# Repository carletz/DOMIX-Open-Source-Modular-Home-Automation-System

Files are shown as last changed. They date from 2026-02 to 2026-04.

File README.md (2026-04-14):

<div align="center">
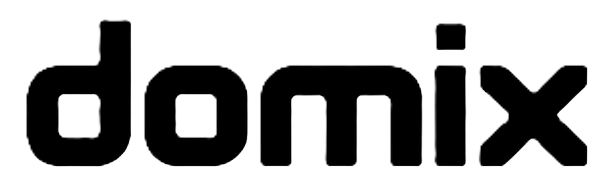
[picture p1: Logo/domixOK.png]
    
</div>

# DOMIX - Open Source Modular Home Automation System

## 📋 Table of Contents

- [Introduction](#-introduction)
- [The DOMIX Manifesto](#-the-domix-manifesto)
- [System Architecture](#-system-architecture)
- [Available Modules](#-available-modules)
- [PCB Composition](#-pcb-composition)
- [Technical Specifications](#-technical-specifications)
- [Getting Started](#-getting-started)
- [DOMIX ESPHome Software](#-domix-esphome-software)
- [Comparison with Other Systems](#-comparison-with-other-systems)
- [License & Disclaimer](#-license--disclaimer)
- [Documentation, Contributing, Contact & Acknowledgments](#-documentation)

---
> [!NOTE]
> **Please read the Full Technical Manual:** [Technical Documentation PDF](/Docs/DOMIX_Technical_Documentation_EN.pdf) to understand the project's full potential and features, below is just a summary of the project's features.
> 
> **Oshwlab Stars 2026 Page:** [DOMIX](https://oshwlab.com/carletz.slug/domix-domotic-module-for-smart-home-co)
---

## 🎯 Introduction

For several years, I have been managing the equipment in my home using automated systems that report all necessary information to a central controller, both for operational control and for data analysis.

These tools have only recently evolved, perhaps a decade or so for the consumer sector. Logic controllers, on the other hand, have been around for decades, but I don't think they'll easily become usable by a simple enthusiast like me, both due to their cost and their architecture.

As I've evolved my systems day by day, I've realized—unfortunately, too late, given that the learning curve for self-taught software is always very steep—that the best system, in my opinion, is always a centralized one.
After experimenting with both centralized and distributed approaches, the conclusion is clear: having everything converges into a single control point offers decisive advantages.

Many commercial solutions offer hybrid approaches, but excluding well-known and expensive systems, I could not find a simple solution capable of offering everything within a single device. From this need, the DOMIX project was born combining prior experience in electronics and automation into a single coherent ecosystem.

The idea is to concentrate the control logic inside a dedicated electrical cabinet, interfacing with actuators and safety switches belonging to the main electrical panel. This cabinet is not a conventional electrical panel, but a control cabinet designed to host automation logic and low-voltage control devices. The electrical power panel is not part of the DOMIX project; it relies on qualified electricians to connect the DOMIX system to the real world.

Yes, I know what you're thinking: who knows how many wires I have to run in my house! Or: how can I modify an existing system now? Well, I agree with you, this system is ideal if you're starting from scratch. If I don't yet have any conduit or corrugated pipes inside my walls, that's true, but in my opinion, even on a small scale, it can be adapted to many situations. On the other hand, imagination is a big part of the job of those who start thinking up similar systems on their own.

By centralizing all control wiring—both inputs (buttons, switches) and outputs (actuators, relays, contactors)—the system remains organized, flexible, and ready for complex logic and future expansion.

### Key Features

DOMIX is an **open-source, modular, DIN-rail home automation system** designed for centralized control and monitoring. Born from years of personal experience with home automation, DOMIX combines the structured approach of industrial systems with the flexibility of DIY platforms.

- ✅ Fully modular DIN-rail design
- ✅ Centralized logic with decentralized I/O
- ✅ Native Ethernet + Zigbee support
- ✅ ESPHome-based programming
- ✅ Open hardware & software
- ✅ No vendor lock-in
- ✅ Low-voltage safety (12V DC max)

## 📜 The DOMIX Manifesto

DOMIX is built on **10 core principles**:

1. **Open by Design** - All schematics and documentation are open source
2. **No Competition with Industrial Systems** - Research platform, not certified product
3. **Research, Not Certification** - Built for learning and experimentation
4. **Modular or Nothing** - Only M1 is mandatory, everything else is optional
5. **Cabinet-Oriented, Low-Voltage Only** - Never drives power loads directly
6. **Ethernet First, Always** - Wired reliability over wireless dependency
7. **Open Ecosystem Integration** - Works with Home Assistant, ESPHome, MQTT
8. **Zigbee as a First-Class Citizen** - Native Zigbee coordinator capability
9. **Fully Customizable by Design** - Firmware and logic can be freely modified
10. **Built for People Who Want to Understand** - Transparency over abstraction

> [!IMPORTANT]
> **DOMIX exists because building things is still fun. If it teaches something, it has succeeded.**

## 🏗️ System Architecture

<div align="center">
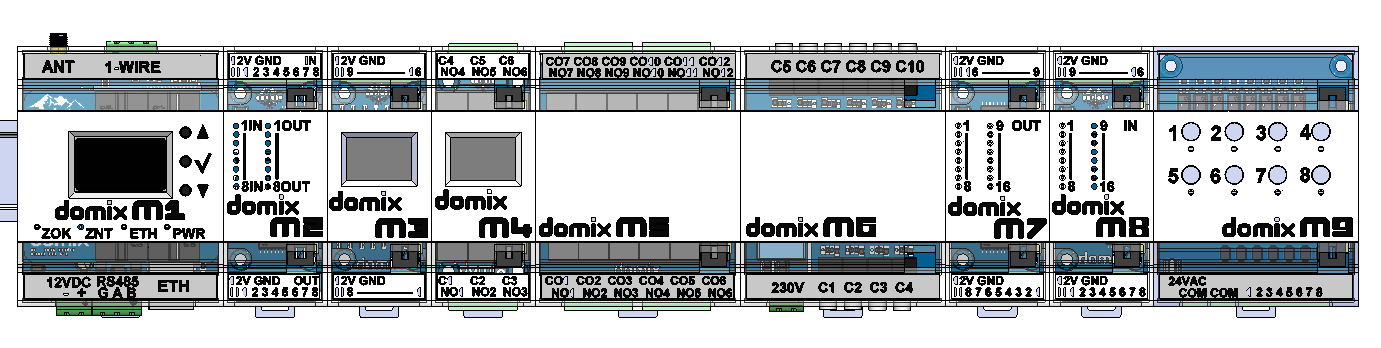
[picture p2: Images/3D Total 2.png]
    
</div>

### Modular Design

DOMIX uses a **centralized core (M1)** with specialized I/O expansion modules connected via **I2C bus**. All modules mount on standard 35mm DIN rail.

### Connection System

- **Power & Data:** 8-pin IDC flat cables
- **I2C Bus:** Two independent buses (expandable to 8 with M1 v1.1)
- **Communications:** Ethernet (primary), Zigbee, RS485

### I2C Address Management

The system carefully manages I2C address space across three ranges:

| Range | Used For | Max Devices |
|---|---|---|
| 0x20–0x27 | PCA9554A, PCA9535 | 8 |
| 0x38–0x3F | PCA9554A, PCF8574, PCA9535 | 8 |
| 0x48–0x4B | ADS1115 (ADC) | 4 |

## 🧩 Available Modules

### Core Module

| Module | Function | DIN Width | Description |
|---|---|---|---|
| **M1** | Core/Gateway | 4 modules | ESP32-S3, Ethernet, Zigbee, RS485, I2C hub |

<div align="center">
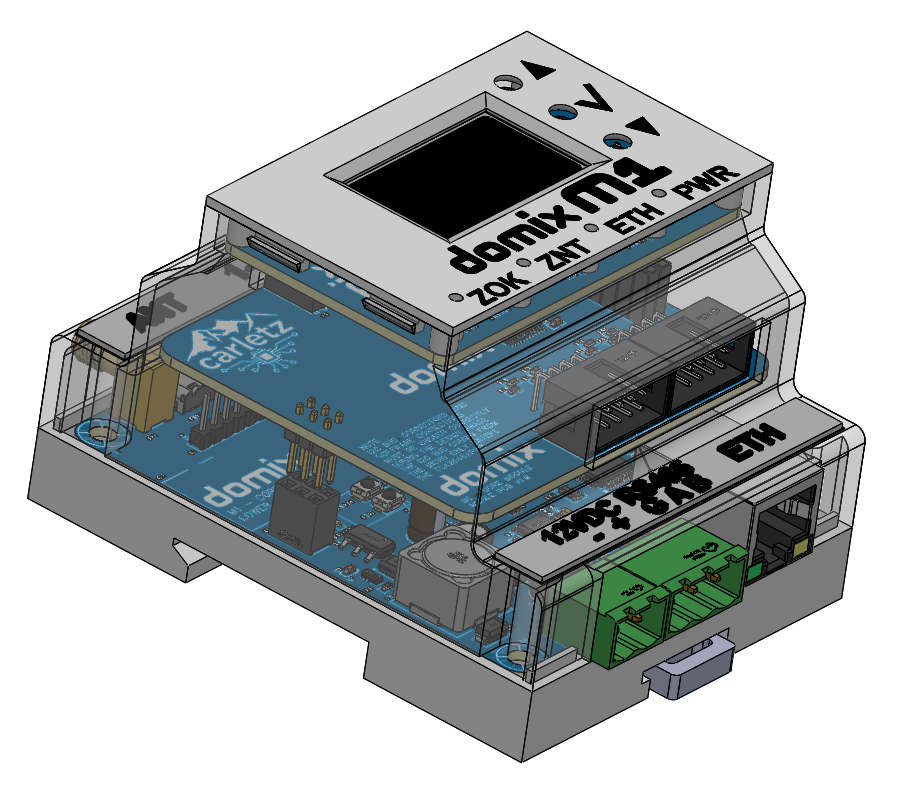
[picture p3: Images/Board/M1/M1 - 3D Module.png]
    
</div>

### I/O Modules

| Module | Function | DIN Width | I/O Count | Description |
|---|---|---|---|---|
| **M2** | General I/O | 2 modules | 8 in / 8 out | Optocoupled inputs, Darlington outputs |
| **M3** | Door/Window Contacts | 2 modules | 16 analog in | Analog multiplexer for reed switches |
| **M7** | Digital Output | 2 modules | 16 out | General purpose 12V outputs |
| **M8** | Digital Input | 2 modules | 16 in | General purpose optocoupled inputs |

<div align="center">
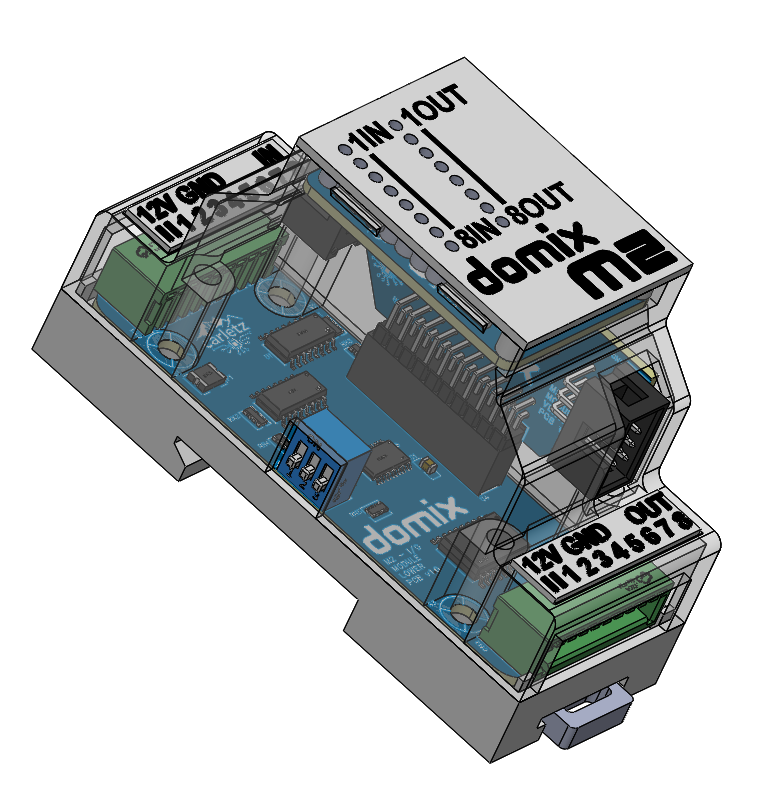
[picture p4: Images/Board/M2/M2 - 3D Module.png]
    
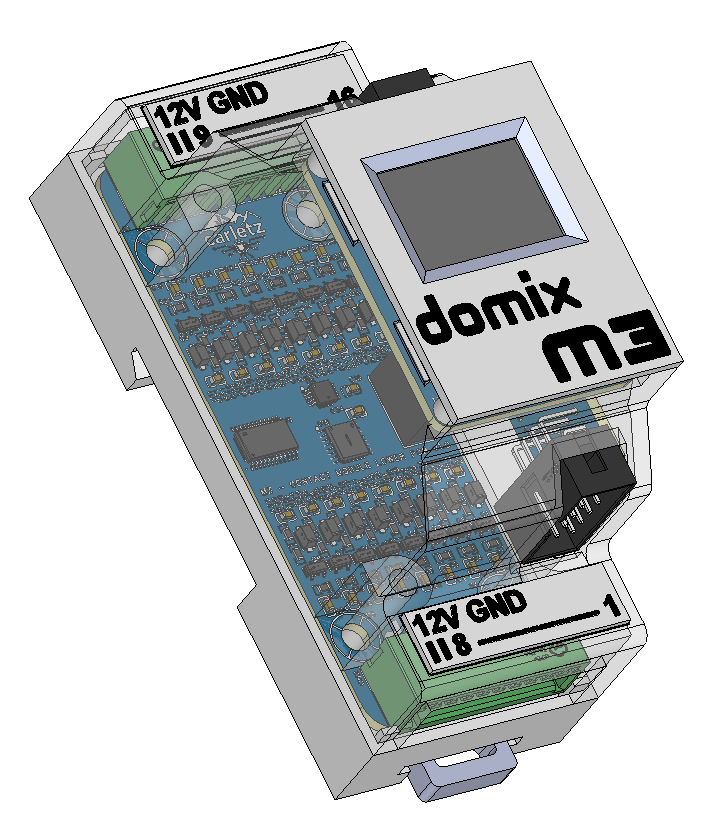
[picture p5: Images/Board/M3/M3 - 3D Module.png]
    
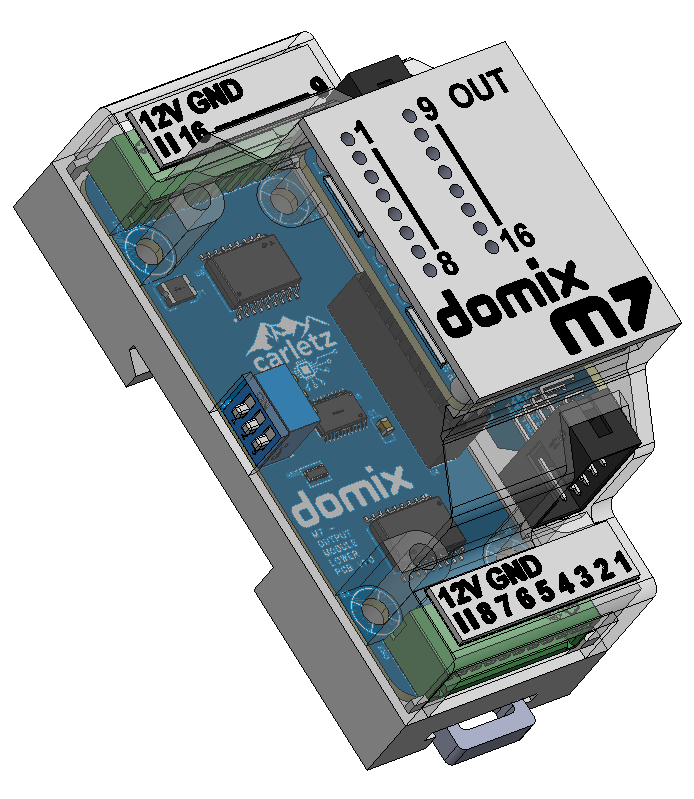
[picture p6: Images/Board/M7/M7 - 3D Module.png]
    
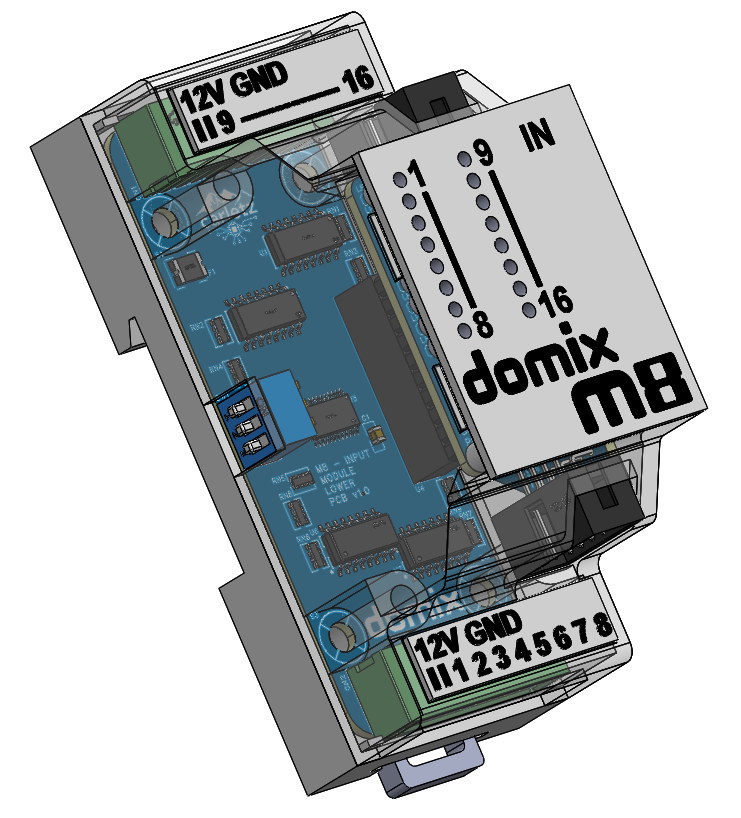
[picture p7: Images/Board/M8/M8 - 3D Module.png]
    
</div>

### Relay Modules

| Module | Function | DIN Width | Relays | Description |
|---|---|---|---|---|
| **M4** | 6-Relay | 2 modules | 6 | 10A @ 250VAC relays |
| **M5** | 12-Relay | 4 modules | 12 | 10A @ 250VAC relays |

<div align="center">
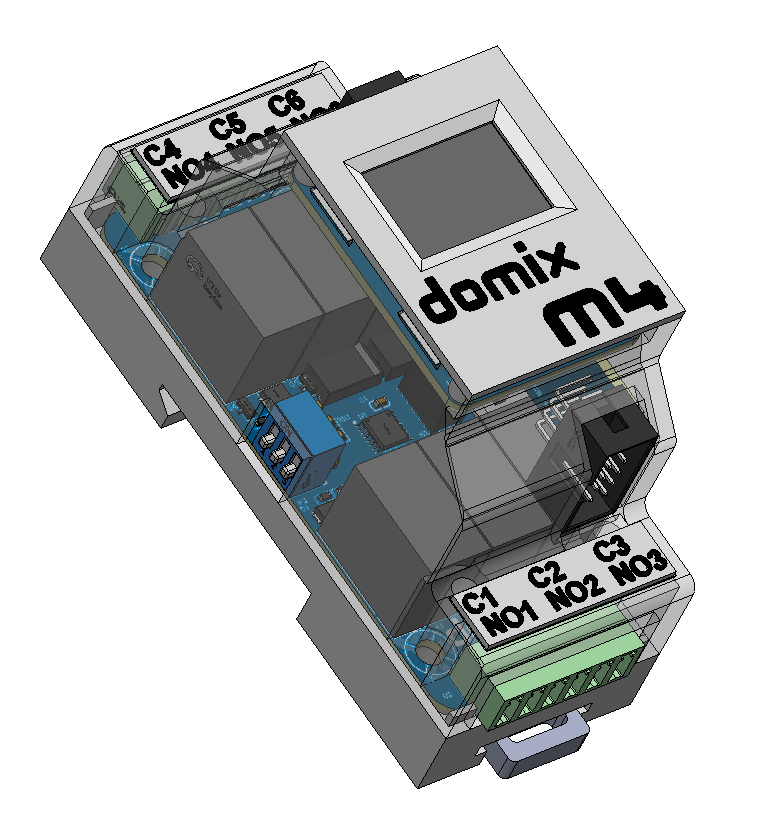
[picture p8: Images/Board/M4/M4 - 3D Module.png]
    
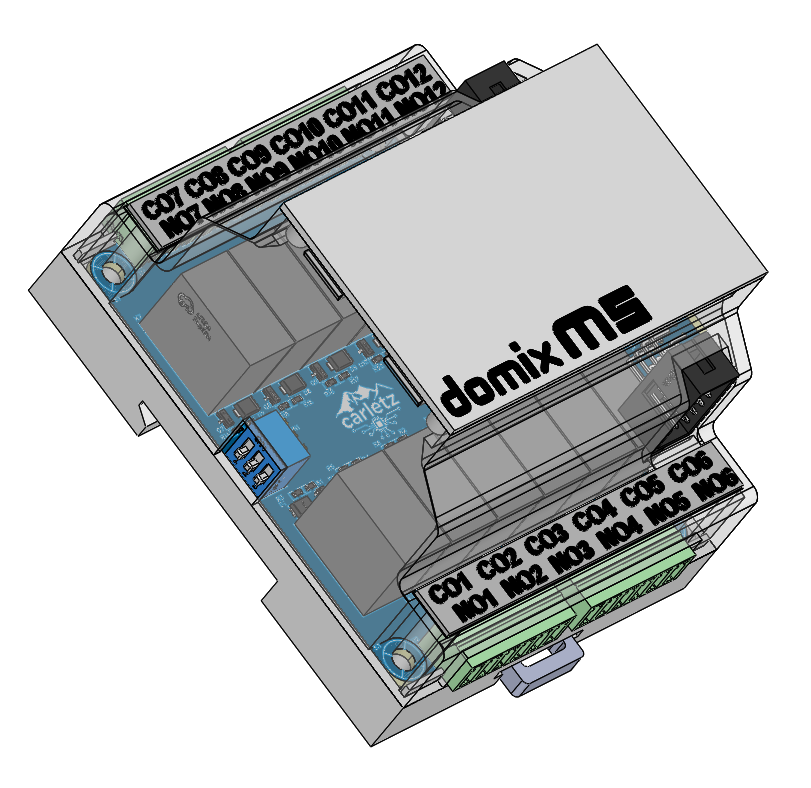
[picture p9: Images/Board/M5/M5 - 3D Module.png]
    
</div>

### Specialized Modules

| Module | Function | DIN Width | Description |
|---|---|---|---|
| **M6** | Energy Meter | 4 modules | 10-channel current clamp meter |
| **M9** | Sprinkler Controller | 4 modules | 8-zone sprinkler control with 24VAC output |

<div align="center">
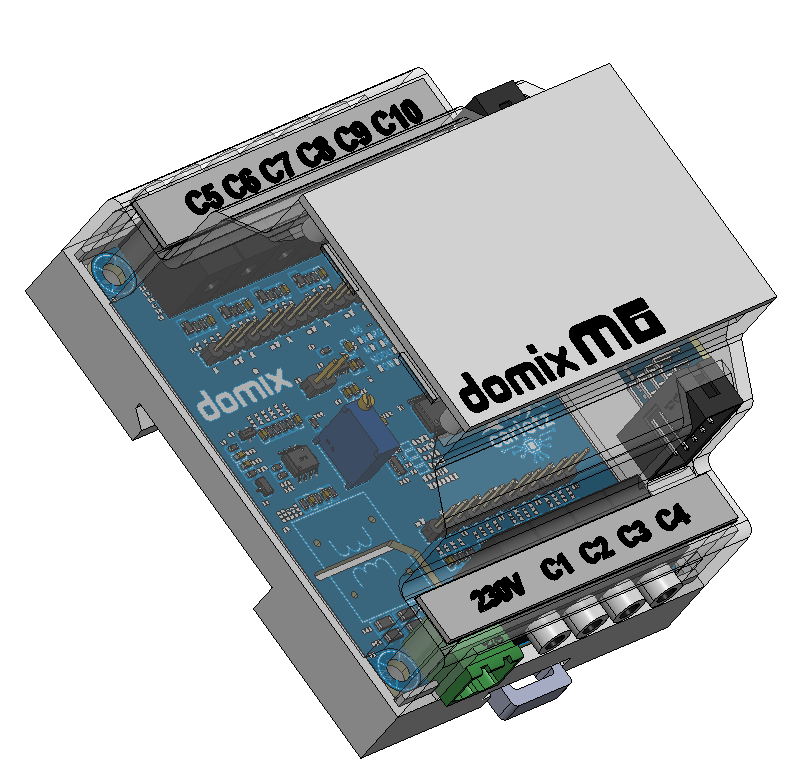
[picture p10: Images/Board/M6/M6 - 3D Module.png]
    
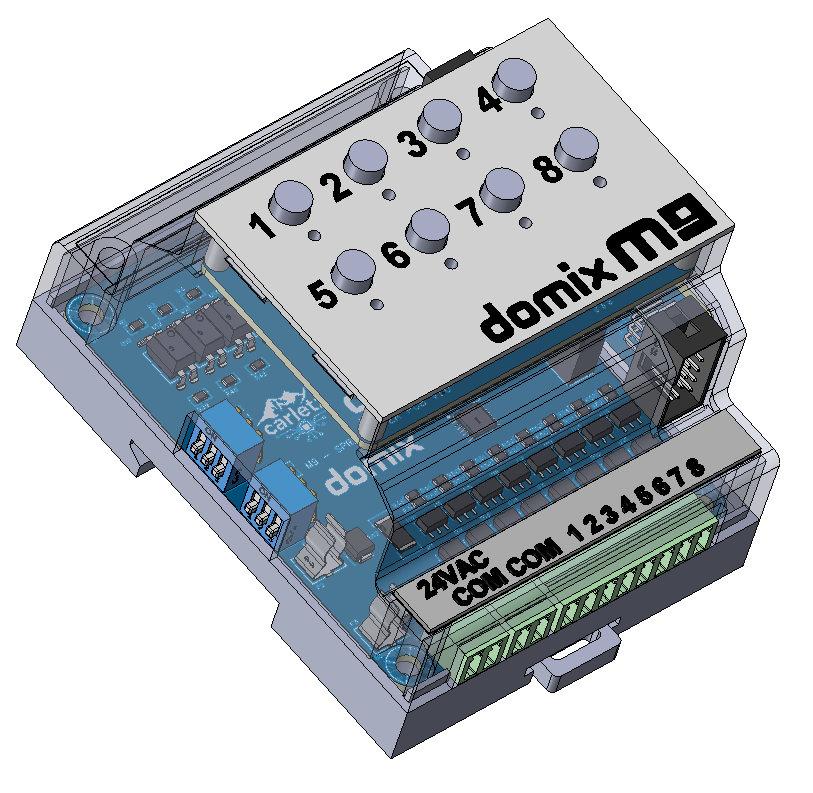
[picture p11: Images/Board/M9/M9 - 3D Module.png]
    
</div>

### Sensor Modules

The DOMIX sensor family consists of a shared **S Core board** combined with interchangeable **sensor daughter boards** designed for different installation scenarios and use cases. The S Core is always required and is identical across all configurations; only the daughter board and the 3D-printed enclosure change. Not all sensors need to be populated on any given board — every component is independently optional and the final build is entirely up to the user.

There are four possible configurations arising from two independent choices: installation type (ceiling or wall 503-box) and sensor/interface trade-off within each form factor.

| Configuration | Installation | LD2410C | PIR | BME280 | SCD41 | SGP41 | BH1750 | OLED + Encoder | IR TX | IR RX |
|---|---|:---:|:---:|:---:|:---:|:---:|:---:|:---:|:---:|:---:|
| **S Core + S1a** | Ceiling – mmWave | ✓ | – | ✓ | ✓ | ✓ | ✓ | – | ✓ | ✓ |
| **S Core + S1b** | Ceiling – PIR | – | ✓ | ✓ | ✓ | ✓ | ✓ | – | ✓ | ✓ |
| **S Core + S2a** | Wall 503 – Display | ✓ | – | ✓ | – | ✓ | – | ✓ | – | ✓ |
| **S Core + S2b** | Wall 503 – Sensors | ✓ | – | ✓ | ✓ | ✓ | ✓ | – | – | ✓ |

✓ = included in this variant &nbsp;&nbsp; – = not available in this variant

<div align="center">
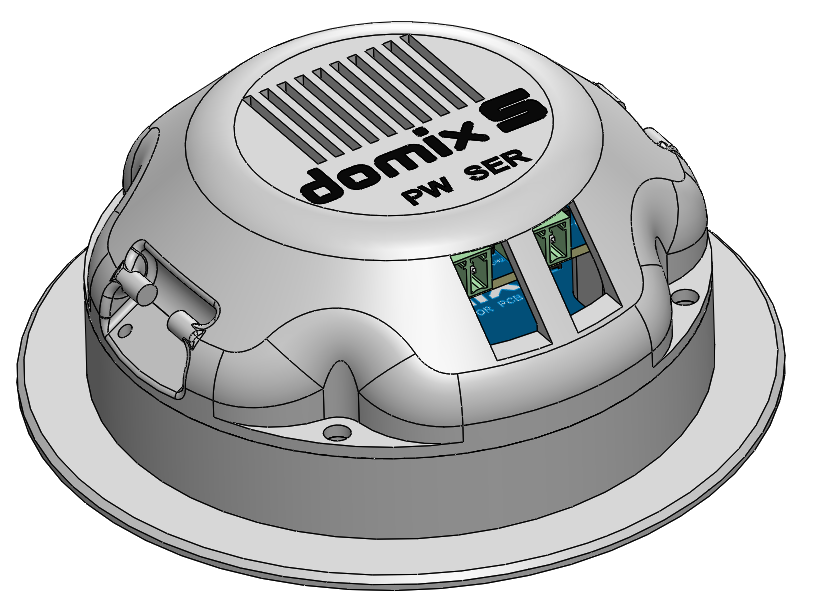
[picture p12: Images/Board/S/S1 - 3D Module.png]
    
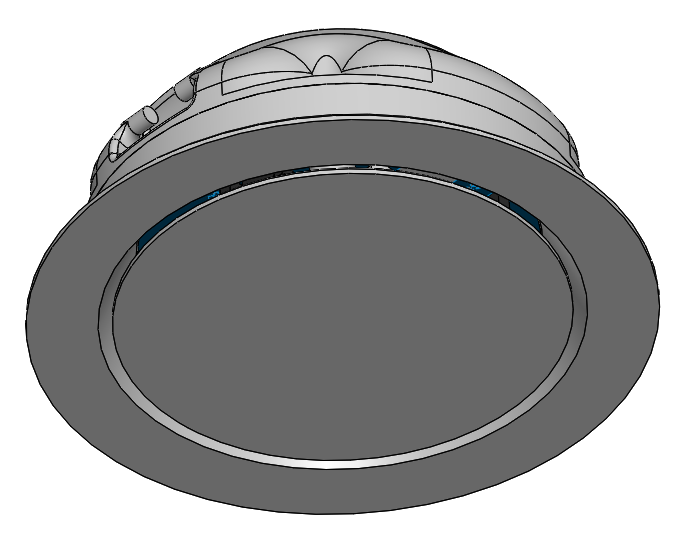
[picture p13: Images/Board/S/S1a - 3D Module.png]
        
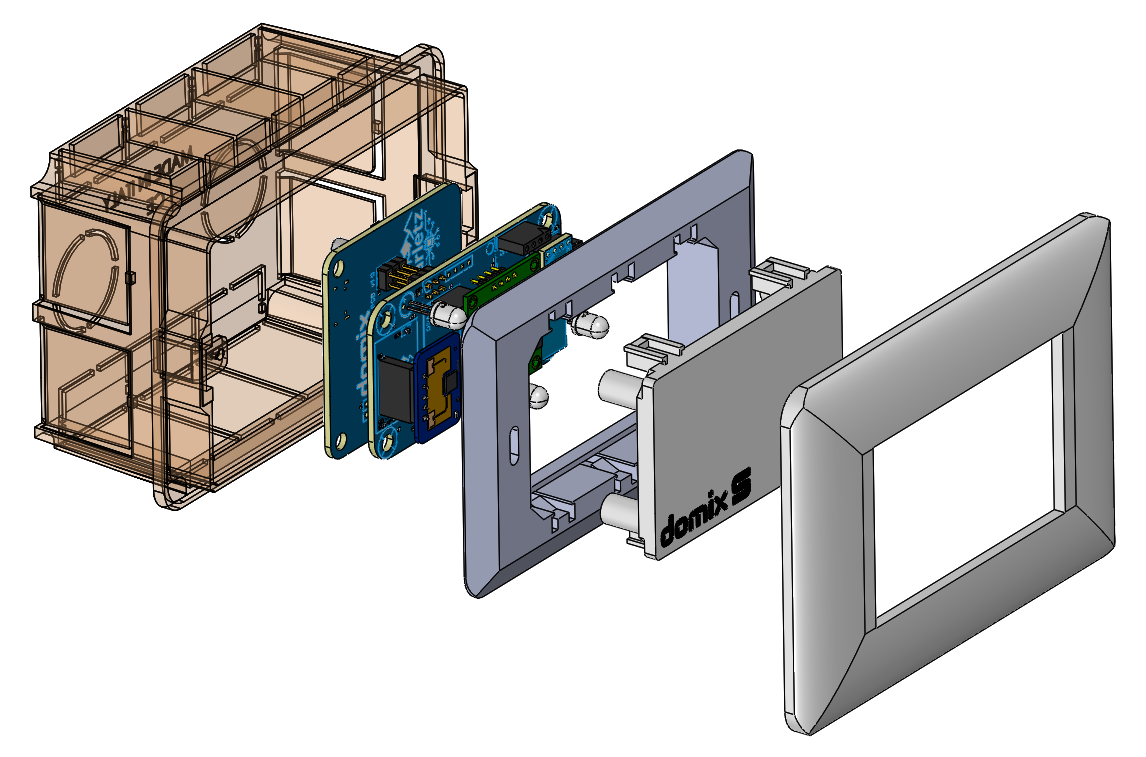
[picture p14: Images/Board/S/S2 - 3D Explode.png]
    
</div>

**Choosing the right variant:**
- **S1a / S2a (mmWave)** — best for living rooms and bedrooms where detecting stationary presence matters (e.g. someone sitting and reading). The LD2410C radar detects static occupancy reliably where PIR cannot.
- **S1b (PIR)** — simpler and lower cost, adequate for corridors, entrances, or secondary rooms where motion detection is sufficient.
- **S2a (Display)** — ideal when local interaction is needed, such as a wall-mounted thermostat or a room controller with manual input via the rotary encoder. Trades SCD41 and BH1750 for the OLED + encoder interface.
- **S2b (Sensors)** — best for rooms where air quality monitoring is the priority (bedroom, home office, kitchen): adds CO₂ (SCD41) and light (BH1750) on top of temperature, humidity, and VOC.

All configurations share the same S Core: RP2040 microcontroller, USB-C programming, 12V power input, and RS485 communication back to the DOMIX M1.

## 🧱 PCB Composition

Each DOMIX module is not a single PCB but a **stack of multiple boards** that snap together via IDC flat cables. Understanding which boards make up each module helps you know what to order, build, and assemble.

The boards are divided into three roles:

- **Vertical Module** — carries power and I2C bus connectors.
- **Display Module** — an optional front-facing board with the OLED screen and encoder/button interface.
- **Functional Module** — the core board specific to each module's purpose (I/O, relay, energy metering, etc.).

Some boards are shared between multiple module numbers to reduce design complexity and PCB variants.

### Cabinet Modules (M-series)

| Module | Vertical | Display | Functional Board(s) | Notes |
|---|---|---|---|---|
| **M1** | Middle Module v1.0 + v1.1 | Display Module | Core Module | Middle module acts as mid-layer between core and vertical; v1.1 adds second I2C multiplexer |
| **M2** | Vertical Module | Display Module | I-O Module | 8 in / 8 out general I/O |
| **M3** | Vertical Module | Display Module | Contact Module | 16-channel analog contact reader |
| **M4** | *(shared M3-4)* | *(shared M3-4)* | 6 Relay Module | Vertical and display boards are shared with M3 |
| **M5** | *(shared M3-4-5-6)* | *(shared M5-6)* | 12 Relay Module | Vertical shared across M3/M4/M5/M6; display shared with M6 |
| **M6** | *(shared M3-4-5-6)* | *(shared M5-6)* | Energy Meter Module | Same vertical and display as M5 |
| **M7** | Vertical Module | Display Module | Output Module | 16 digital outputs |
| **M8** | Vertical Module | Display Module | I-O Module | 16 digital inputs (same I-O board as M2, different config) |
| **M9** | Vertical Module | Upper Module | Sprinkler Module | Upper Module replaces the display, handles 24VAC switching |

> **Shared boards explained:** The label `M3-4` on a board means that PCB is used in both M3 and M4. Similarly `M3-4-5-6` is a single vertical design that fits M3 through M6, and `M5-6` is a display shared between M5 and M6. This reduces the number of unique PCB designs without limiting functionality.

### Sensor Modules (S-series)

The sensor family follows a **core + daughter board** approach. The S Core is always present; the S1 or S2 board changes depending on installation type.

| Board | Role | Description |
|---|---|---|
| **S Core** | Main board | RP2040 MCU, RS485, USB-C, 12V input — identical in every sensor node |
| **S1** | Daughter board | Ceiling form factor — fits LD2410C (mmWave) or PIR depending on variant |
| **S2** | Daughter board | Wall 503-box form factor — fits OLED+encoder or additional sensors depending on variant |

Each sensor node = **1× S Core + 1× S1 or S2 daughter board**, housed in a dedicated 3D-printed enclosure.

## 🔧 Technical Specifications

### M1 Core Module

- **MCU:** ESP32-S3-WROOM-1-N8R2 (dual-core, Wi-Fi, USB-C)
- **Ethernet:** W5500 controller, 10/100 Mbps
- **Zigbee:** RF-BM-2652P2 (TI CC2652, external antenna)
- **RS485:** MAX13487E transceiver with TVS protection
- **Power:** 9-12V DC input, 5V/3.3V internal rails
- **I2C:** 2 buses (expandable to 8 with TCA9548A)
- **Display:** Optional 1.3" OLED (128×64, SH1106)

### Power Requirements

- **System Logic:** 3.3V @ <500mA
- **Relay Coils:** 5V (total system max 2A)
- **External Control:** 12V DC

### Mechanical

- **PCB Layers:** 2-4 layer depending on module
- **Enclosure:** 3D-printed, standard DIN dimensions
- **Connection:** IDC flat cables (1mm pitch)
- **Terminals:** Removable screw blocks (max 1.5mm²)

## 🚀 Getting Started

### Prerequisites

- Basic electronics knowledge
- Soldering skills
- 3D printer (for enclosures)
- ESPHome environment
- 12V DC power supply

### Building Your First System

1. **Minimum Configuration:**
   - 1× M1 Core module
   - 12V DC power supply
   - Ethernet cable

2. **Recommended Starter Kit:**
   - 1× M1 Core
   - 2× M2 General I/O
   - 1× M4 6-Relay
   - Power supply + cables

3. **Assembly Steps:**
   - Configure I2C addresses on expansion modules
   - Program ESP32 via USB-C with ESPHome
   - Flash Zigbee firmware to RF-BM-2652P2
   - Connect modules with IDC cables
   - Mount on DIN rail

### I2C Address Planning

**Critical:** Plan addresses before assembly to avoid conflicts.

Example configuration:
```
M1: Core (no address)
M2 #1: 0x20
M2 #2: 0x21
M4: 0x38
M3: 0x39 + ADS1115 @ 0x48
```

Check section 4.4 of manual for detailed address planning guidelines.

## 💻 DOMIX ESPHome Software

> ESPHome firmware for the DOMIX modular home automation system.

DOMIX is split into two independent firmware targets:

- **M** — Cabinet controller (ESP32), manages I/O modules, relays, shutters, energy metering and communicates with sensor nodes via RS485/Modbus RTU.
- **S** — Room sensor node (RP2040), collects environmental data (temperature, humidity, CO₂, VOC, presence…) and exposes it to the M controller over Modbus RTU.

### Getting Started

Both targets follow the same workflow:

1. **Edit `hardware/data.yaml`** — set your device name, network/MQTT credentials, I2C addresses and Modbus address. This is the only file you need to touch before compiling.
2. **Edit `main.yaml`** — comment out any hardware module or sensor not physically present.
3. **Flash via USB-C**: `esphome run M/main.yaml` or `esphome run S/main.yaml`. Subsequent updates of M1 module can be done OTA, S module have to be programmed only via USB-C.

### Key Features

- Modular architecture — include only what you install.
- Wired Ethernet (W5500), MQTT, OTA updates, OLED display and button menu on the M1.
- Room sensors: BME280, BH1750, SCD41 (CO₂), SGP41 (VOC/NOx), LD2410 mmWave radar, PIR, IR transceiver.
- RS485/Modbus RTU link between M and S nodes (one `modbus_master.yaml` include per room).
- Optional Zigbee coordinator (CC2652) — requires ESPHome ≤ 2025.x.

### Repository Layout

```
Software/
├── M/          # Cabinet controller firmware (ESP32)
│   ├── hardware/   # Board, Ethernet, MQTT, I2C, OTA, screen…
│   ├── module/     # One file per expansion module (M1–M9)
│   └── sensor/     # DS18B20 wire sensor + Modbus master template
└── S/          # Room sensor node firmware (RP2040)
    ├── hardware/   # Board, I2C, Modbus slave…
    ├── sensor/     # BME280, BH1750, SCD41, SGP41, LD2410, PIR, IR…
    └── font/       # OLED fonts
```

Full wiring, register map, MQTT topic convention and menu reference are documented in the [extended README](docs/README.md).

### Zigbee Setup

> [!WARNING]
> ESPHome version 2026 is **<ins>not compatible</ins>** with the external Zigbee component, so if you need to use it you must compile it with a maximum version of 2025. I used 2025.7.5. If you don't need it, you can use the latest version.

The RF-BM-2652P2 module requires Z-Stack firmware. See [POE Zigbee Coordinator](https://github.com/carletz/POE-Zigbee-Coordinator) for flashing instructions.

### Integration Examples

- **Home Assistant:** MQTT/Native API
- **Node-RED:** MQTT broker
- **OpenHAB:** MQTT binding
- **Custom:** Direct ESPHome API

## 📊 Comparison with Other Systems

| Feature | DOMIX | KNX | Shelly/Sonoff | Industrial PLC |
|---|---|-----|---|---|
| **Architecture** | Centralized core | Fully distributed | Device-based | Centralized |
| **DIN Rail** | Native | Yes | Partial | Yes |
| **Programming** | ESPHome (open) | ETS (licensed) | App/Cloud | Vendor IDE |
| **Vendor Lock-in** | None | High | Medium-High | High |
| **Entry Cost** | Low-Medium | High | Low | Very High |
| **Wireless** | Zigbee native | Optional | Wi-Fi | Rare |
| **Certification** | None (research) | Full | Consumer | Industrial |

### Where DOMIX Makes Sense

✅ You want full control over firmware and logic  
✅ You prefer wired reliability  
✅ You need clean DIN-rail cabinet integration  
✅ You want to understand and customize your system  
✅ Energy monitoring is important  
✅ You need multi-sensor room monitoring (air quality, presence, light, IR) in a single node  

### Where DOMIX Is NOT Suitable

❌ Formal building certification required  
❌ Extremely large installations (100+ nodes)  
❌ Plug-and-play is the primary goal  
❌ Production environment without validation  

## 📄 License & Disclaimer

**Version:** 1.3  
**Last Updated:** April 2026  
**DOMIX © 2026 by carletz**  
Licensed under [CC BY-NC-SA 4.0](https://creativecommons.org/licenses/by-nc-sa/4.0/)

### Terms

- ✅ **Attribution** required
- ✅ **Share Alike** - derivative works must use same license
- ❌ **Non-Commercial** - commercial use not permitted
- ✅ Modifications and derivatives allowed

### Disclaimer

This project is provided **as-is** for educational and experimental purposes.

- ⚠️ Not certified for production use
- ⚠️ All electrical connections must be done by qualified personnel
- ⚠️ No warranties or guarantees provided
- ⚠️ User assumes all risks

**Always follow local electrical codes and safety regulations.**

## 📚 Documentation

- **Full Manual:** [Technical Documentation PDF](https://github.com/carletz/DOMIX-Open-Source-Modular-Home-Automation-System/blob/main/Docs/DOMIX_Technical_Documentation_EN.pdf)
- **Schematics, Gerbers, Pick and place and Interactive BOM:** Available in each module directory
- **BOM:** Available in [BOM](https://github.com/carletz/DOMIX-Open-Source-Modular-Home-Automation-System/tree/main/BOM) directory
- **3D Models:** Available in [3D Print files](https://github.com/carletz/DOMIX-Open-Source-Modular-Home-Automation-System/tree/main/3D%20Print%20files) directory
- **ESPHome Examples:** Available in [Software](https://github.com/carletz/DOMIX-Open-Source-Modular-Home-Automation-System/tree/main/Software)

## 🤝 Contributing

Contributions are welcome! Please:

1. Fork the repository
2. Create a feature branch
3. Commit your changes
4. Open a pull request

## 📞 Contact & Support

- **GitHub Issues:** For bug reports and feature requests
- **Oshwlab Stars 2026 Page:** [DOMIX](https://oshwlab.com/carletz.slug/domix-domotic-module-for-smart-home-co)
- **Related Projects:**
  - [POE Zigbee Coordinator](https://github.com/carletz/POE-Zigbee-Coordinator)
  - [MultiSensor](https://github.com/carletz/MultiSensor)
  - [Sprinkler Boy](https://github.com/carletz/Sprinkler-Boy)

## 🙏 Acknowledgments

- ESPHome community
- [Zigbee2MQTT](https://github.com/Koenkk/zigbee2mqtt) / [Z-Stack firmware](https://github.com/Koenkk/Z-Stack-firmware) by Koenkk
- [Zig Star](https://zig-star.com) for Zigbee tools

---

**Built with curiosity. Shared with transparency. Used with responsibility.**

If DOMIX teaches you something, it has succeeded. ✨

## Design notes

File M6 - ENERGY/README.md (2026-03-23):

# Module M6 ENERGY METER

<div align="center">
    
</div>

<div align="center">
    
    
</div>

## Overview
The DOMIX M6 module measures electrical consumption using clamp meters. It also measures the current mains voltage to accurately calculate the power used at the measurement points.

|Main info|	| M6|
|---|---|-----|
|Lower module|	Dimension|	67 x 84.4 mm|
|	|Layer	|2|
|Upper module|	Dimension|	67 x 41 mm|
|	|Layer	|2|
|Vertical module|	Dimension|	50.5 x 24 mm|
|	|Layer	|2|

## System Architecture
The architecture, with three PCBs connected together, is the same as the previous modules. The base has the main task of implementing the measurement logic, the vertical part is responsible for communication with the main module, and the upper part is responsible for the display.

Voltage measurement is performed via the ZMPT101B single-phase voltage transformer (AC voltage max. 250 volts) present at the input. The output signal is sinusoidal, conditioned by an operational amplifier (LM358), and centred around a DC offset of approximately 1.25V (VREF/2 generated by a CJ431 reference).

Current measurement is carried out through a conditioning circuit with an operational amplifier (LMV321) which generates a 1V DC bias, followed by an analog multiplexer CD74HC4067SM96 that probes all 10 available channels. Channel selection is handled by a PCA9554APW,118 I/O expander over I2C.

### ADC Architecture — ATtiny1616

Starting from hardware revision 1.1, the ADS1115 ADC previously used for both voltage and current measurement has been replaced by an **ATtiny1616 microcontroller** (QFN-20-EP, 3×3 mm). This change was necessary because the ADS1115 uses a sigma-delta converter that internally averages the input signal, making it unable to follow a 50 Hz AC waveform — it always returned the DC offset instead of the RMS value.

The ATtiny1616 uses a SAR ADC capable of over 75,000 samples per second, providing approximately 1,500 samples per 50 Hz cycle. It computes the RMS value internally using a two-pass algorithm (DC offset removal followed by RMS calculation) and exposes the results to the ESP32 via I2C, emulating the same address as the original ADS1115 (0x48).

#### ATtiny1616 Pin Assignment

| QFN pin | Port | Function | Connected to |
|---|---|---|---|
| 1  | PA2 | SCL (TWI0 default) | IIC_SCL |
| 9  | PB5 | AIN8 / ADC | READ (ZMPT101B voltage signal) |
| 10 | PB4 | AIN9 / ADC | ADCCOM (CT clamp current via MUX) |
| 19 | PA0 | UPDI | Programming pad (3-pin: VCC / GND / PA0) |
| 20 | PA1 | SDA (TWI0 default) | IIC_SDA |
| EP | — | Thermal pad | GND plane (mandatory) |

All other pins are left unconnected (NC).

#### I2C Register Map

| Register | R/W | Description |
|---|-----|---|
| 0x00 | R | Voltage RMS (float, 4 bytes big-endian) |
| 0x01 | R | Current RMS (float, 4 bytes big-endian) |
| 0x02 | W | Trigger new current acquisition (write 0x01) |
| 0x03 | R | Status: 0x00 = busy, 0x01 = ready |

#### Current Acquisition Protocol

Because the CD74HC4067 multiplexer channel is selected by ESPHome before each reading, current acquisition must be explicitly triggered to avoid reading stale samples from a previous channel:

1. ESPHome selects the channel on CD74HC4067 via PCA9554
2. ESPHome writes 0x01 to register 0x02 (TRIGGER)
3. ATtiny1616 clears its buffer and acquires a fresh RMS measurement
4. ESPHome polls register 0x03 until STATUS = 0x01 (ready)
5. ESPHome reads register 0x01 (current RMS result)

Voltage acquisition is continuous and requires no trigger — register 0x00 always returns the latest computed value.

#### ADC Reference and Signal Range

The ATtiny1616 uses the internal 2.5V reference (INTERNAL2V5). Signal ranges at the ADC inputs are:

| Signal | DC offset | AC swing (peak) | Min | Max |
|---|---|---|-----|-----|
| READ (voltage) | 1.244V | ±0.707V | 0.537V | 1.951V |
| ADCCOM (current, CT 50A/1V) | 0.643V | ±0.141V (at 5A) | 0.502V | 0.784V |

Clipping of the current signal begins above approximately 36A on a single channel.

#### Firmware

The ATtiny1616 is programmed using Arduino IDE with the **megaTinyCore** board package. Clock is set to 10 MHz internal (safe maximum at 3.3V per datasheet). Calibration factors `CAL_VOLTAGE` and `CAL_CURRENT` are defined as compile-time constants and must be updated after initial measurement against a reference meter, then re-flashed via UPDI.

Programming interface: any USB-Serial adapter (CH340, CP2102) with a **470Ω resistor** between TX and the UPDI pad. No reset or boot button required.

Arduino IDE settings:
- Board: `ATtiny1616`
- Clock: `10 MHz Internal`
- Programmer: `SerialUPDI - SLOW: 57600 baud`

## PCA9554A I/O Expander — Address Selection

The PCA9554A controls the 4 address lines (S0–S3) of the CD74HC4067 multiplexer. Its I2C address is set via the DIP switch SW1 on the side of the board:

|Address | A2 | A1 | A0 |
|---|----|----|-----|
| 0x38 | 0  | 0  | 0  |
| 0x39 | 0  | 0  | 1  |
| 0x3A | 0  | 1  | 0  |
| 0x3B | 0  | 1  | 1  |
| 0x3C | 1  | 0  | 0  |
| 0x3D | 1  | 0  | 1  |
| 0x3E | 1  | 1  | 0  |
| 0x3F | 1  | 1  | 1  |

The same table is reproduced as silkscreen on the back of the PCB.

## ATtiny1616 I2C Address Selection

The ATtiny1616 I2C address is defined in firmware (`Wire.begin(0x48)` by default). If address 0x48 conflicts with another device on the bus, change the `I2C_ADDRESS` define in the firmware and re-flash via UPDI.

## Power Supply Architecture
The module's control logic is powered by the IDC connector from the DOMIX M1 core module. The LM358 operational amplifier used for voltage measurement requires 5V, supplied from the same connector. The ATtiny1616 and all other control logic operate at 3.3V. The 1V DC bias for the current conditioning circuit is generated by the LMV321 operational amplifier configured as a voltage follower with a 22kΩ/10kΩ resistive divider from 3.3V.

## User Interface & Display Module
A user interface made with a display identical to the DOMIX M1 module is foreseen in the project. Its use should be carefully evaluated due to the limited number of available I2C addresses on the bus. Adding another I2C screen could cause address conflicts; each installation should be planned case by case.

## Mechanical Structure
Like all other DOMIX modules, the DOMIX M6 system uses a stacked PCB architecture: the lower PCB contains the core electronics, the vertical PCB provides mechanical and electrical interconnect, and the upper PCB houses the human interface. This structure minimises footprint, improves maintainability, and allows for future UI or expansion board development.

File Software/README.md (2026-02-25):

# DOMIX ESPHome Software

> ESPHome firmware for the DOMIX modular home automation system.  
> The project is split into two independent firmware targets: **M** (Main/Cabinet module) and **S** (Sensor node).

---

## Repository Structure

```
Software/
├── M/                          # Firmware for DOMIX M1 (ESP32-based cabinet controller)
│   ├── main.yaml               # Entry point — include the packages you need
│   ├── hardware/               # Hardware abstraction packages
│   │   ├── data.yaml           # ⭐ Master substitutions file (IP, MQTT, I2C addresses…)
│   │   ├── esp.yaml            # ESP32 board definition
│   │   ├── ethernet.yaml       # Wired Ethernet (W5500 or similar)
│   │   ├── i2c.yaml            # I2C bus — use with M1 v1.0
│   │   ├── i2c_switch.yaml     # I2C bus with switch — use with M1 v1.2 (mutually exclusive with i2c.yaml)
│   │   ├── mqtt.yaml           # MQTT broker connection
│   │   ├── web_server.yaml     # Built-in ESPHome web server
│   │   ├── ota.yaml            # Over-the-air update support
│   │   ├── restart.yaml        # Safe restart button entity
│   │   ├── info.yaml           # Device info sensors (uptime, IP…)
│   │   ├── log.yaml            # Log level configuration
│   │   ├── screen.yaml         # OLED screen (SH1106 128×64 on M1)
│   │   ├── time.yaml           # SNTP time synchronisation
│   │   ├── uart.yaml           # UART for RS485 / serial bridge
│   │   └── zigbee.yaml         # Zigbee coordinator (CC2652, max ESPHome 2025.x)
│   ├── module/                 # One YAML file per expansion module
│   │   ├── m1.yaml             # M1 — OLED display + analogue button menu
│   │   ├── m2.yaml             # M2 — 8-input / 8-output I/O (PCA9554)
│   │   ├── m3.yaml             # M3 — Dry contacts + ADS1115 analogue inputs
│   │   ├── m4.yaml             # M4 — 6-relay output board
│   │   ├── m4_shutters.yaml    # M4 — 6-relay configured as 3 shutter pairs
│   │   ├── m5.yaml             # M5 — 12-relay output board
│   │   ├── m5_shutters.yaml    # M5 — 12-relay configured as 6 shutter pairs
│   │   ├── m6.yaml             # M6 — Single-phase energy meter (ZMPT101B + ADS1115)
│   │   ├── m7.yaml             # M7 — Generic output board
│   │   ├── m8.yaml             # M8 — Generic input board
│   │   └── m9.yaml             # M9 — Sprinkler/valve controller
│   └── sensor/
│       ├── wire.yaml           # DS18B20 1-wire temperature sensor (optional, on M1)
│       └── modbus_master.yaml  # ⭐ Reusable template — reads one DOMIX S sensor node via RS485
│
└── S/                          # Firmware for DOMIX S (RP2040-based room sensor node)
    ├── main.yaml               # Entry point — include the sensor packages you need
    ├── hardware/               # Hardware abstraction packages
    │   ├── data.yaml           # ⭐ Master substitutions file (Modbus address, sensor I2C addresses, IR codes…)
    │   ├── rp2040.yaml         # RP2040 board definition
    │   ├── i2c.yaml            # I2C bus for sensors
    │   ├── modbus.yaml         # Modbus RTU slave (RS485 to M1)
    │   ├── modbus_interval.yaml# Modbus polling interval
    │   ├── modbus_slave.h      # C++ helper for Modbus slave register mapping
    │   ├── serial.yaml         # UART / serial bridge settings
    │   └── log.yaml            # Log level configuration
    ├── sensor/                 # One YAML file per physical sensor
    │   ├── bme280.yaml         # Temperature / Humidity / Pressure (I2C)
    │   ├── bh1750.yaml         # Ambient light in lux (I2C)
    │   ├── scd41.yaml          # CO₂ photoacoustic sensor (I2C)
    │   ├── sgp41.yaml          # VOC + NOx index sensor (I2C)
    │   ├── ld2410.yaml         # 24 GHz mmWave presence radar (UART)
    │   ├── pir.yaml            # PIR passive motion sensor (GPIO)
    │   ├── remote_tran.yaml    # IR transmitter — NEC protocol (current)
    │   ├── remote_rec.yaml     # IR receiver (not supported on ESPHome and RP2040 unfortunately)
    │   ├── screen.yaml         # SSD1306/SH1106 OLED screen output
    │   └── ir_transmitter_rp2040.h  # C++ NEC IR transmission helper
    └── font/                   # Embedded fonts for the OLED screen
        ├── Roboto-Regular.ttf
        ├── Roboto-Medium.ttf
        └── materialdesignicons-webfont.ttf
```

---

## Quick Start — M Firmware (Cabinet Controller)

### 1. Configure `hardware/data.yaml`

This is the **only file you must edit** before compiling. It contains all substitutions used across every package:

| Section | Key parameters |
|---|---|
| Board identity | `device_name`, `friendly_name`, `mqtt_name` |
| Network | `ethernet_IP`, `ethernet_gateway`, `ethernet_subnet` |
| MQTT | `mqtt_broker`, `mqtt_port`, `mqtt_username`, `mqtt_password` |
| Web server | `web_username`, `web_password` |
| Time | `timezone` (e.g. `Europe/Rome`) |
| OTA | `ota_password` |
| Module addresses | `m1_screen_address`, `m2_i2c_1`, `m3_i2c_1`, … (one block per module) |

> ⚠️ **Every I2C address must be unique on the bus.** Failing to set correct addresses will prevent the system from starting. Check the manual for the examples.

### 2. Edit `main.yaml` — select your modules

`main.yaml` uses ESPHome's `packages` / `!include` mechanism. Comment out any module you are not physically installing:

```yaml
packages:
  esp:        !include hardware/esp.yaml
  data:       !include hardware/data.yaml     # always required
  ethernet:   !include hardware/ethernet.yaml
  mqtt:       !include hardware/mqtt.yaml
  # Choose ONE of the two i2c packages depending on your M1 board revision:
  i2c:        !include hardware/i2c.yaml        # M1 v1.0
  # i2c:      !include hardware/i2c_switch.yaml # M1 v1.2

  m1:   !include module/m1.yaml       # OLED display + buttons
  m2:   !include module/m2.yaml       # 8-in / 8-out I/O
  # m3, m4, m5, m6 … add as needed
```

To add **S sensor nodes** (room sensors communicating over RS485), use the reusable `modbus_master.yaml` template — one block per sensor node, each with a unique Modbus address:

```yaml
  slave_living:
    <<: !include
      file: sensor/modbus_master.yaml
      vars:
        s_name: living
        s_name_upper: Living
        s_modbus_addr: "0x01"
        s_controller_id: modbus_slave1

  slave_bedroom:
    <<: !include
      file: sensor/modbus_master.yaml
      vars:
        s_name: bedroom
        s_name_upper: Bedroom
        s_modbus_addr: "0x02"
        s_controller_id: modbus_slave2
```

### 3. Flash via USB-C

Connect the USB-C port on the M1 board (do **not** connect external power simultaneously) and run:

```bash
esphome run M/main.yaml
```

Subsequent updates can be done OTA over the network.

---

## Quick Start — S Firmware (Room Sensor Node)

The S node runs on a Raspberry Pi RP2040. Its role is to collect all room sensor data and expose it to the M1 master over **Modbus RTU (RS485)**.

### 1. Configure `hardware/data.yaml`

| Parameter | Description |
|---|---|
| `modbus_address` | **Must be unique** for every S node on the RS485 bus (e.g. `0x01`, `0x02`, …) |
| `bh1750_addr` | `0x23` (ADDR=LOW) or `0x5C` (ADDR=HIGH) |
| `bme280_addr` | `0x76` or `0x77` depending on SDO pin |
| `nec_address` | NEC device address of the IR-controlled appliance |
| `nec_digit_0…9` | NEC command codes for digit keys |
| `nec_muto`, `nec_power`, … | NEC codes for special IR commands |

### 2. Edit `main.yaml` — enable/disable sensors

Comment out sensors not physically present on your daughter board:

```yaml
packages:
  - !include hardware/rp2040.yaml
  - !include hardware/data.yaml
  - !include hardware/modbus.yaml
  - !include sensor/bme280.yaml     # Temperature / Humidity / Pressure
  - !include sensor/bh1750.yaml     # Light
  - !include sensor/scd41.yaml      # CO₂
  - !include sensor/sgp41.yaml      # VOC / NOx
  - !include sensor/ld2410.yaml     # mmWave presence
  - !include sensor/pir.yaml        # PIR motion
  - !include sensor/remote_tran.yaml # IR transmitter
  # - !include sensor/remote_rec.yaml  # IR receiver (not supported on ESPHome and RP2040 unfortunately)
  - !include sensor/screen.yaml     # OLED display
```

### 3. Flash via USB-C

The RP2040 enumerates natively as a USB device. Flash with:

```bash
esphome run S/main.yaml
```

> Do **not** connect the external 12 V supply and USB-C simultaneously.

---

## Modbus Register Map (S node → M1 master)

The M1 reads sensor data from each S node using standard Modbus RTU function codes. The `modbus_master.yaml` template on the M side maps the following registers:

| Type | FC | Address | Entity |
|---|---|---|---|
| Input Register | FC04 | 0 | Temperature (×0.1 °C) |
| Input Register | FC04 | 1 | Humidity (×0.1 %) |
| Input Register | FC04 | 2 | Pressure (×0.1 hPa) |
| Input Register | FC04 | 3 | Brightness (lux) |
| Input Register | FC04 | 4 | VOC Index |
| Input Register | FC04 | 5 | NOx Index |
| Input Register | FC04 | 6 | CO₂ (ppm) |
| Input Register | FC04 | 7 | Detected Distance (cm) |
| Discrete Input | FC02 | 0 | PIR Movement |
| Discrete Input | FC02 | 1 | Presence (radar) |
| Discrete Input | FC02 | 2 | Movement (radar) |
| Discrete Input | FC02 | 3 | Static Presence (radar) |
| Discrete Input | FC02 | 4 | CO₂ Alarm |
| Discrete Input | FC02 | 5 | VOC Alarm |
| Discrete Input | FC02 | 6 | Temperature Alarm |
| Discrete Input | FC02 | 7 | Active Alarm |
| Coil | FC01/FC05 | 1 | Reset CO₂ Baseline |
| Holding Register | FC03/FC06 | 0 | IR Command (0=idle, 1–999=channel, 1001–1006=special) |
| Holding Register | FC03/FC06 | 10 | Temperature Setpoint (×10, °C) |
| Holding Register | FC03/FC06 | 11 | CO₂ Setpoint (ppm) |
| Holding Register | FC03/FC06 | 12 | Current Time (HHMM) |
| Holding Register | FC03/FC06 | 13 | Display Command (0=OK, 1=VENT, 2=HEAT, 3=COOL) |

---

## MQTT Topic Convention

All entities publish and subscribe under the pattern:

```
{mqtt_name}/{ModuleName}/{EntityName}/state     ← published by the device
{mqtt_name}/{ModuleName}/{EntityName}/command   ← subscribed by the device
```

Example for sensor node `Living`:
```
DOMIX/Living sensor/Temperature/state    → "22.4"
DOMIX/Living sensor/CO2/state            → "612"
DOMIX/Living sensor/IR/command           → "MUTE" | "1" | "34" | "OK"
```

Example for M2 I/O module:
```
DOMIX/M2_1/Output 1/state    → "ON" / "OFF"
DOMIX/M2_1/Output 1/command  → "ON" / "OFF"
DOMIX/M2_1/Input 1/state     → "ON" / "OFF"
```

All names can be changed in data.yaml file.

---

## M1 Display & Button Menu

The M1 module includes a SH1106 128×64 OLED and a 3-button analogue interface (Up / Down / OK) read via an ADS1115 ADC. The menu system defined in `module/m1.yaml` provides:

- **Home screen** — shows "DOMIX" header and current time; auto-returns after 10 s of inactivity.
- **Main menu (level 0)** — lists all installed modules (M2 I/O, M3 Contacts, M4 Relays…).
- **Submenu (level 1)** — shows live input/output states for the selected module.
- **Edit mode (level 2)** — allows toggling individual outputs directly from the panel.

Button voltage thresholds (ADS1115, gain 6.144 V):

| Button | Voltage range |
|---|---|
| Up | 2.5 V – 2.9 V |
| Down | 0.4 V – 0.65 V |
| OK | 1.5 V – 1.75 V |

---

## Zigbee Coordinator Note

The Zigbee module (CC2652) requires its own dedicated firmware to act as a Zigbee2MQTT coordinator. Refer to the [POE-Zigbee-Coordinator](https://github.com/carletz/POE-Zigbee-Coordinator) project for the flashing procedure.

> ⚠️ **ESPHome 2026.x is not compatible with the external Zigbee component.** If you need Zigbee, compile with ESPHome ≤ 2025.x (tested on **2025.7.5**). If Zigbee is not required, use the latest ESPHome version.

---

## External Components

The `M/module/.esphome/external_components/` directory contains a cached copy of the **ZMPT101B** voltage sensor ESPHome component (used by the M6 energy meter module). This is automatically referenced during compilation and does not require manual installation.

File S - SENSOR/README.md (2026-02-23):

# DOMIX Sensor Modules – S Family

The **DOMIX sensor family** is a set of standalone multi-sensor nodes designed to complement the main DOMIX cabinet system. Unlike the DIN-rail modules (M1–M9), sensor modules are intended for room-level deployment and communicate with the DOMIX M1 via **RS485**. Each node is built around a shared **core board (S)** and a sensor daughter board — **S1** for ceiling installation or **S2** for wall / 503-box installation.

The two daughter boards carry identical sensor sets but differ in mechanical packaging. The S2 variant additionally includes a small **OLED display** and a **rotary encoder** for local interaction.

---

## Table of Contents

- [S – Core Sensor Board](#s--core-sensor-board)
- [S1 – Ceiling Daughter Board](#s1--ceiling-daughter-board)
- [S2 – Wall Daughter Board (503-box)](#s2--wall-daughter-board-503-box)
- [Variant Configuration Guide](#variant-configuration-guide)
- [Choosing the Right Variant](#choosing-the-right-variant)

---

## S – Core Sensor Board

### Overview

The **DOMIX S Core** board is the shared intelligence of all DOMIX sensor nodes. It provides:

- Microcontroller (RP2040)
- Power supply chain (12V → 5V → 3.3V)
- USB-C programming interface
- RS485 communication
- 20-pin expansion header for S1 or S2 daughter boards

<div align="center">
    
</div>

The same PCB is used regardless of installation type; only the daughter board and 3D-printed enclosure change.

### System Architecture

| Component | Part | Notes |
|---|---|---|
| MCU | Raspberry Pi RP2040 | Core microcontroller |
| Flash | W25Q128JVSIQ (16 MB) | External SPI flash |
| Oscillator | 12 MHz crystal | System clock |
| RS485 Transceiver | MAX13487EESA+T | With SN74LVC1G125DCKR buffer |
| RS485 Protection | TVS + resettable fuses | Bus line protection |
| RS485 Termination | 120 Ω resistor | Solder only on the **last** sensor on bus |

The RP2040 exposes USB D+/D− directly on the USB-C connector, allowing firmware flashing without additional hardware.

The 20-pin header carries: `3V3`, `5V`, `GND`, I2C bus, UART, and GPIO lines to the daughter board. A supplementary **6-pin power header** provides additional `3V3 / 5V / GND` connections for the ceiling board only.

### Power Supply Architecture

| Stage | Component | Function |
|---|---|---|
| Input | 2-pin screw terminal | 12V DC input |
| 12V → 5V | TPS54302DDCR | Buck converter |
| 5V → 3.3V | Linear regulator | 3.3V rail |
| Power path | WPM2015-3 P-MOSFET | Auto-selection between 12V ext. and USB-C 5V |

> ⚠️ **Warning:** Do **not** connect both the external 12V supply and the USB-C cable simultaneously.

---

## S1 – Ceiling Daughter Board

### Overview

The **S1** daughter board is designed for ceiling installation in a dedicated 3D-printed enclosure. It hosts a comprehensive set of environmental and presence sensors, plus IR transmit/receive circuits for controlling legacy infrared devices.

The board connects to the S Core via the 20-pin header and receives a supplementary 3-pin power connector.

> **Note:** The S1 comes in two sub-variants: **S1a** (mmWave radar) and **S1b** (PIR sensor). Only one presence sensor can be mounted at a time due to physical constraints.

<div align="center">
    
    
</div>

### Sensors and Peripherals

| Sensor / Component | Interface | Function |
|---|---|---|
| HLK-LD2410C-P (24 GHz mmWave radar) | UART | Static presence + motion detection — **S1a only** |
| PIR HC-SR501 | Digital (3-pin header) | Motion detection — **S1b only** |
| BME280 | I2C | Temperature, humidity, barometric pressure |
| BH1750 | I2C | Ambient light (lux) |
| SCD41 | I2C | CO₂ (ppm), temperature, humidity (photoacoustic) |
| SGP41 | I2C | VOC and NOx index |
| TSOP31240 | — | 38 kHz IR receiver for remote control decoding |
| SFH 4546 × 3 + BSS138BK MOSFET | — | High-power IR transmitter array |

All I2C devices share the SDA/SCL bus from the S Core.

### Enclosure

The S1 assembly is housed in a **custom 3D-printed ceiling enclosure**, flush-mounted with openings for each sensor and the IR window. The S Core sits inside and connects to the S1 via the 20-pin header.

<div align="center">
    
</div>
---

## S2 – Wall Daughter Board (503-box)

### Overview

The **S2** daughter board carries the same core sensor suite as S1, but is designed for a standard **503 electrical wall box** — the same form factor used for wall switches and sockets. This makes it ideal for retrofitting into existing rooms without ceiling access.

Compared to S1, S2 adds a local user interface option (OLED + rotary encoder), but trades off the **SCD41**, **BH1750**, and **TSOP31240 IR receiver** due to space constraints.

> **Note:** The S2 comes in two sub-variants: **S2a** (display + encoder) and **S2b** (extended sensors).

<div align="center">
    
    
</div>

### Sensors and Peripherals

| Sensor / Component | Interface | Notes |
|---|---|---|
| HLK-LD2410C-P (24 GHz mmWave) | UART | Presence detection |
| BME280 | I2C | Temperature, humidity, pressure |
| SGP41 | I2C | VOC and NOx index |
| SCD41 | I2C | CO₂ — **S2b only** |
| BH1750 | I2C | Ambient light — **S2b only** |
| OLED HS96L03W2C03 | I2C (0x3C) | Local display — **S2a only** |
| Rotary Encoder EC11L1525G01 | GPIO 16/17/18 | Local navigation — **S2a only** |
| SFH 4546 × 3 IR TX | — | IR transmitter array |

> The OLED default I2C address is `0x3C`, configurable via solder jumper.

### Enclosure

The S2 is designed to fit inside a standard **503 flush wall box**. The S Core mounts behind the S2 daughter board; the assembly slides in from the front with the display and encoder accessible through the cover plate. No ceiling modification required.

---

## Variant Configuration Guide

All variants are built on the same principle: **one S Core board + one of four daughter board configurations**.

| Variant | Installation | LD2410C | PIR | BME280 | SCD41 | SGP41 | BH1750 | OLED + Encoder | IR RX | IR TX |
|---|---|:---:|:---:|:---:|:-----:|:-----:|:---:|:---:|:-----:|:-----:|
| **S Core + S1a** | Ceiling – mmWave | ✓ | – | ✓ | ✓ | ✓ | ✓ | – | ✓ | ✓ |
| **S Core + S1b** | Ceiling – PIR | – | ✓ | ✓ | ✓ | ✓ | ✓ | – | ✓ | ✓ |
| **S Core + S2a** | Wall 503 – Display | ✓ | – | ✓ | – | ✓ | – | ✓ | – | ✓ |
| **S Core + S2b** | Wall 503 – Sensors | ✓ | – | ✓ | ✓ | ✓ | ✓ | – | – | ✓ |

<div align="center">
    
    
</div>
<div align="center">
    
    
</div>

> All variants include the S Core with RP2040, RS485, USB-C, and 12V power supply.  
> ✓ = included · – = not available in this variant  
> Individual sensors are always optional — the table reflects the **maximum** possible configuration.

---

## Choosing the Right Variant

| Use Case | Recommended Variant | Reason |
|---|---|---|
| Living room / bedroom occupancy automation | **S1a or S2a** (mmWave) | PIR cannot reliably detect stationary presence |
| Corridor, entrance, secondary rooms | **S1b** (PIR) | Simpler, lower cost; static detection not needed |
| Air quality priority (bedroom, office, kitchen) | **S2b** | Richest dataset: CO₂, light, temp, humidity, VOC |
| Local display / thermostat / manual controls | **S2a** | OLED + encoder for direct interaction; trades SCD41 + BH1750 |

All variants are:
- **Powered** by 12V DC on the S Core (fully autonomous)
- **Connected** via two-wire RS485 to the DOMIX M1
- **Flashable** via USB-C

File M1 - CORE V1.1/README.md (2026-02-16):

# Module M1 CORE

<div align="center">
    
</div>

<div align="center">
    
    
    
</div>

## Overview

DOMIX M1 is the heart of the DOMIX ecosystem: a modular and expandable core controller for smart home and building automation systems. It is designed as the central processing and communication hub, capable of bridging Ethernet, Zigbee, RS485, and I2C-based expansion modules within a single, compact hardware platform. The project focuses on reliability, modularity, and protocol interoperability.

| Main info	| M1 |  |
|---|---|---|
| Lower module | Dimension	| 67 x 84.4 mm|
| | Layer	  | 4 |
| Upper module | Dimension	| 67 x 41 mm|
| | Layer	 | 2 |
| Middle module V1.0 | Dimension	| 67.5 x 59.6 mm |
| | Layer	  | 2 |
| Middle module V1.1 | Dimension | 67.5 x 59.6 mm |
| | Layer	  | 2 |

## Design Philosophy
The DOMIX M1 Core Module is built around three key principles:
-	Modularity – clear separation between core logic, expansion boards, and user interface
-	Protocol bridging – seamless coexistence of IP-based, fieldbus, and wireless networks (Zigbee)
-	Industrial robustness – protected interfaces, proper power design, and EMI-aware layout
The system is not intended to be a "one-board-does-all" device, but rather a scalable automation backbone that can grow with the user's needs.

## System Architecture
At a high level, DOMIX M1 is composed of three main hardware layers:
1.	Lower PCB – Core Module: MCU, networking, power management, and industrial interfaces
2.	Middle PCB – Expansion Backplane: I2C distribution and mechanical stacking interface
3.	Upper PCB – Display & User Interface: Local control, status indication, and user feedback
This stacked architecture allows the system to evolve without redesigning the core, ensuring long-term maintainability and upgradeability. To increase the number of I2C buses present, there is also a version 1.1 of the DOMIX M1 module for which the use of the TCA9548APWR chip allows up to 8 new buses.
To summarize, version 1.0 has one I2C bus available for communication, while version 1.1 can use up to 8 different buses allowing multiple slave devices to communicate. We chose to have two different middle boards while keeping both the lower and upper ones identical.

## Core Microcontroller
The heart of the system is an ESP32-S3-WROOM-1-N8R2 module, featuring a dual-core Xtensa LX7 MCU with integrated Wi-Fi and USB support, along with external PSRAM for advanced applications. The native USB-C interface enables easy flashing, debugging, and power delivery.
The ESP32-S3 serves multiple critical roles:
-	Main application processor for automation logic
-	Protocol bridge between Ethernet, Zigbee, RS485, and I²C
-	Logic controller for coordinating all expansion modules
Why didn't I choose another microcontroller? Well, the ESP32-S3 is now a more than robust and solid chip, both for programming and for interacting with the outside world. It's robust and simple enough to program compared to many other major chips, and it's fast enough to handle the tasks of this project. I didn't choose other chips from the Espressif family because none, in my opinion, have the required features together like the S3 series. An STM32 chip could certainly have been used, but I find it difficult to program, and that's not the sole purpose of this work. It probably would have been faster, but in terms of interaction, it would have been complicated to manage.

## Power Supply Architecture
DOMIX M1 supports multiple power sources with proper isolation and protection. The input power accepts 9–12V DC external supply with reverse polarity and overcurrent protection, followed by step-down DC/DC conversion to 5V. Internal rails include a 5V system rail and a 3.3V regulated rail for logic and RF circuits. Automatic USB-C power selection during programming ensures stable operation in permanent installations while remaining developer-friendly.
Do not connect both external power supply and USB-C cable!

## Ethernet Connectivity
Wired networking is provided by the W5500 Ethernet controller, featuring a hardware TCP/IP stack that significantly reduces MCU load and improves determinism. The module supports 10/100 Mbps Ethernet with an SPI interface to the ESP32, and includes an integrated RJ45 connector with magnetics (HR911105A). Activity LED indicator it’s also repeated on the front of the module for greater visibility.
Ethernet is my karma; no one can convince me otherwise when it comes to data transmission and the intrinsic security of a LAN connection. 
Obviously, we're not talking about LORA modules or other long-range needs, but for me, the only solution at home is Ethernet. Heavy walls, irregular shapes, external interference, anything can interact with your wireless systems. Some might say, "Why Zigbee?" Well, if something has to stay, it's better than a jumble of IP addresses on your router, right? Separate communications on separate systems, and only one IP to monitor for logs or troubleshooting. Don't you agree? I'm convinced of this; based on my experience, just remembering all the IP addresses connected to the various devices (yes, I have them in my house, too) and accessing them individually is a pain. 
That's why the cable, once installed and tested, can't fail.

## Zigbee Wireless Interface
Wireless mesh networking is handled by the RF-BM-2652P2 Zigbee module, based on the TI CC2652 family. It features an external SMA antenna connector, dedicated UART communication with the ESP32, and status LEDs for network and message activity. This allows DOMIX M1 to act as a Zigbee coordinator, router, or gateway, bridging Zigbee devices with Ethernet/IP systems. The chip firmware is described in the software chapter of this guide.
The choice for this chip was also made considering the work already done both for my POE coordinator [POE-Zigbee-Coordinator](https://github.com/carletz/POE-Zigbee-Coordinator) and above all the extremely functional firmware available on the network. I didn't want to waste a good portion of the work already done, which you can find here, and above all a functional and good solution for monitoring all our Zigbee components.

## RS485 Industrial Interface
For field-level and industrial communication, the board integrates a MAX13487E RS485 transceiver with half-duplex differential communication, TVS protection for ESD and surge immunity, and resettable fuses on signal lines. Typical use cases include Modbus RTU devices, distributed sensors and actuators, and long-distance wired communication.
Serial connection is forever... you can connect anything here, communicate with anything, and above all, why not? You could connect two appropriately programmed DOMIX M1s in parallel at a considerable distance. They could be connected via Ethernet, but this isn't always possible. In any case, any type of sensor, controller, or actuator usually has the ability to communicate via serial, which is why it's there.

## I2C Expansion Bus
DOMIX M1 exposes 2 I2C buses designed for expansion and modularity. The central PCB have two board configurations that lead to the following possibilities:

- keep only the two I2C buses originating from the ESP32 (board version 1.0);
- increase the possible number of buses using the TCA9548APWR chip (board version 1.2);

The TCA9548APWR is an 8-channel I2C multiplexer/switch that allows you to create 8 I2C buses with non-overlapping addresses. Each channel is addressed via the main I2C bus, allowing you to activate/deactivate channels individually to avoid address conflicts. It is configurable via pins A0, A1, and A2, and in our case, its address is 0x70.

If you use V1.0 the addresses are confined within the possibilities reported in the previous chapter. If, however, you choose to use the V1.2 with the I2C switch, you must first configure its use in ESPHome and then configure the network addresses of the connected components accordingly. Each of them will then be seen by the system as a separate bus, but which can still easily communicate with the microcontroller.

##	User Interface & Display Module
An optional Upper PCB provides local interaction and feedback through a 1.3" OLED display (128×64, SH1106, I2C), three physical buttons (UP / DOWN / OK), an ADS1115 ADC for button multiplexing, and status LEDs for power, Ethernet, Zigbee network, and activity. This enables local status visualization, menu-driven configuration, and manual interaction without requiring external software.
The display module, as with all other upper PCB configurations, is not necessary. Its use can be chosen and adapted to your needs. Personally, I believe that a good local display, even if limited, is useful in certain cases. This is why it was added to the system, but it absolutely does not preclude the functionality of all modules, it’s at your choice.

## Mechanical Structure
The system uses a stacked PCB architecture with the lower PCB containing core electronics, a vertical PCB providing mechanical and electrical interconnect, and an upper PCB housing the human interface. This structure minimizes footprint, improves maintainability, and allows for future UI or expansion board development.

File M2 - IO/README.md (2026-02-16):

# Module M2 GENERAL I/O

<div align="center">
    
</div>

<div align="center">
    
    
</div>

## Overview
The DOMIX M2 module is intended to be a generic I/O module, useful for normal commands and controls.

|Main info|	| M2|
|---|---|---|
|Lower module	|Dimension	|32 x 84.4 mm|
|	|Layer	|2|
|Upper module	|Dimension	|32 x 41 mm|
|	|Layer	|2|
|Vertical module|	Dimension	|50.5 x 24 mm|
|	|Layer	|2|

## System Architecture
For all possible modules the system is always the same, 3 stacked pcb that allows for modularity and easy maintenance if necessary. See DOMIX M1 module for more information.
The DOMIX M2 system includes a PCA9535 integrated circuit that allows you to control 16 channels, in this case 8 input channels and 8 output channels. SW1 is a dip switch that manages the correct I2C address on channel 1 of the M1 module's control bus. The following summarizes the possible (but non-overlapping) addresses that can be managed by the integrated circuit itself:

|PCA9535	||||
|---|---|---|---|
|Position of SW1 pins|||
|Address	|A2	|A1	|A0|
|0x20	|0|	0|	0|
|0x21	|0|	0|	1|
|0x22	|0|	1|	0|
|0x23	|0|	1|	1|
|0x24	|1|	0|	0|
|0x25	|1|	0|	1|
|0x26	|1|	1|	0|
|0x27	|1|	1|	1|

The same table is reported as a silkscreen on the back of the PCB itself.
It is highly recommended that you first create a sort of table where you can know how many and which modules will need to be paired so that you can correctly manage all the addresses and avoid overlaps.
The input channels are controlled by two TLP290-4 optocouplers that allow the isolation of the external control from the internal management part, sending a digital signal to the communication micro.
The output channels, however, have a ULN2803-A, a module with 8 Darlington arrays that allows you to use the 12VDC voltage and bring it to the external controls, without affecting the internal control logic, being completely decoupled.

## Power Supply Architecture
The module's control logic is powered by the IDC connector and therefore by the DOMIX M1 core module. A 3V3 power supply is required to operate the integrated circuits, while the 5V power supply in the cable is not used on this board. Each integrated circuit has a decoupling capacitor where necessary, while the ULN2803-A is connected to 12VDC as a reference for the output signals. For uniformity, the infrared LEDs of the TLP290-4 are also powered by 12VDC, so external controls will also be powered by this power supply.
For the above, it is therefore necessary to also connect the 12VDC to make both the input and output connections work. This power supply can be the same one supplied to the M1 module.

## User Interface & Display Module
For simplicity's sake, in this case, we chose to simply display LEDs at the top that indicate whether individual channels are activated or not. These LEDs are connected to the system's 3V3 logic and indicate channel activation. The input channels are at the top, and the output channels are at the bottom.

## Mechanical Structure
As like the M1 module, the DOMIX M2 system uses a stacked PCB architecture with the lower PCB containing core electronics, a vertical PCB providing mechanical and electrical interconnect, and an upper PCB housing the human interface. This structure minimizes footprint, improves maintainability, and allows for future UI or expansion board development.

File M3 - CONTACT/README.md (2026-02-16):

# Module M3 CONTACT

<div align="center">
    
</div>

<div align="center">
    
    
</div>

##	Overview
The DOMIX M3 module is intended to be an analogic contact input module, useful for door, windows, and similar reed or switch contact reading.

|Main info| | 	M3 |
|---|---|-----|
|Lower module|	Dimension|	32 x 84.4 mm|
|	|Layer	|2|
|Upper module|	Dimension|	32 x 41 mm|
|	|Layer	|2|
|Vertical module|	Dimension|	50.5 x 24 mm|
|	|Layer	|2|

## System Architecture
For all possible modules the system is always the same, 3 stacked pcb that allows for modularity and easy maintenance if necessary. See DOMIX M1 module for more information.
The DOMIX M3 system includes a PCA9554A integrated circuit that allows you to control the 4 switches of analog multiplexer for scan 16 analog channel, all for input purposes. Due to physical restraint on the pcb for choosing the right address there are several pads to be welded during preparation. The following summarizes the possible (but non-overlapping) addresses that can be managed by the integrated circuit itself:

|PCA9554A| | | |	
|-----|-----|----|----|
|Jumper to be welded| | | |
|Address|	A2|	A1|	A0|
|0x38|	0|	0|	0|
|0x39|	0|	0|	1|
|0x3A|	0|	1|	0|
|0x3B|	0|	1|	1|
|0x3C|	1|	0|	0|
|0x3D|	1|	0|	1|
|0x3E|	1|	1|	0|
|0x3F|	1|	1|	1|

The same table is reported as a silkscreen on the back of the PCB itself.

The analog multiplexer, which reads the contact values, is a CD74HC4067PWR chip. The output of this component is connected to an ADS1115 that, though the I2C connection forward to the DOMIX M1 module the data read. Also for this chip there is a dedicated part on the back of pcb where it is necessary to weld the correct pad for addressing correctly the chip on the bus. In this case the table can be represented as follows:

|Address	|Pad||
|----|-----|-----|
|0x48|	GND| pad welded|
|0x49|	3V3| pad welded|
|0x4A|	SDA| pad welded|
|0x4B|	SCL| pad welded|

> [!NOTE] 
> Only one pad have to be welded to grant the correct address on the bus. The pads that are not needed should be leave as is.

It is highly recommended that you first create a sort of table where you can know how many and which modules will need to be paired so that you can correctly manage all the addresses and avoid overlaps.
The control logic is quite simple: a BC847B NPN transistor receives the signal from the outside on the base pin. The emitter is connected to GND while on the collector I read the presence or absence of the 3V3 signal, appropriately filtered with an R-C system. The signal is then send to a channel of the multiplexer.

On the ADS1115 I’ll read a signal which will be on the upper or lower part of the digital conversion. On ESPHome a proper zone of reading should be implemented.

## Power Supply Architecture
The module's control logic is powered by the IDC connector and therefore by the DOMIX M1 core module. A 3V3 power supply is required to operate the integrated circuits, while the 5V power supply in the cable is not used on this board. Each integrated circuit has a decoupling capacitor where necessary, the external contacts are connected to the 12VDC power. This power supply can be the same one supplied to the DOMIX M1 module.

## User Interface & Display Module
In this case a user interface is represented by a small 0.96 128x64 SSD1315 chip I2C screen. This is not essential and could be avoided mounting on the module, the choice can be made at any time.

The HS HS96L03W2C03 OLED display module typically operates on an I2C address of 0x3C or 0x3D. It uses the SSD1306 driver, and the specific 7-bit address is determined by the SA0 bit (address pin), which is often configurable via a solder jumper on the back of the module. 

Jumper Setting: Modifying the zero-ohm resistor (jumper) on the back allows switching between potential addresses. 

Keep in mind always that the screen operates on the I2C bus number 2 so the address should be choose accordingly.

## Mechanical Structure
As like the DOMIX M1 and M2 module, the DOMIX M3 system uses a stacked PCB architecture with the lower PCB containing core electronics, a vertical PCB providing mechanical and electrical interconnect, and an upper PCB housing the human interface. This structure minimizes footprint, improves maintainability, and allows for future UI or expansion board development.

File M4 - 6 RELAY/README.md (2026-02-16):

# Module M4 6 RELAY

<div align="center">
    
</div>

<div align="center">
    
    
</div>

## Overview
The DOMIX M4 module is intended to be a relay module with a very generic use.

|Main info|	| M4 |
|---|---|-----|
|Lower module|	Dimension|	32 x 84.4 mm|
|	|Layer	|2|
|Upper module|	Dimension|	32 x 41 mm|
|	|Layer	|2|
|Vertical module|	Dimension|	50.5 x 24 mm|
|	|Layer	|2|

By using relays, I wanted to give the possibility of having an open contact available, without voltage, that can be used for example in the following ways:
-	Open contacts on equipment such as boilers, air conditioners, HVAC systems, and similar;
-	Open contact on power contactors, such as pumps;
-	Any type of connection, whether or not it requires voltage at the connections.

## System Architecture
For all possible modules the system is always the same, 3 stacked pcb that allows for modularity and easy maintenance if necessary. See DOMIX M1 module for more information.
The DOMIX M4 system includes a PCA9554A integrated circuit that allows you to control the gate of each 6 N-channel mosfet connected directly to the coils of 6 10A miniature pcb power relay. In this case, in order to choose the correct address for the chip, a dip switch called SW1 manages the correct I2C address on channel 1 of the M1 module's control bus. The following summarizes the possible (but non-overlapping) addresses that can be managed by the integrated circuit itself:

|PCA9554A| | | |	
|-----|-----|----|----|
|Position of SW1 pins| | | |
|Address|	A2|	A1|	A0|
|0x38|	0|	0|	0|
|0x39|	0|	0|	1|
|0x3A|	0|	1|	0|
|0x3B|	0|	1|	1|
|0x3C|	1|	0|	0|
|0x3D|	1|	0|	1|
|0x3E|	1|	1|	0|
|0x3F|	1|	1|	1|

The same table is reported as a silkscreen on the back of the PCB itself.

It is highly recommended that you first create a sort of table where you can know how many and which modules will need to be paired so that you can correctly manage all the addresses and avoid overlaps.

The system basically controls the contacts on the relay and in particular the characteristic of these components is to have a contact capable of withstanding a maximum of 10A at 250VAC or 10A at 30VDC. The coil is actuated at 5V to reduce the load on the contacts of PCA9554A itself through the mosfet.

At this point, someone might jump up on their chair. But wasn't it said that the entire system had to be completely decoupled from any dangerous live voltages? Yes, it’s correct, but at the same time, some appliances need to have this type of contact under voltage (for example, my boiler use 230VAC on his contact) and therefore I could not avoid to install a module with this type of solution.

The part which can withstand a maximum of 230VAC and 10A is only related to the connections between the contacts of the relays and the connector to the external world. On the pcb the tracks will be without silkscreen so the user can add solder to increase the physical thickness of the traces if needed.

Always remember that dealing with mains voltage is never a joke and that any operation related to it must always be carried out by qualified personnel. If in doubt, it is always best to contact an electrician.

## Power Supply Architecture
The module's control logic is powered by the IDC connector and therefore by the DOMIX M1 core module. A 3V3 power supply is required to operate the integrated circuit of the PCA9554A chip, while the 5V power supply in the cable is used for the relay coils circuit, which is separated by the mosfet from the logic circuit at 3V3. The integrated circuit has a decoupling capacitor, and the external contacts are completely separated from the inside of the logical part of the board. 

## User Interface & Display Module
A user interface made with a display exactly identical to the DOMIX M3 module is foresee on the project. The use of it, by the way, should be extremely calculated due to the lack of possibilities of the I2C address available on the bus. Adding another I2C screen could be dangerous and not correct, any user should, in my opinion, calculate the correct number of modules and use just one display where I can always represent the output of my system through ESPHome. This, in any case, should be studied case by case.

## Mechanical Structure
As like all the other DOMIX module, the DOMIX M4 system uses a stacked PCB architecture with the lower PCB containing core electronics, a vertical PCB providing mechanical and electrical interconnect, and an upper PCB housing the human interface. This structure minimizes footprint, improves maintainability, and allows for future UI or expansion board development.

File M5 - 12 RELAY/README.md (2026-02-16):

# Module M5 12 RELAY

<div align="center">
    
</div>

<div align="center">
    
    
</div>

## Overview
The DOMIX M5 module is conceptually identical to the DOMIX M4 module, with the difference in the number of outputs which in this case is equal to 12. Also, the characteristics of the designed relays are the same, in order to try to standardize the components to be purchase.

|Main info|	| M5|
|---|---|-----|
|Lower module|	Dimension|	67 x 84.4 mm|
|	|Layer	|2|
|Upper module|	Dimension|	67 x 41 mm|
|	|Layer	|2|
|Vertical module|	Dimension|	50.5 x 24 mm|
|	|Layer	|2|

## System Architecture
For all possible modules the system is always the same, 3 stacked pcb that allows for modularity and easy maintenance if necessary. See DOMIX M1 module for more information.
The DOMIX M5 system includes a PCA9535 integrated circuit that allows you to control the gate of each 12 N-channel mosfet connected directly to the coils of 12 10A miniature pcb power relay. In order to choose the correct address for the chip, a dip switch called SW1 manages the correct I2C address on channel 1 of the M1 module's control bus. The following summarizes the possible (but non-overlapping) addresses that can be managed by the integrated circuit itself:

|PCA9535| | | |	
|-----|-----|----|----|
|Position of SW1 pins| | | |
|Address|	A2|	A1|	A0|
|0x20|	0|	0|	0|
|0x21|	0|	0|	1|
|0x22|	0|	1|	0|
|0x23|	0|	1|	1|
|0x24|	1|	0|	0|
|0x25|	1|	0|	1|
|0x26|	1|	1|	0|
|0x27|	1|	1|	1|

The same table is reported as a silkscreen on the back of the PCB itself.

It is highly recommended that you first create a sort of table where you can know how many and which modules will need to be paired so that you can correctly manage all the addresses and avoid overlaps.

The use and the functionality of this module is exactly the same of DOMIX M4 module. Check the consideration inside the relative paragraph.

## Power Supply Architecture
The module's control logic is powered by the IDC connector and therefore by the DOMIX M1 core module. A 3V3 power supply is required to operate the integrated circuit of the PCA9535 chip, while the 5V power supply in the cable is used for the relay coils circuit, which is separated by the mosfet from the logic circuit at 3V3. The integrated circuit has a decoupling capacitor, and the external contacts are completely separated from the inside of the logical part of the board. 

## User Interface & Display Module
A user interface made with a display exactly identical to the DOMIX M1 module is foresee on the project. The use of it, by the way, should be extremely calculated due to the lack of possibilities of the I2C address available on the bus. Adding another I2C screen could be dangerous and not correct, any user should, in my opinion, calculate the correct number of modules and use just one display where I can always represent the output of my system through ESPHome. This, in any case, should be studied case by case.

## Mechanical Structure
As like all the other DOMIX module, the DOMIX M5 system uses a stacked PCB architecture with the lower PCB containing core electronics, a vertical PCB providing mechanical and electrical interconnect, and an upper PCB housing the human interface. This structure minimizes footprint, improves maintainability, and allows for future UI or expansion board development.

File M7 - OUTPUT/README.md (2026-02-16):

# Module M7 OUTPUT

<div align="center">
    
</div>

<div align="center">
    
    
</div>

## Overview
The DOMIX M7 module is intended to be a generic Output module, useful for normal commands and controls.

|Main info|	| M7 |
|---|---|-----|
|Lower module|	Dimension|	32 x 84.4 mm|
|	|Layer	|2|
|Upper module|	Dimension|	32 x 41 mm|
|	|Layer	|2|
|Vertical module|	Dimension|	50.5 x 24 mm|
|	|Layer	|2|

## System Architecture
For all possible modules the system is always the same, 3 stacked pcb that allows for modularity and easy maintenance if necessary.
The DOMIX M7 system includes a PCA9535 integrated circuit that allows you to control 16 output channels. SW1 is a dip switch that manages the correct I2C address on channel 1 of the M1 module's control bus. The following summarizes the possible (but non-overlapping) addresses that can be managed by the integrated circuit itself:

|PCA9535| | | |	
|-----|-----|----|----|
|Position of SW1 pins| | | |
|Address|	A2|	A1|	A0|
|0x20|	0|	0|	0|
|0x21|	0|	0|	1|
|0x22|	0|	1|	0|
|0x23|	0|	1|	1|
|0x24|	1|	0|	0|
|0x25|	1|	0|	1|
|0x26|	1|	1|	0|
|0x27|	1|	1|	1|

The same table is reported as a silkscreen on the back of the PCB itself.

The output channels have a ULN2803-A, a module with 8 Darlington arrays that allows you to use the 12VDC voltage and bring it to the external controls, without affecting the internal control logic, being completely decoupled, as the M3 module.

## Power Supply Architecture
The module's control logic is powered by the IDC connector and therefore by the DOMIX M1 core module. A 3V3 power supply is required to operate the integrated circuits, while the 5V power supply in the cable is not used on this board. Each integrated circuit has a decoupling capacitor where necessary, while the ULN2803-A is connected to 12VDC as a reference for the output signals.
For the above, it is therefore necessary to also connect the 12VDC to make the output connections work. This power supply can be the same one supplied to the M1 module.

## User Interface & Display Module
For simplicity's sake, in this case, we chose to simply display LEDs at the top that indicate whether individual channels are activated or not. These LEDs are connected to the system's 3V3 logic and indicate channel activation.

## Mechanical Structure
As like the M1 module, the DOMIX M7 system uses a stacked PCB architecture with the lower PCB containing core electronics, a vertical PCB providing mechanical and electrical interconnect, and an upper PCB housing the human interface. This structure minimizes footprint, improves maintainability, and allows for future UI or expansion board development.

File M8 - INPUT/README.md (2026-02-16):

# Module M8 INPUT

<div align="center">
    
</div>

<div align="center">
    
    
</div>

## Overview
The DOMIX M8 module is intended to be a generic Input module, useful for normal commands and controls.

|Main info|	| M8 |
|---|---|-----|
|Lower module|	Dimension|	32 x 84.4 mm|
|	|Layer	|2|
|Upper module|	Dimension|	32 x 41 mm|
|	|Layer	|2|
|Vertical module|	Dimension|	50.5 x 24 mm|
|	|Layer	|2|

## System Architecture
For all possible modules the system is always the same, 3 stacked pcb that allows for modularity and easy maintenance if necessary.
The DOMIX M8 system includes a PCA9535 integrated circuit that allows you to control 16 input channels. SW1 is a dip switch that manages the correct I2C address on channel 1 of the M1 module's control bus. The following summarizes the possible (but non-overlapping) addresses that can be managed by the integrated circuit itself:

|PCA9535| | | |	
|-----|-----|----|----|
|Position of SW1 pins| | | |
|Address|	A2|	A1|	A0|
|0x20|	0|	0|	0|
|0x21|	0|	0|	1|
|0x22|	0|	1|	0|
|0x23|	0|	1|	1|
|0x24|	1|	0|	0|
|0x25|	1|	0|	1|
|0x26|	1|	1|	0|
|0x27|	1|	1|	1|

The same table is reported as a silkscreen on the back of the PCB itself.

The input channels are controlled by four TLP290-4 optocouplers that allow the isolation of the external control from the internal management part, sending a digital signal to the communication micro.

## Power Supply Architecture
The module's control logic is powered by the IDC connector and therefore by the DOMIX M1 core module. A 3V3 power supply is required to operate the integrated circuits, while the 5V power supply in the cable is not used on this board. Each integrated circuit has a decoupling capacitor where necessary. The infrared LEDs of the TLP290-4 are powered by 12VDC, so external controls will also be powered by this power supply.
For the above, it is therefore necessary to also connect the 12VDC to make the input connections work. This power supply can be the same one supplied to the M1 module.

## User Interface & Display Module
For simplicity's sake, in this case, we chose to simply display LEDs at the top that indicate whether individual channels are activated or not. These LEDs are connected to the system's 3V3 logic and indicate channel activation.

## Mechanical Structure
As like the M1 module, the DOMIX M8 system uses a stacked PCB architecture with the lower PCB containing core electronics, a vertical PCB providing mechanical and electrical interconnect, and an upper PCB housing the human interface. This structure minimizes footprint, improves maintainability, and allows for future UI or expansion board development.

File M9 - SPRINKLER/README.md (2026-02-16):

# Module M9 SPRINKLER

<div align="center">
    
</div>

<div align="center">
    
    
</div>

## Overview
The M9 module is a special module that can drive 24VAC loads,  typically used for irrigation valve coils. This module is based on another project of mine called [SprinklerBoy](https://github.com/carletz/Sprinkler-Boy). 

|Main info|	| M9|
|---|---|-----|
|Lower module|	Dimension|	67 x 84.4 mm|
|	|Layer	|2|
|Upper module|	Dimension|	67 x 41 mm|
|	|Layer	|2|
|Vertical module|	Dimension|	50.5 x 24 mm|
|	|Layer	|2|

## System Architecture
For all possible modules the system is always the same, 3 stacked pcb that allows for modularity and easy maintenance if necessary. See DOMIX M1 module for more information.
The DOMIX M9 system includes a PCA9554A integrated circuit that allows you to control 8 MAC97A8 triac circuits. A dip switch called SW1 manages the correct I2C address on channel 1 of the M1 module's control bus. The following summarizes the possible (but non-overlapping) addresses that can be managed by the integrated circuit itself:

|PCA9554A| | | |	
|-----|-----|----|----|
|Position of SW1 pins| | | |
|Address|	A2|	A1|	A0|
|0x38|	0|	0|	0|
|0x39|	0|	0|	1|
|0x3A|	0|	1|	0|
|0x3B|	0|	1|	1|
|0x3C|	1|	0|	0|
|0x3D|	1|	0|	1|
|0x3E|	1|	1|	0|
|0x3F|	1|	1|	1|

The same table is reported as a silkscreen on the back of the PCB itself.

The buttons on the top module are controlled by a PCF8574M/TR which allows the triac controls to be directly operated to open and close the output contacts, a typical function of an irrigation controller.As before here the addresses that can be managed by the integrated circuit itself:

|PCF8574| | | |	
|-----|-----|----|----|
|Position of SW2 pins| | | |
|Address|	A2|	A1|	A0|
|0x38|	0|	0|	0|
|0x39|	0|	0|	1|
|0x3A|	0|	1|	0|
|0x3B|	0|	1|	1|
|0x3C|	1|	0|	0|
|0x3D|	1|	0|	1|
|0x3E|	1|	1|	0|
|0x3F|	1|	1|	1|

The same table is reported as a silkscreen on the back of the PCB itself.

It is highly recommended that you first create a sort of table where you can know how many and which modules will need to be paired so that you can correctly manage all the addresses and avoid overlaps.

## Power Supply Architecture
The module's control logic is powered by the IDC connector and therefore by the DOMIX M1 core module. A 3V3 power supply is required to operate the integrated circuits, while the 5V power supply in the cable is not used on this board. Each integrated circuit has a decoupling capacitor where necessary. 

It’s necessary to connect an external 24VAC power supply which is necessary for managing the external coils. For this particular module, the AC connection is necessary because the circuit relies on power triacs that can only handle this type of input. The valve common terminal has its own COM connector with two available outputs.

## User Interface & Display Module
The user interface designed for this module is equipped with 8 latch switches that allow you to control the opening and closing of each output. An LED allows you to immediately view the output status. Depending on how the buttons are then programmed, different effects can be obtained. In fact, this user interface is implicitly disconnected from the direct output; it must be programmed.

## Mechanical Structure
As like the M1 module, the DOMIX M8 system uses stacked PCB architecture with the lower PCB containing core electronics, a vertical PCB providing mechanical and electrical interconnect, and an upper PCB housing the human interface. This structure minimizes footprint, improves maintainability, and allows for future UI or expansion board development.

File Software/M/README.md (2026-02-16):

# ESPHome software

For me, ESPHome was an obvious choice, convenient and quick. I'm not a great programmer and I didn't want to get lost in a maze of lines of code, perhaps already flawed from the start, which would have wasted a lot of time. I've already used ESPHome in many other projects with excellent results, so I'd like to repeat the same approach in this project.
You're all familiar with ESPHome, so this isn't the section to explain how it works or how to use it. For that, I refer you to the application's excellent website, located at https://esphome.io/.

I created a project with a basic structure that is absolutely not intended to be the only possible solution; on the contrary, it aims to be the inspiration for many possible solutions that can be implemented on the system.

## Project structure
The structure includes a hardware section where all the possible blocks relating to the various basic components of ESPHome have been divided, with the configuration updated with the hardware characteristics of the system. The sensor folder currently only includes the 1-wire module, which can be configured if necessary, while the module section includes the basic definitions of all modules, also including alternative examples, which must be configured by the user according to their needs.

```
Software/
├── hardware/
│   ├── data.yaml
│   ├── esp.yaml
│   ├── ethernet.yaml
│   ├── i2c.yaml
│   ├── info.yaml
│   ├── log.yaml
│   ├── mqtt.yaml
│   ├── ota.yaml
│   ├── restart.yaml
│   ├── screen.yaml
│   ├── serial.yaml
│   ├── time.yaml
│   ├── web_server.yaml
│   └── zigbee.yaml
├── module/
│   ├── m1.yaml
│   ├── m2.yaml
│   ├── m3.yaml
│   ├── m4.yaml
│   ├── m5.yaml
│   ├── m6.yaml
│   ├── m7.yaml
│   ├── m8.yaml
│   ├── m9.yaml
├── sensor/
│   └── wire.yaml
└── main.yaml
```

In the main.yaml file, you can select the modules you're interested in and the hardware components you intend to use during the build. Along with these, you'll need to customize the data.yaml file, which contains all the necessary substitutions to best customize your firmware. In fact, within this file you need to set the I2C addresses corresponding to each module. Without this, the system will not work.
Once the programming is set up you can upload using the USB-C port on the DOMIX M1 board that connects directly to the microcontroller, as the controller is natively built in. Please do not connect the external power supply while programming the module.

## Considerations about Zigbee firmware
Special consideration should be made for the Zigbee module. It must be programmed with a specific firmware that allows you to create a coordinator that can communicate with your central server via Zigbee2MQTT. The procedure is explained very well in another project of mine at the link: [POE-Zigbee-Coordinator](https://github.com/carletz/POE-Zigbee-Coordinator). I always thank [ZigStar](https://zig-star.com/) and [Z-Stack-firmware](https://github.com/Koenkk/Z-Stack-firmware/tree/dev/coordinator/Z-Stack_3.x.0/bin) for creating the specific tools and firmware. 
This setting allows you to automatically load the firmware. If that doesn't work, you can follow the script steps manually and use the buttons on the board for the Zigbee chip. Furthermore, if you encounter further problems, the board's direct programming pins are also exposed.

> [!WARNING]
> ESPHome version 2026, at the time this guide was written, is not compatible with the external Zigbee component, so if you need to use it you must compile it with a maximum version of 2025. I used 2025.7.5. If you don't need it, you can use the latest version.

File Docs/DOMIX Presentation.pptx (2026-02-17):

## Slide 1

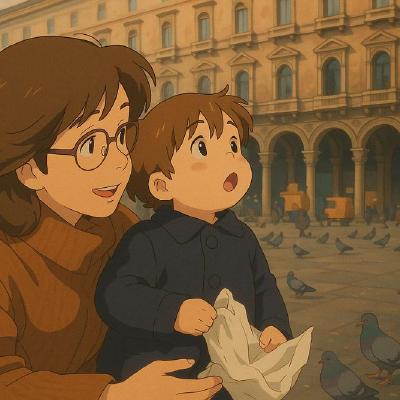
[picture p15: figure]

Domotic Modules for smart home & co

## The DOMIX Manifesto

DOMIX was created first and foremost for fun.
Fun, in the original sense: curiosity, experimentation, learning, and the joy of building something that works because you understand it.
- DOMIX is not a product.
- It is not a startup.
- It is not a competitor.
It is a research-driven, open, modular automation platform built by interest, not by market pressure.

## The DOMIX Manifesto

1. Open by Design
2. No Competition with Industrial Systems
3. Research, Not Certification
4. Modular or Nothing
5. Cabinet-Oriented, Low-Voltage Only
6. Ethernet First, Always
7. Open Ecosystem Integration
8. Zigbee as a First-Class Citizen
9. Fully Customizable by Design
10. Built for People Who Want to Understand

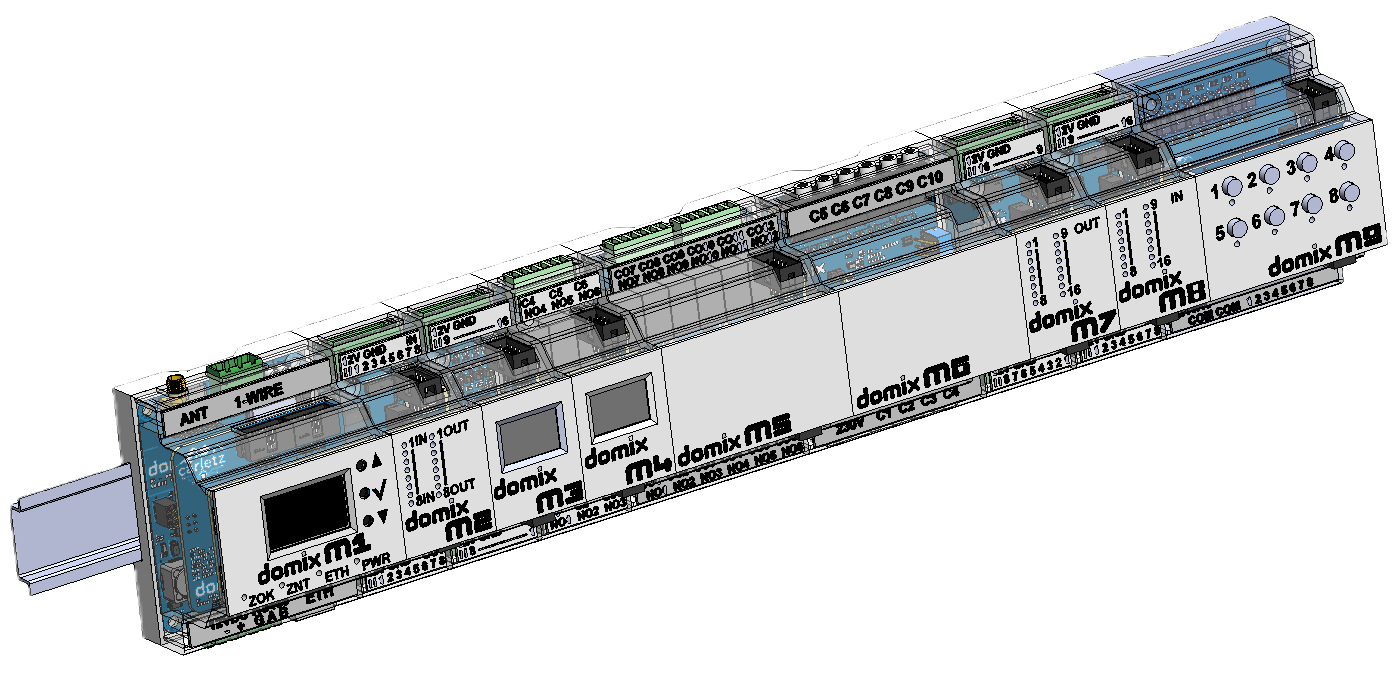
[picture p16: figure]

## Modular System Overview

DOMIX is a DIN-rail modular automation system designed around a centralized core controller and a set of specialized functional modules.
At the heart of the system is the DOMIX M1 Core Module, which manages logic, communication, and coordination.
All other modules are connected to M1 through a multi-drop I²C expansion bus, forming a scalable and deterministic automation backbone.
Each module is designed to occupy a defined number of standard DIN units, allowing clean electrical cabinets and predictable layouts.

## Core Communication Concept

- M1 acts as the I²C Master
- All other modules act as I²C Slaves
Each module has:
- A unique I²C address
- Its own local intelligence (I/O handling,
protection, signal conditioning)
The bus is optimized for:
- Short to medium distances inside electrical cabinets
- High reliability
- Low complexity

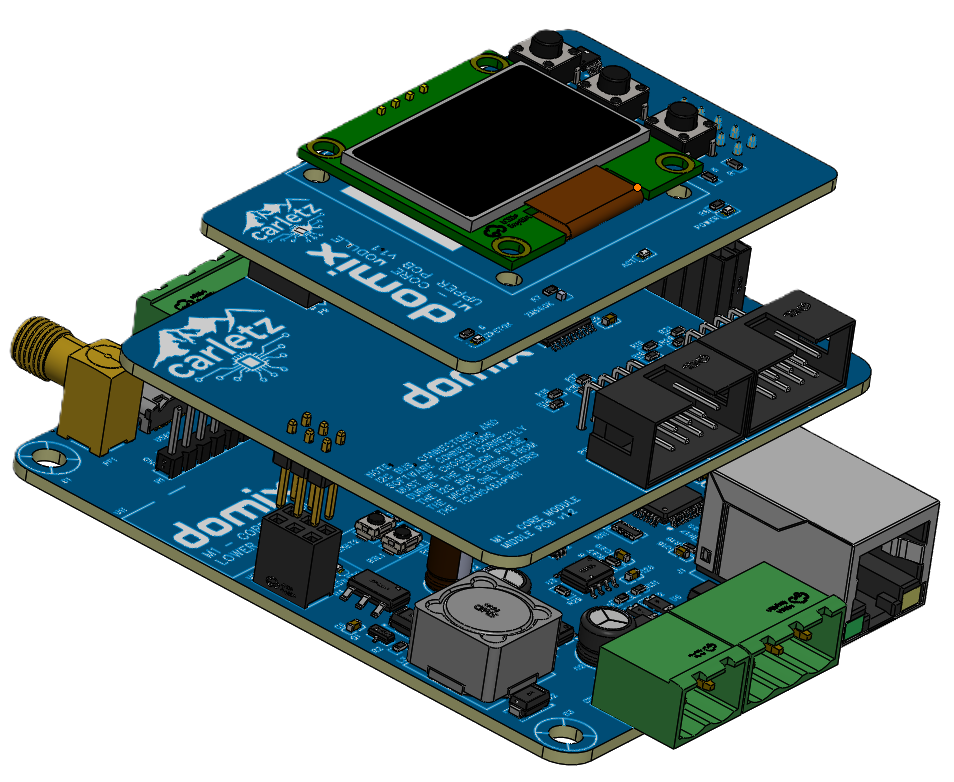
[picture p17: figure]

## I2C address as first decision

I2C Address must be decided before trying to add modules!
A configuration is valid on a single I2C bus if all the following conditions are met:
- (M2 + M5 + M7 + M8 + M9) ≤ 8
- (M3 + M4 + M6 + M9) ≤ 8
- (M3 + M6) ≤ 4 (ADS1115 limit)

Module | 0x20–0x27 | 0x38–0x3F | ADS1115
M2 | 1 | 0 | 0
M5 | 1 | 0 | 0
M7 | 1 | 0 | 0
M8 | 1 | 0 | 0
M3 | 0 | 1 | 1
M4 | 0 | 1 | 0
M6 | 0 | 1 | 1
M9 | 1 | 1 | 0

## DIN Rail Form Factor Strategy

This approach ensures:
- Mechanical consistency
- Easy cabinet planning
- Clear separation of logic,
sensing, and actuation

Module | Function | DIN Width
M1 | Core / Gateway | 4 modules
M2 | Digital I/O | 2 modules
M3 | Door & Window Contacts | 2 modules
M4 | 6-Relay / Shutter | 2 modules
M5 | 12-Relay / Shutter | 4 modules
M6 | Energy Meter (Clamp Meter) | 4 modules
M7 | Digital Output | 2 modules
M8 | Digital Input | 2 modules
M9 | Sprinkler | 4 modules

## M1 – Core Module (4 DIN Units)

The M1 Core Module is the brain of the DOMIX system.
Main responsibilities:
- System logic and automation rules
- Communication gateway
- I²C master controller
- Network and protocol translation
Key interfaces:
- Ethernet (W5500)
- Zigbee (CC2652-based module)
- RS485 (industrial fieldbus)
- I²C expansion bus
- Local display and buttons
M1 orchestrates all other modules and exposes the entire system to external platforms such as home automation servers or custom applications.

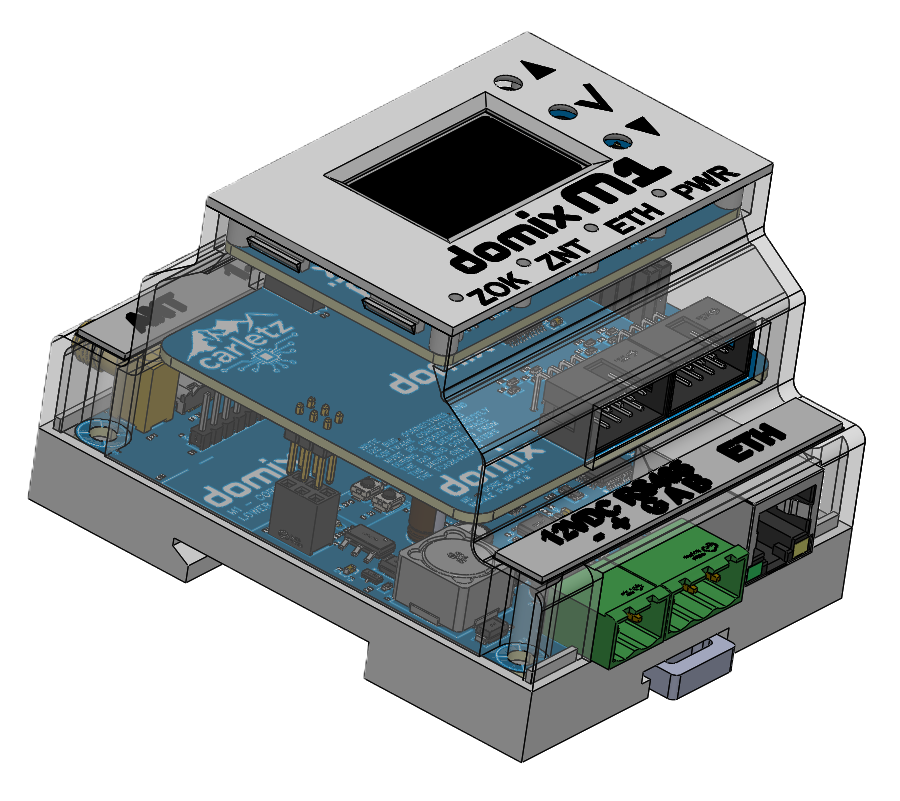
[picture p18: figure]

## M2 – I/O Module (2 DIN Units)

The M2 module provides generic input and output capabilities.
Typical features:
- 8 Digital inputs (dry contact)
- 8 Digital outputs (low-power control)
Used for:
- Switch or similar
- Auxiliary controls
- Generic automation tasks
- Connections to power relay or contactors
I2C addressable by dip switch on left side for each module

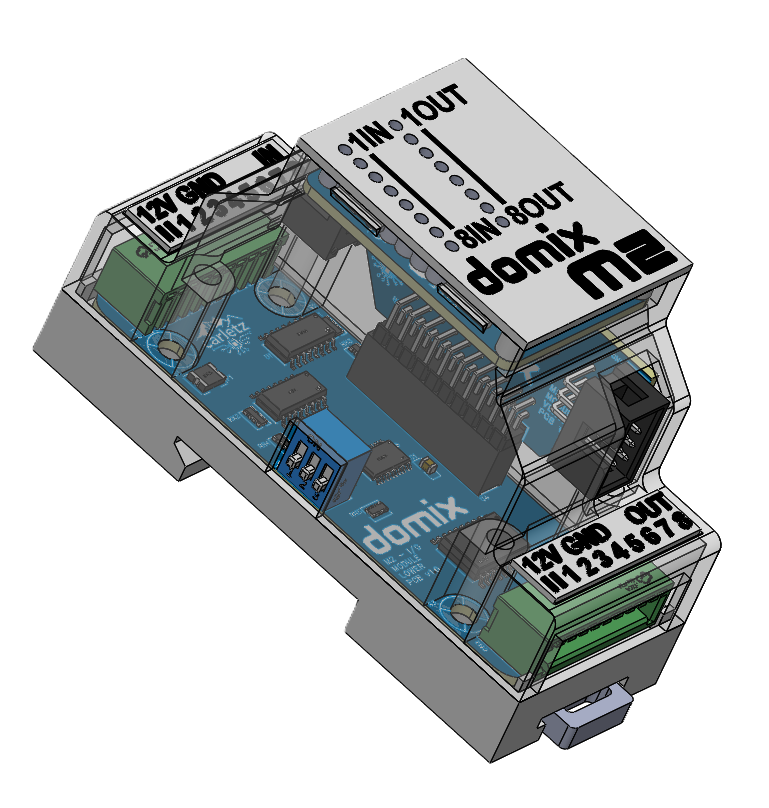
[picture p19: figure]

## M3 – Contact Module (2 DIN Units)

The M3 module is optimized for door, window, and dry-contact monitoring.
Characteristics:
- 16 Isolated analog inputs
- Long cable compatibility
- Debounce and noise filtering
- Ideal for security and presence logic
Designed specifically for:
- Doors
- Windows
- Magnetic reed sensors
- Alarm contacts

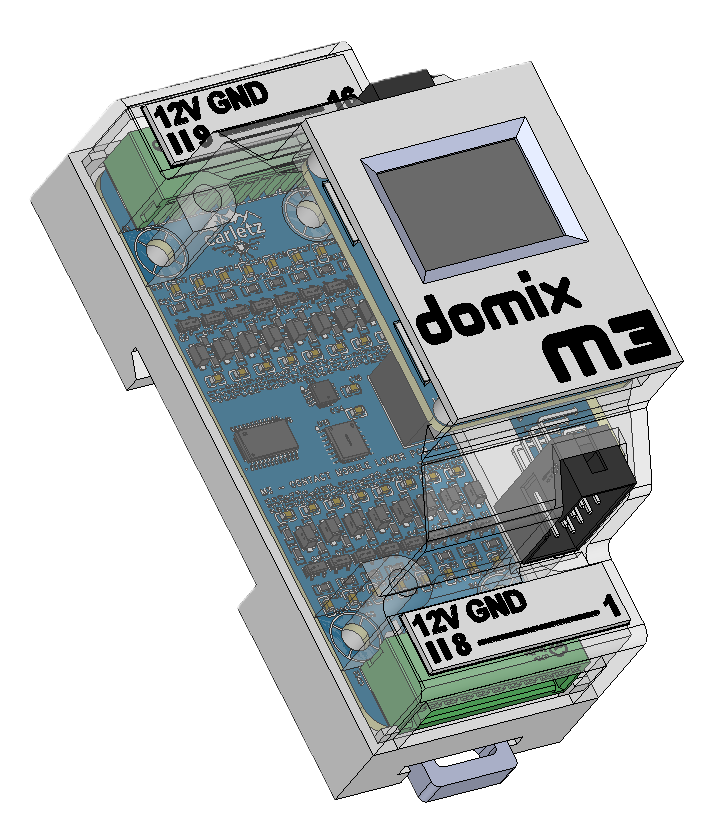
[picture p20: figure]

## M4 – Relay Module (2 DIN Units)

The M4 module provides compact relay-based outputs.
Features:
- 6 electromechanical relays
- Suitable for:
- Lights
- Small loads
- Auxiliary actuators
- Logical grouping for room-based automation
I2C addressable by dip switch on left side for each module

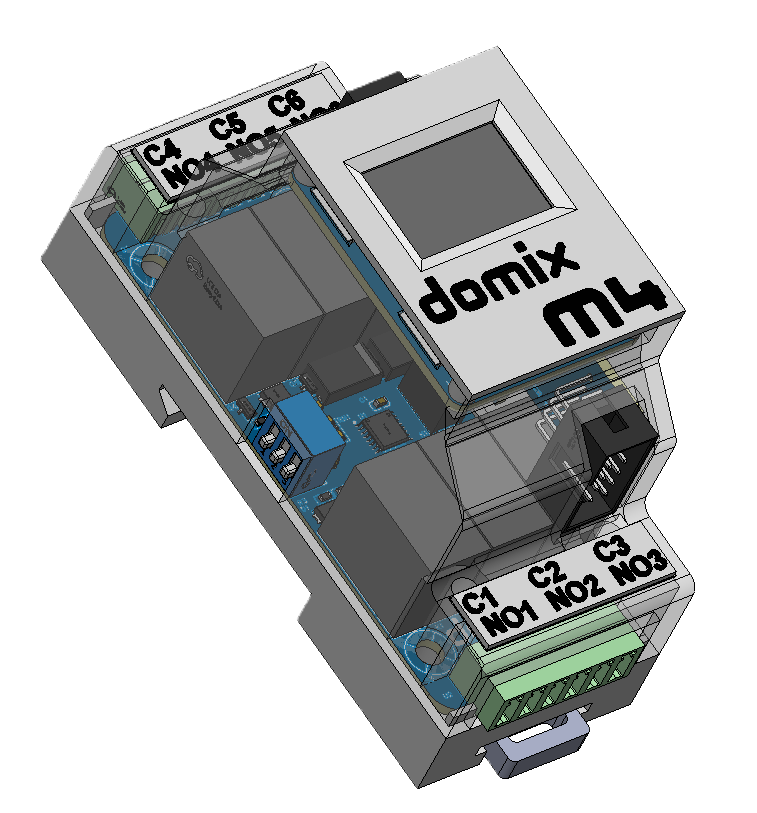
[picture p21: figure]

## M5 – Relay Module (4 DIN Units)

The M5 module provides compact relay-based outputs.
Features:
- 12 electromechanical relays
- Suitable for:
- Lights
- Small loads
- Auxiliary actuators
- Logical grouping for room-based automation
I2C addressable by dip switch on left side for each module

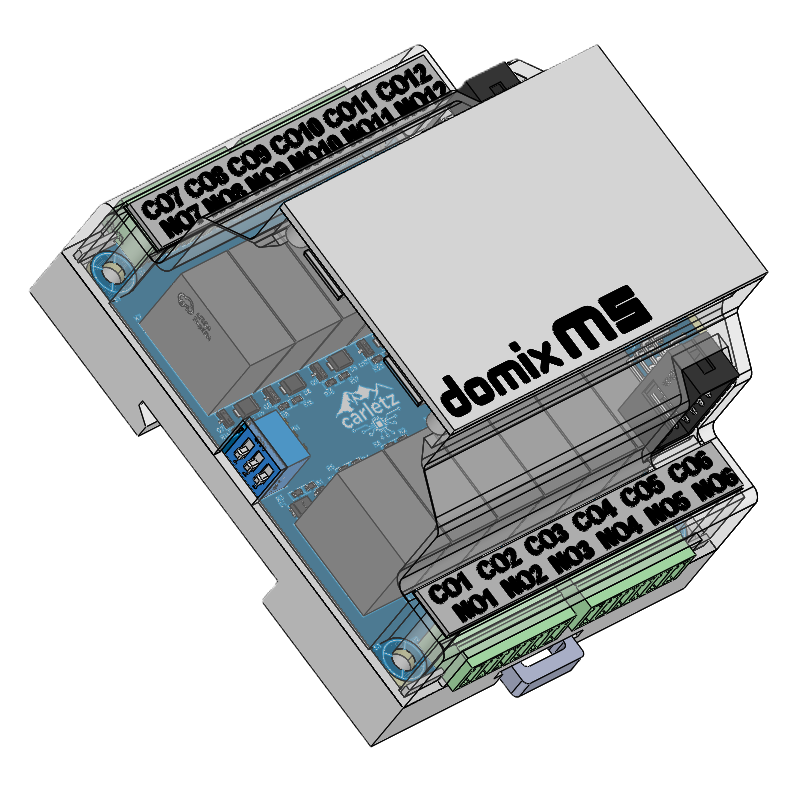
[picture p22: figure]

## M6 – Energy meter (4 DIN Units)

The M6 module provides compact current reading.
Features:
- 10-channel current monitoring
- Main Voltage reading
I2C addressable by dip switch on left side for each module

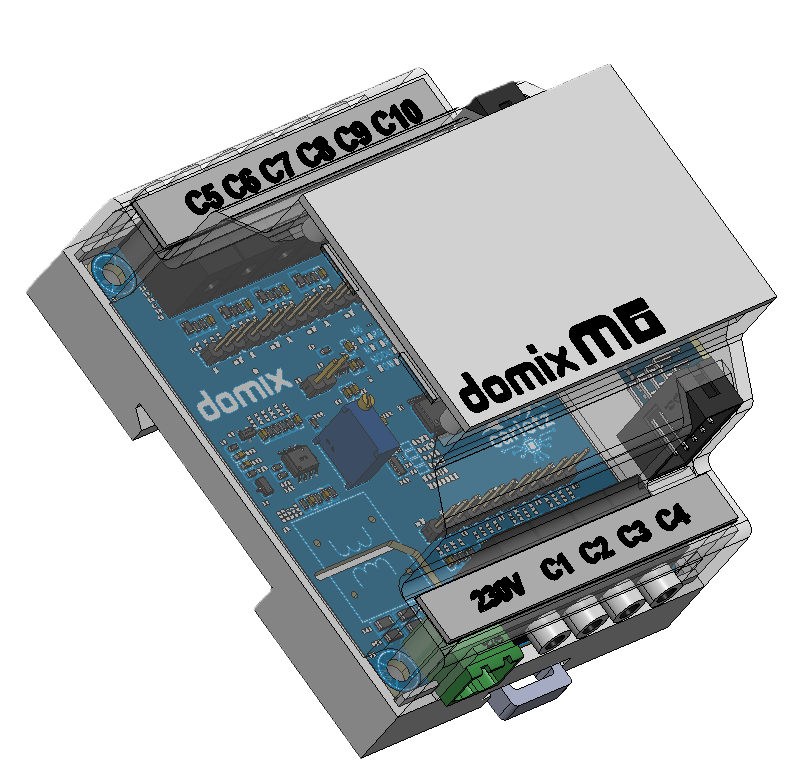
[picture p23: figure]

## M7 – Output module (2 DIN Units)

The M7 module provides compact output possibilities.
Features:
- 16 output channels low voltage
I2C addressable by dip switch on left side for each module

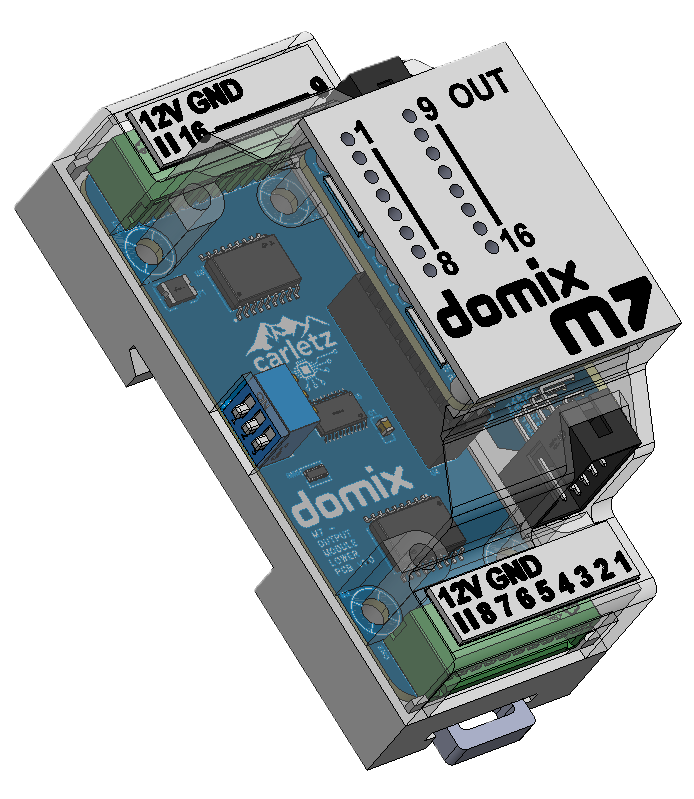
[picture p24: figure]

## M8 – Input module (2 DIN Units)

The M8 module provides compact input possibilities.
Features:
- 16 input channels low voltage
I2C addressable by dip switch on left side for each module

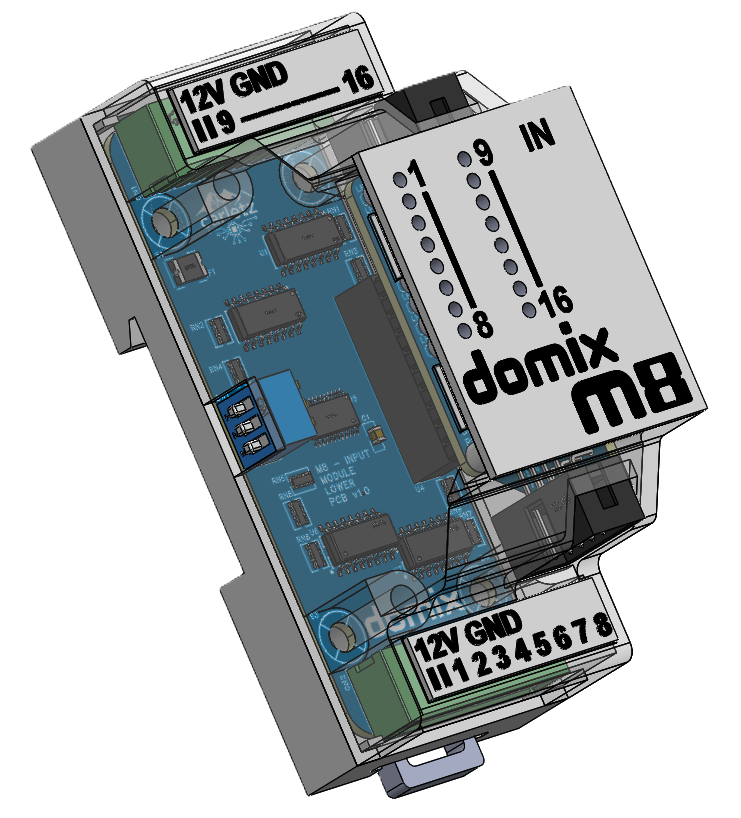
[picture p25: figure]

## M9 – Sprinkler module (4 DIN Units)

The M9 module provides sprinkler possibilities.
Features:
- 8 sprinkler 24VAC valves output
- 8 manual commands
I2C addressable by dip switch on left side for each module

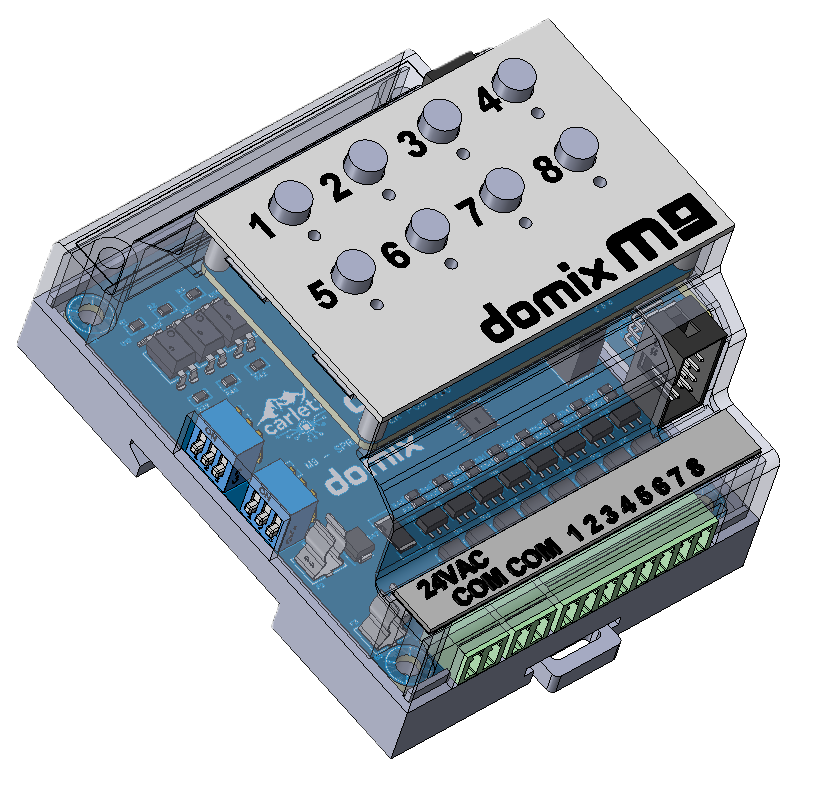
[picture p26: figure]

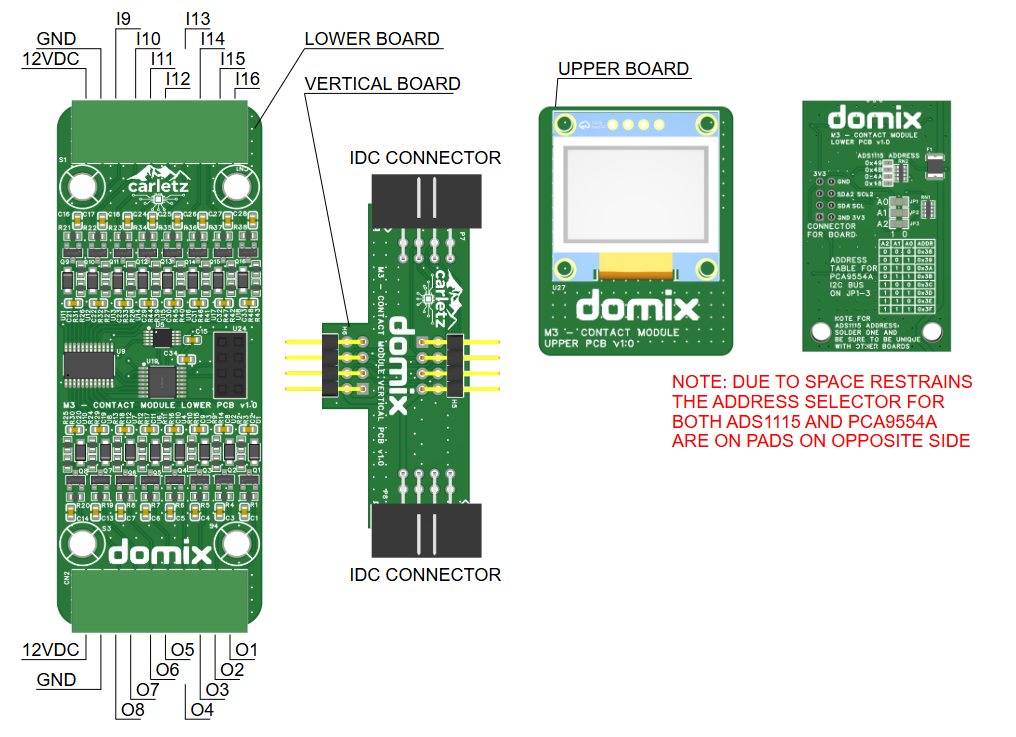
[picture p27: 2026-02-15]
Images/Board/M3/M3 - Pinout.png

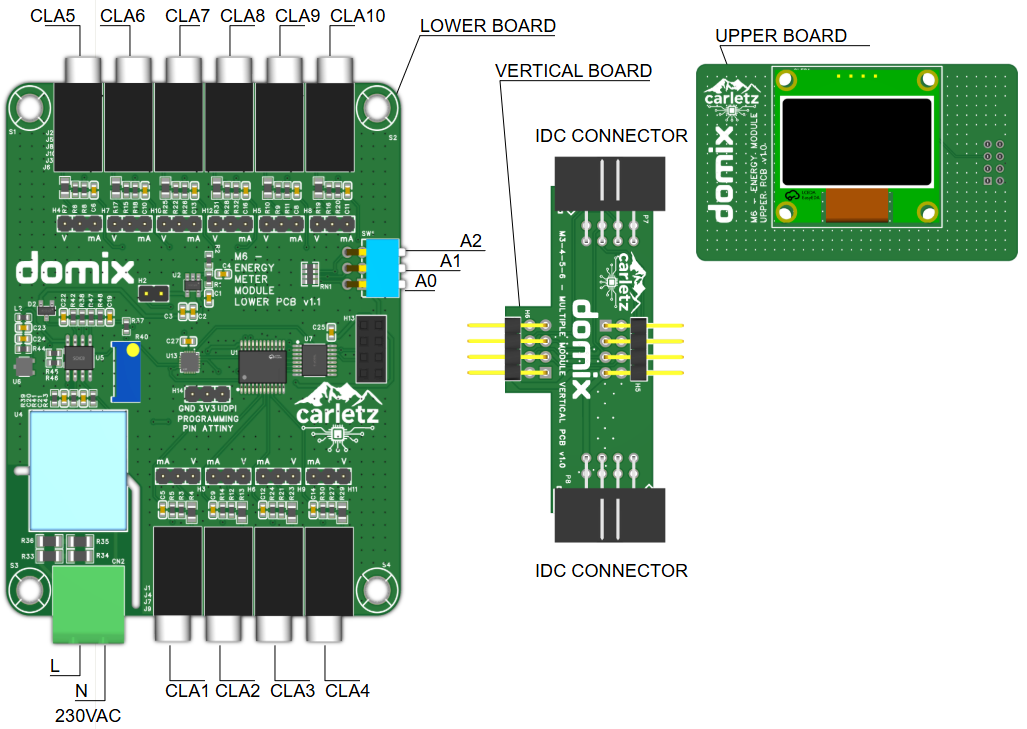
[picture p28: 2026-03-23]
Images/Board/M6/M6 - Pinout.png

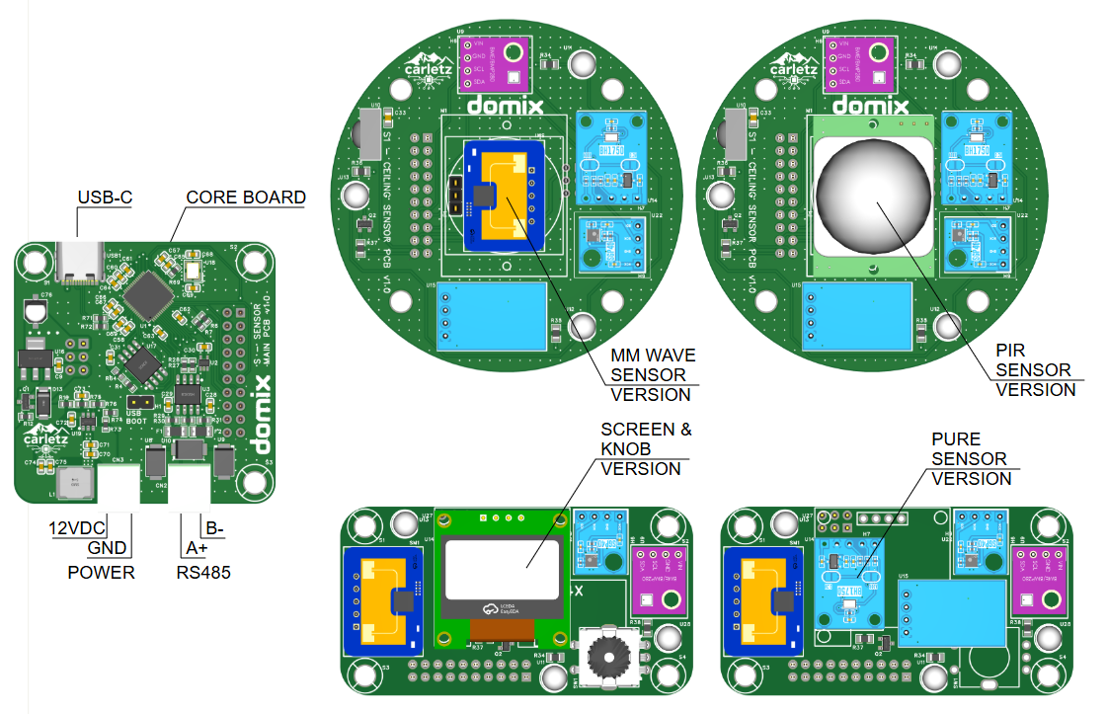
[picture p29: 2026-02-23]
Images/Board/S/S - Pinout.png

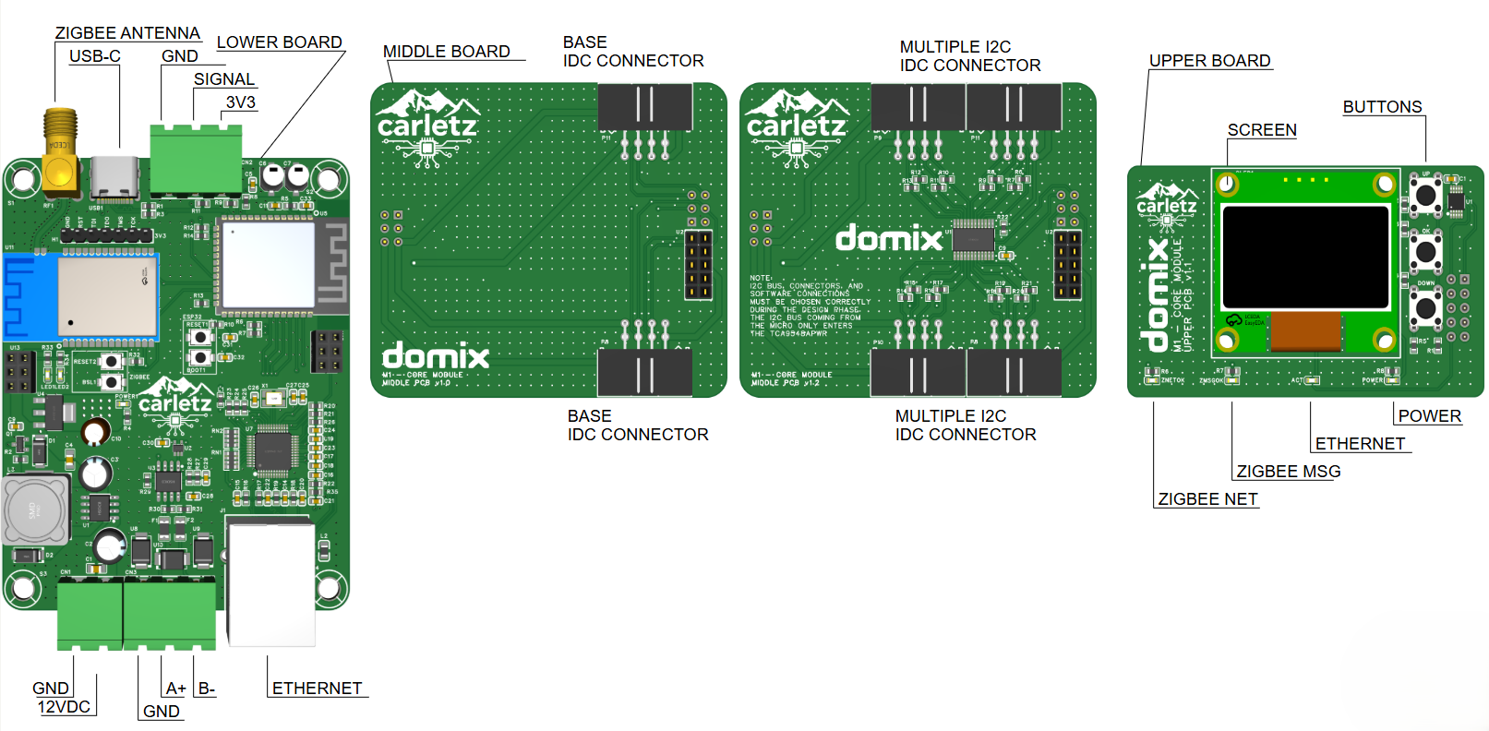
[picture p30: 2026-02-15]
Images/Board/M1/M1 - Pinout.png

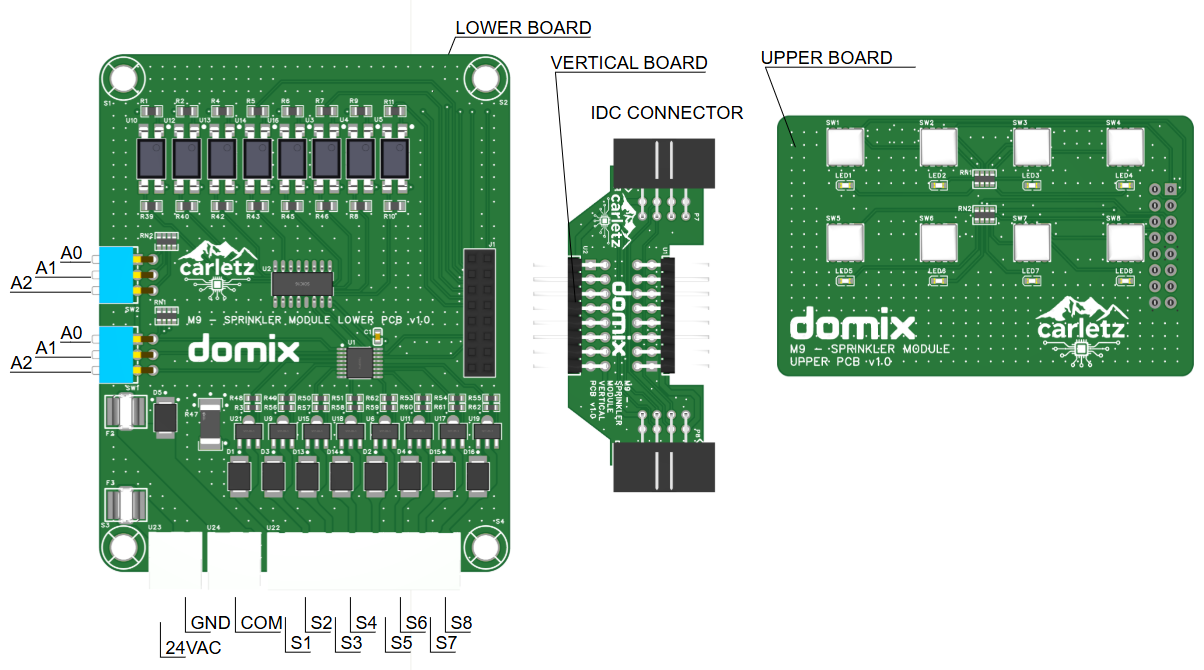
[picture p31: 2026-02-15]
Images/Board/M9/M9 - Pinout.png

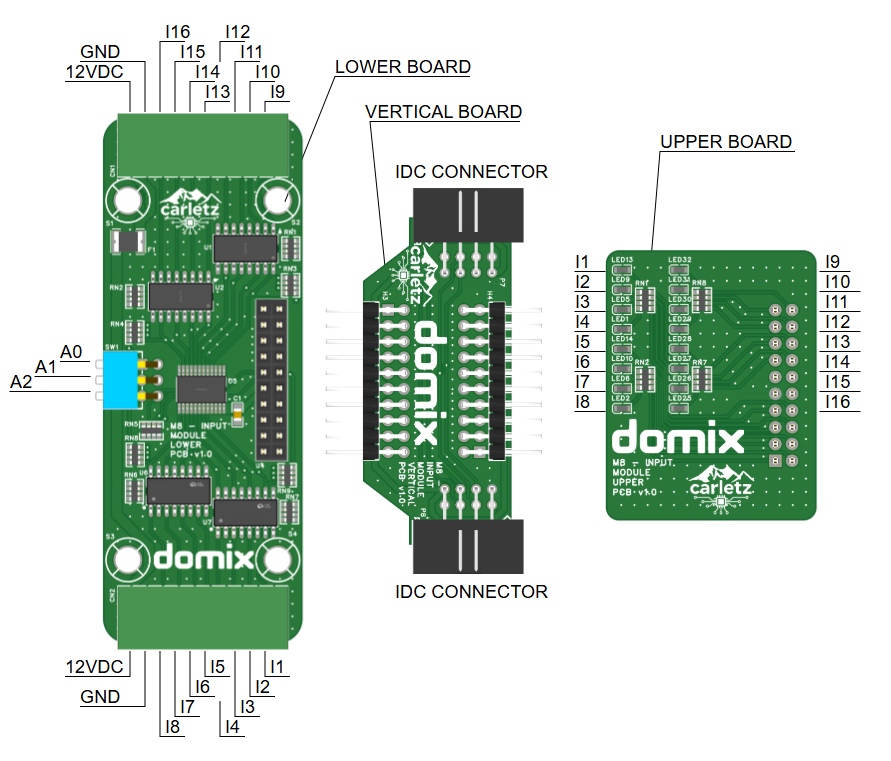
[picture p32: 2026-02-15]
Images/Board/M8/M8 - Pinout.png

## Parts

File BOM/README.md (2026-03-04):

# 📦 BOM — Bill of Materials

> **DOMIX** · Open Source Modular Home Automation System

This folder contains the **Bill of Materials (BOM)** for all DOMIX hardware modules. Each `.xlsx` file lists the components required to build a specific PCB, including part references, quantities, manufacturer part numbers, LCSC/JLCPCB codes and estimated costs.

All BOM files were exported from **EasyEDA** and are optimized for ordering directly via **LCSC** or assembly via **JLCPCB**.

---

## 📁 Folder Structure

```
BOM/
├── README.md                                              # This file
│
│   ── Main Modules (M) ──
├── BOM_M1 - CORE V1.1_M1 - Core Module V1.1.xlsx         # ESP32 core controller
├── BOM_M2 - I_O_M2 - I_O Module.xlsx                     # I/O expansion module
├── BOM_M3 - CONTACT_M3 - Contact Module.xlsx             # Dry contact inputs
├── BOM_M4 - 6 RELAY_M4 - 6 Relay Module.xlsx            # 6-channel relay board
├── BOM_M5 - 12 RELAY_M5 - 12 Relay Module.xlsx          # 12-channel relay board
├── BOM_M6 - ENERGY_M6 - Energy Meter Module.xlsx        # Energy monitoring module
├── BOM_M7 - OUTPUT_M7 - Output Module.xlsx              # Digital output module
├── BOM_M8 - INPUT_M8 - Input Module.xlsx                # Digital input module
├── BOM_M9 - SPRINKLER_M9 - Sprinkler Module.xlsx        # Irrigation/sprinkler controller
│
│   ── Sensor PCBs (S) ──
├── BOM_S  - CORE SENSOR_S - CORE SENSOR PCB.xlsx        # Core sensor board
├── BOM_S1 - CEILING SENSOR_S1 - CEILING PCB.xlsx        # Ceiling-mount sensor PCB (PIR)
├── BOM_S2 - WALL SENSOR_S2 - WALL PCB.xlsx             # Wall-mount sensor PCB
│
│   ── Upper (Display) Boards (U) ──
├── BOM_U1 - CORE - UPPER V1.1_M1 - Display Module V1.1.xlsx
├── BOM_U2 - I_O - UPPER_M2 - Display Module.xlsx
├── BOM_U3-4 - MULTI - UPPER_M3-4 - Display Module.xlsx
├── BOM_U5-6 - MULTI - UPPER_M5-6 - Display Module.xlsx
├── BOM_U7 - OUTPUT - UPPER_M7 - Display Module.xlsx
├── BOM_U8 - INPUT - UPPER_M8 - Display Module.xlsx
├── BOM_U9 - SPRINKLER - UPPER_M9 - Upper Module.xlsx
│
│   ── Vertical / Middle Interface Boards (V) ──
├── BOM_V1 - CORE - MIDDLE V1.0_M1 - Middle Module V1.0.xlsx
├── BOM_V1 - CORE - MIDDLE V1.2_M1 - Middle Module V1.2.xlsx
├── BOM_V2 - I_O - VERTICAL_M2 - Vertical Module.xlsx
├── BOM_V3-4-5-6 - MULTI - VERTICAL_M3-4-5-6 - Vertical Module.xlsx
├── BOM_V7 - OUTPUT - VERTICAL_M7 - Vertical Module.xlsx
├── BOM_V8 - INPUT - VERTICAL_M8 - Vertical Module.xlsx
└── BOM_V9 - SPRINKLER - VERTICAL_M9 - Vertical Module.xlsx
```

---

## 🧩 Modules Overview

### Main Modules (M)

| File | Description | Component Types | Total Parts |
|---|---|:---:|:---:|
| M1 — Core V1.1 | Central ESP32-based controller. Includes tactile switches, capacitors, regulators, connectors | 51 | ~101 |
| M2 — I/O | I/O expansion with terminal blocks and resettable fuse | 10 | ~15 |
| M3 — Contact | Multi-channel dry contact input board (33× decoupling caps) | 15 | ~130 |
| M4 — 6 Relay | 6-channel relay board with AO3400A MOSFETs and 1N4007F flyback diodes | 12 | ~37 |
| M5 — 12 Relay | 12-channel relay board, same topology as M4 scaled up | 12 | ~69 |
| M6 — Energy Meter | Multi-channel energy monitoring (current/voltage sensing) | 33 | ~109 |
| M7 — Output | Digital output expansion module | 8 | ~10 |
| M8 — Input | Digital input expansion module | 9 | ~20 |
| M9 — Sprinkler | Irrigation controller with TVS protection, fuse holders | 18 | ~80 |

### Sensor PCBs (S)

| File | Description | Component Types | Total Parts |
|---|---|:---:|:---:|
| S — Core Sensor | Main sensor carrier board (temp, humidity, ambient light…) | 41 | ~64 |
| S1 — Ceiling | Ceiling-mount PCB with HC-SR501 PIR motion sensor | 17 | ~24 |
| S2 — Wall | Wall-mount sensor PCB with MOSFET level shifting | 14 | ~21 |

### Upper / Display Boards (U)

| File | Description | Component Types | Total Parts |
|---|---|:---:|:---:|
| U1 — Core Upper V1.1 | Status LEDs, tactile nav buttons, 2×5 header | 11 | ~19 |
| U2 — I/O Upper | 16× red SMD LEDs with resistor arrays | 4 | ~21 |
| U3-4 — Multi Upper | OLED display (0.96", SSD1306 compatible) + 2×4 header | 2 | ~2 |
| U5-6 — Multi Upper | OLED display (1.3", SH1106 compatible) + 2×4 header | 2 | ~2 |
| U7 — Output Upper | 16× red SMD LEDs, 4× 680Ω resistor arrays | 3 | ~21 |
| U8 — Input Upper | 16× red SMD LEDs, 4× 270Ω resistor arrays | 3 | ~21 |
| U9 — Sprinkler Upper | 8× LED indicators + pushbuttons for zone control | 4 | ~19 |

### Vertical / Middle Interface Boards (V)

These are mechanical/electrical interface boards used to stack or interconnect modules. They mainly contain 2.54mm headers, IDC connectors, and pin sockets.

| File | Description |
|---|---|
| V1 — Core Middle V1.0 | IDC 2×4 + female socket connectors |
| V1 — Core Middle V1.2 | Updated version with 16× 2.2kΩ pull-up resistors |
| V2 — I/O Vertical | 2×10 right-angle pin headers + IDC connectors |
| V3-4-5-6 — Multi Vertical | Shared vertical board for relay/contact modules |
| V7 — Output Vertical | Right-angle 2×10 headers |
| V8 — Input Vertical | Right-angle 2×10 headers |
| V9 — Sprinkler Vertical | IDC 2×4 + 2×8 right-angle headers |

---

## 📋 BOM Column Reference

Each BOM file contains the following columns (EasyEDA export format):

| Column | Description |
|---|---|
| `No.` | Row number |
| `Quantity` | Number of parts required |
| `Comment` | Value or part comment (e.g. `100nF`, `10kΩ`, `G2FE-05HMV1`) |
| `Designator` | PCB reference designators (e.g. `C1, C2, R3`) |
| `Footprint` | PCB land pattern / package |
| `Value` | Electrical value |
| `Manufacturer Part` | Manufacturer Part Number (MPN) |
| `Manufacturer` | Component manufacturer |
| `Supplier Part` | LCSC Part Number (e.g. `C14663`) |
| `Supplier` | Supplier name (typically `LCSC`) |
| `LCSC Stock` | Stock quantity on LCSC at export time |
| `LCSC Price` | Unit price on LCSC (USD) at export time |
| `Primary Category` | LCSC component category |
| `Secondary Category` | LCSC component sub-category |
| `JLCPCB Stock` | Stock available for JLCPCB SMT assembly |
| `JLCPCB Price` | Price for JLCPCB SMT assembly |

---

## 🛒 Ordering Guidelines

- **LCSC** is the primary supplier — all BOM files include LCSC part numbers (`Supplier Part` column). Upload the `.xlsx` directly on [lcsc.com](https://www.lcsc.com) using the BOM import tool.
- **JLCPCB SMT Assembly** — the `JLCPCB Stock` and `JLCPCB Price` columns allow you to use these BOMs directly for [JLCPCB's assembly service](https://jlcpcb.com/smt-assembly).
- Always verify stock and pricing before ordering — values in the BOM reflect the status at export time and may have changed.
- Some components (e.g. HC-SR501 PIR module in S1) have no supplier part listed and must be sourced separately (AliExpress or local distributors).

---

## ⚙️ How to Use

1. Identify the module(s) you want to build
2. Open the corresponding BOM `.xlsx` file
3. Cross-reference the `Designator` values against the schematic in the `/Schematic` folder
4. Use the Gerber files in the `/PCB` folder to fabricate the board
5. Import the BOM into LCSC or JLCPCB for ordering / assembly

---

## 🔀 Building Multiple Modules Together — BOM Optimization

If you plan to build more than one module at a time, it is strongly recommended to **merge the individual BOMs and consolidate quantities** before ordering. Many components are shared across modules, and ordering them in bulk significantly reduces cost and shipping overhead.

### Why it matters

Many passive components (resistors, capacitors, connectors) appear in 4 to 9 different modules. For example:

| LCSC Part | Value / Description | Shared across |
|---|---|:---:|
| C14663 / C38141 | 100nF decoupling capacitor (C0603 / C0805) | 6–10 modules |
| C29718 / C2906982 | 10kΩ resistor array | 7–9 modules |
| C9139 | IDC 2×4 2.54mm connector | 7 modules |
| C389517 | MHT192CRCT red LED 0603 | 6 modules |
| C577602 | KF2EDGR-2.54-10P terminal block | 4 modules |
| C369168 | JK-MSMD050-30 resettable fuse | 4 modules |
| C255606 | PCA9535PW I²C I/O expander | 4 modules |

Ordering these separately per module means paying multiple shipping minimums and potentially not reaching the quantity discounts available on LCSC (usually at 10, 50, or 100 pieces).

### How to merge BOMs

The quickest approach is to use a spreadsheet:

1. Open all the BOM `.xlsx` files you need
2. Copy all data rows (excluding headers) into a single sheet
3. Group rows by `Supplier Part` (LCSC code) and sum the `Quantity` column
4. Add a small buffer (5–10%) for SMD components to account for placement losses
5. Use the merged sheet to place a single LCSC order

Alternatively, tools like [KiCad BOM plugins](https://github.com/SchrodingersGat/KiBoM), [InteractiveHtmlBom](https://github.com/openscopeproject/InteractiveHtmlBom), or a simple Python/Excel script can automate this consolidation.

### Tips

- Check the `JLCPCB Stock` column before ordering: parts with high JLCPCB stock are good candidates for SMT assembly rather than hand-soldering.
- Some components appear with slightly different LCSC codes across modules (e.g. two different `100nF` C0603 parts) — verify they are electrically equivalent before substituting one for the other.
- Vertical (V) and Upper (U) boards share almost exclusively passive connectors and headers, making them the easiest to batch-order together.

---

*Part of the [DOMIX Home Automation System](https://github.com/carletz/DOMIX-Open-Source-Modular-Home-Automation-System) · Made with ❤️ for the open hardware community*

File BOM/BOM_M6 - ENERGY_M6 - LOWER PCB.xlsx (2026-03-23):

No. | Quantity | Comment | Designator | Footprint | Value | Manufacturer Part | Manufacturer | Supplier Part | Supplier | LCSC Stock | LCSC Price | Primary Category | Secondary Category | Pin Count | JLCPCB Stock | JLCPCB Price | 3D Model Title | Device | Name | Unique ID | Convert to PCB | Add into BOM | Symbol
1 | 15 | 100nF | C1,C3,C5,C6,C8,C9,C10,C11,C12,C13,C14,C16,C24,C25,C27 | C0603 | 100nF | CC0603KRX7R9BB104 | YAGEO(国巨) | C14663 | LCSC |  |  | Capacitors | Multilayer Ceramic Capacitors MLCC - SMD/SMT | 2 | 43049598 | 0.0005 | C0603_L1.6-W0.8-H0.8 | CC0603KRX7R9BB104 | 100nF | gge448,gge448_1,gge448_2,gge448_3,gge448_4,gge448_5,gge448_6,gge448_7,gge448_8,gge448_9,gge448_10,gge448_11,gge448_12,gge448_13,gge448_14 |  | yes
2 | 2 | 10uF | C2,C4 | C0603 | 10uF | 0603X106K160NT | FH(风华) | C70225 | LCSC |  |  | Capacitors | Multilayer Ceramic Capacitors MLCC - SMD/SMT | 2 | 603718 | 0.0041 | C0603_L1.6-W0.8-H0.8 | 0603X106K160NT | 10uF | gge463,gge464 |  | yes
3 | 4 | 1nF | C19,C20,C21,C22 | C0603 | 1nF | CC0603KRX7R9BB102 | YAGEO(国巨) | C100040 | LCSC |  |  | Capacitors | Multilayer Ceramic Capacitors MLCC - SMD/SMT | 2 | 6110636 | 0.0004 | C0603_L1.6-W0.8-H0.8 | CC0603KRX7R9BB102 | 1nF | gge481,gge482,gge483,gge484 |  | yes
4 | 1 | 1uF | C23 | C0603 | 1uF | CL10A105KB8NNNC | SAMSUNG(三星) | C15849 | LCSC |  |  | Capacitors | Multilayer Ceramic Capacitors MLCC - SMD/SMT | 2 | 8899046 | 0.0012 | C0603_L1.6-W0.8-H0.8 | CL10A105KB8NNNC | 1uF | gge488 |  | yes
5 | 1 | WJ2EDGRC-5.08-2P | CN2 | CONN-TH_2P-P5.08_WJ2EDGRC-5.08-2P |  | WJ2EDGRC-5.08-2P | KANGNEX(康奈克斯电气) | C3697 | LCSC |  |  | Connectors | Pluggable System Terminal Block | 2 | 87462 | 0.007 | CONN-TH_2P-L12.0-W12.2-H8.3-P5.08 | WJ2EDGRC-5.08-2P | WJ2EDGRC-5.08-2P | gge35_2 |  | yes
6 | 1 | BAT54S | D2 | SOT-23-3_L2.9-W1.3-P1.90-LS2.4-BR |  | BAT54S | JSMSEMI(杰盛微) | C916425 | LCSC |  |  | Diodes | Schottky Diodes | 3 | 250795 | 0.0016 | SOT-23-3P_L2.9-W1.3-H1.0-LS2.4-P0.95 | BAT54S_C916425 | BAT54S | gge489 |  | yes
7 | 1 | B-2100S02P-A110 | H2 | HDR-TH_2P-P2.54-V-M-1 |  | B-2100S02P-A110 | Ckmtw(灿科盟) | C124375 | LCSC |  |  | Connectors | Pin Headers | 2 | 68222 | 0.0045 | HDR-M-2.54_1x2 | HDR-M_2.54_1x2P |  | gge176 |  | yes
8 | 11 | HDR-M_2.54_1x3P | H3,H4,H5,H6,H7,H8,H9,H10,H11,H12,H14 | HDR-TH_3P-P2.54-V-M |  |  |  |  |  |  | 1.2627 | Connectors | Pin Headers | 3 |  |  | HDR-TH_3P-P2.54-M-LI-1X3P | HDR-M_2.54_1x3P |  | gge150,gge155,gge160,gge160_1,gge160_2,gge160_3,gge160_4,gge160_5,gge160_6,gge165,gge502 |  | yes
9 | 1 | 2.54-2*4 | H13 | HDR-TH_8P-P2.54-V-F-R2-C4-S2.54 |  | 2.54-2*4 | ZHOURI(洲日) | C2977588 | LCSC |  |  | Connectors | Female Headers | 8 | 3043 | 0.0152 | HDR-TH_8P-P2.54-F-LI-2X4P | 2.54-2*4 | 2.54-2*4 | gge493_1 |  | yes
10 | 10 | PJ325外铜套 | J1,J2,J3,J4,J5,J6,J7,J8,J9,J10 | AUDIO-TH_PJ-325C |  | PJ325外铜套 | BOOMELE(博穆精密) | C26230 | LCSC |  |  | Connectors | Audio Connectors (Headphones) | 5 | 5014 | 0.0234 | AUDIO-TH_PJ-325C | PJ325外铜套 | PJ325外铜套 | gge149,gge154,gge159,gge159_1,gge159_2,gge159_3,gge159_4,gge159_5,gge159_6,gge164 |  | yes
11 | 1 | BLM18AG601SN1D | L2 | L0603 |  | BLM18AG601SN1D | muRata(村田) | C19330 | LCSC |  |  | Filters | Ferrite Beads | 2 | 897 | 0.0012 | L0603_L1.6-W0.8-H0.5_BEAD | BLM18AG601SN1D | BLM18AG601SN1D | gge487 |  | yes
12 | 1 | 22kΩ | R1 | R0603 | 22kΩ | FRC0603F2202TS | FOJAN(富捷) | C2907015 | LCSC |  |  | Resistors | Chip Resistor - Surface Mount | 2 | 1921689 | 0.0002 | R0603 | FRC0603F2202TS | 22kΩ | gge461 |  | yes
13 | 1 | 10kΩ | R2 | R0603 | 10kΩ | FRC0603F1002TS | FOJAN(富捷) | C2906982 | LCSC |  |  | Resistors | Chip Resistor - Surface Mount | 2 | 7858513 | 0.0002 | R0603 | FRC0603F1002TS | 10kΩ | gge462 |  | yes
14 | 11 | 1kΩ | R3,R6,R9,R12,R15,R16,R21,R22,R27,R28,R44 | R0603 | 1kΩ | ESR03EZPF1001 | ROHM(罗姆) | C2653986 | LCSC |  |  | Resistors | Chip Resistor - Surface Mount | 2 | 75013 | 0.002 | R0603 | ESR03EZPF1001 | 1kΩ | gge449,gge450,gge450_1,gge451,gge451_1,gge451_2,gge451_3,gge451_4,gge451_5,gge451_6,gge452 |  | yes
15 | 10 | 22Ω | R4,R7,R10,R13,R17,R19,R23,R25,R29,R31 | R0805 | 22Ω | ARG05BTC0220 | Viking(光颉) | C309084 | LCSC |  |  | Resistors | Chip Resistor - Surface Mount | 2 | 8828 | 0.0049 | R0805_L2.0-W1.3-H0.6 | ARG05BTC0220 | 22Ω | gge493,gge494,gge495,gge496,gge497,gge498,gge499,gge499_1,gge500,gge500_1 |  | yes
16 | 10 | 1.8kΩ | R5,R8,R11,R14,R18,R20,R24,R26,R30,R32 | R0603 | 1.8kΩ | FRC0603F1801TS | FOJAN(富捷) | C2906979 | LCSC |  |  | Resistors | Chip Resistor - Surface Mount | 2 | 309867 | 0.0002 | R0603 | FRC0603F1801TS | 1.8kΩ | gge457,gge458,gge459,gge459_1,gge459_2,gge459_3,gge459_4,gge459_5,gge459_6,gge460 |  | yes
17 | 4 | 210kΩ | R33,R34,R35,R36 | R1206 | 210kΩ | 1206W4F2103T5E | UNI-ROYAL(厚声) | C247340 | LCSC |  |  | Resistors | Chip Resistor - Surface Mount | 2 | 257 | 0.0006 | R1206_L3.2-W1.6-H0.6 | 1206W4F2103T5E | 210kΩ | gge467,gge468,gge469,gge470 |  | yes
18 | 1 | 51kΩ | R37 | R0603 | 51kΩ | 0603WAF5102T5E | UNI-ROYAL(厚声) | C23196 | LCSC |  |  | Resistors | Chip Resistor - Surface Mount | 2 | 2184463 | 0.0002 | R0603 | 0603WAF5102T5E | 51kΩ | gge480 |  | yes
19 | 6 | 10kΩ | R38,R41,R45,R46,R47,R48 | R0603 | 10kΩ | RC0603FR-0710KL | YAGEO(国巨) | C98220 | LCSC |  |  | Resistors | Chip Resistor - Surface Mount | 2 | 9131523 | 0.0003 | R0603 | RC0603FR-0710KL | 10kΩ | gge472,gge473,gge474,gge475,gge476,gge477 |  | yes
20 | 2 | 100kΩ | R39,R42 | R0603 | 100kΩ | RC0603FR-07100KL | YAGEO(国巨) | C14675 | LCSC |  |  | Resistors | Chip Resistor - Surface Mount | 2 | 2868401 | 0.0003 | R0603 | RC0603FR-07100KL | 100kΩ | gge478,gge479 |  | yes
21 | 1 | 100kΩ | R40 | RES-ADJ-TH_3P-L9.5-W4.9-P2.50-L_3296W | 100kΩ | 3296W-1-104 | BOCHEN(博晨) | C118963 | LCSC |  |  | Resistors | Potentiometers, Variable Resistors | 3 | 83936 | 0.0295 | 3296W | 3296W-1-104_C118963 | 100kΩ | gge485 |  | yes
22 | 1 | 100Ω | R43 | R0603 | 100Ω | RC0603FR-07100RL | YAGEO(国巨) | C105588 | LCSC |  |  | Resistors | Chip Resistor - Surface Mount | 2 | 3149760 | 0.0003 | R0603 | RC0603FR-07100RL | 100Ω | gge471 |  | yes
23 | 1 | 10kΩ | RN1 | RES-ARRAY-SMD_0603-8P-L3.2-W1.6-BL | 10kΩ | 4D03WGJ0103T5E | UNI-ROYAL(厚声) | C29718 | LCSC |  |  | Resistors | Resistor Networks, Arrays | 8 | 1114249 | 0.0012 | R0603-8P_L3.2-W1.6-H0.6 | 4D03WGJ0103T5E | 10kΩ | gge225 |  | yes
24 | 1 | TM-03R | SW1 | SW-TH_TM-03R |  | TM-03R | Yuandi(元迪) | C882894 | LCSC |  |  | Switches | DIP Switches | 6 | 353 | 0.0649 | SW-TH_TM-03R | TM-03R | TM-03R | gge452_1 |  | yes
25 | 1 | CD74HC4067SM96 | U1 | SSOP-24_L8.1-W5.3-P0.65-LS7.8-BL |  | CD74HC4067SM96 | TI(德州仪器) | C98457 | LCSC |  |  | Interface | Analog Switches, Multiplexers | 24 | 3055 | 0.0956 | SSOP-24_L8.2-W5.3-H1.8-LS7.8-P0.65 | CD74HC4067SM96 | CD74HC4067SM96 | gge147 |  | yes
26 | 1 | LMV321IDBVR | U2 | SOT-23-5_L3.0-W1.7-P0.95-LS2.8-BR |  | LMV321IDBVR | TI(德州仪器) | C7972 | LCSC |  |  | Amplifiers/Comparators | Operational Amplifier | 5 | 74126 | 0.0137 | SOT-23-5_L2.9-W1.6-H1.1-LS2.8-P0.95 | LMV321IDBVR_C7972 | LMV321IDBVR | gge148 |  | yes
27 | 1 | ZMPT101B | U4 | XFMR-TH_ZMPT101B |  | ZMPT101B | 择明朗熙 | C111858 | LCSC |  |  | Inductors, Coils, Chokes | Current Sense Transformers | 4 | 8569 | 0.145 | XFMR-TH_ZMPT101B | ZMPT101B | ZMPT101B | gge465 |  | yes
28 | 1 | LM358DR2G | U5 | SOIC-8_L5.0-W4.0-P1.27-LS6.0-BL |  | LM358DR2G | onsemi(安森美) | C7950 | LCSC |  |  | Amplifiers/Comparators | Operational Amplifier | 8 | 138181 | 0.0091 | SOIC-8_L5.0-W4.0-P1.27-LS6.0-BL | LM358DR2G | LM358DR2G | gge466 |  | yes
29 | 1 | CJ431 | U6 | SOT-23-3_L2.9-W1.6-P1.90-LS2.8-BR |  | CJ431 | CJ(江苏长电/长晶) | C3113 | LCSC |  |  | Power Management (PMIC) | Voltage Reference | 3 | 508008 | 0.0053 | SOT-23-3L_L2.9-W1.6-H1.1-LS2.8-P0.95 | CJ431_C3113 | CJ431 | gge486 |  | yes
30 | 1 | PCA9554APW,118 | U7 | TSSOP-16_L5.0-W4.4-P0.65-LS6.4-BL |  | PCA9554APW,118 | NXP(恩智浦) | C86803 | LCSC |  |  | Communication Interface Chip/UART/485/232 | I/O Expanders | 16 | 3526 | 0.19 | TSSOP-16_L5.0-W4.4-H1.0-LS6.4-P0.65 | PCA9554APW,118 | PCA9554APW,118 | gge53_1 |  | yes
31 | 1 | ATTINY1616-MNR | U13 | QFN-20_L3.0-W3.0-P0.40-BL-EP1.7 |  | ATTINY1616-MNR | MICROCHIP(美国微芯) | C507118 | LCSC |  |  | Embedded Processors & Controllers | Microcontrollers (MCU/MPU/SOC) | 21 | 14167 | 0.1352 | UQFN-20_L3.0-W3.0-P0.40-BL-EP1.7_MCP3564RT-E | ATTINY1616-MNR | ATTINY1616-MNR | gge501 |  | yes

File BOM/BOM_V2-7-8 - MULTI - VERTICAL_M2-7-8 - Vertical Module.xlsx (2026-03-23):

No. | Quantity | Comment | Designator | Footprint | Value | Manufacturer Part | Manufacturer | Supplier Part | Supplier | LCSC Stock | LCSC Price | Primary Category | Secondary Category | Pin Count | JLCPCB Stock | JLCPCB Price | 3D Model Title | Device | Name | Unique ID | Convert to PCB | Add into BOM | Symbol
1 | 2 | PZ254R-12-20P | H3,H4 | HDR-TH_20P-P2.54-H-M-R2-C10-S2.54 |  | PZ254R-12-20P | XFCN(兴飞) | C492438 | LCSC |  |  | Connectors | Pin Headers | 20 | 18083 | 0.0199 | HDR-TH_20P-P2.54-M-WI-2X10P | PZ254R-12-20P | PZ254R-12-20P | gge1_1,gge2_1 | yes | yes | PZ254R-12-20P
2 | 2 | 2.54-2*4P弯简牛 | P7,P8 | IDC-TH_8P-P2.54-H-R2-C4-S2.54_1 |  | 2.54-2*4P弯简牛 | BOOMELE(博穆精密) | C9139 | LCSC |  |  | Connectors | IDC Connectors | 8 | 5428 | 0.0187 |  | 2.54-2*4P弯简牛 | 2.54-2*4P弯简牛 | gge7,gge7_1 | yes | yes | IDC Box 2X4 2.54MM

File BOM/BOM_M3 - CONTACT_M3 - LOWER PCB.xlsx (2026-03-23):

No. | Quantity | Comment | Designator | Footprint | Value | Manufacturer Part | Manufacturer | Supplier Part | Supplier | LCSC Stock | LCSC Price | Primary Category | Secondary Category | Pin Count | JLCPCB Stock | JLCPCB Price | 3D Model Title | Device | Name | Unique ID | Convert to PCB | Add into BOM | Symbol
1 | 33 | 100nF | C1,C2,C3,C4,C5,C6,C7,C8,C9,C10,C11,C12,C13,C14,C16,C17,C18,C19,C20,C21,C22,C23,C24,C25,C26,C27,C28,C29,C30,C31,C32,C33,C34 | C0603 | 100nF | CC0603KRX7R9BB104 | YAGEO(国巨) | C14663 | LCSC |  |  | Capacitors | Multilayer Ceramic Capacitors MLCC - SMD/SMT | 2 | 43123689 | 0.0005 | C0603_L1.6-W0.8-H0.8 | CC0603KRX7R9BB104 | 100nF | gge195,gge197,gge202,gge203,gge209,gge210,gge216,gge217,gge223,gge224,gge228,gge230,gge232,gge235,gge241,gge249,gge251,gge257,gge259,gge261,gge263,gge265,gge267,gge270,gge276,gge284,gge286,gge292,gge294,gge296,gge297,gge300,gge448 |  | yes
2 | 1 | 1uF | C15 | C0603 | 1uF | CL10A105KA8NNNC | SAMSUNG(三星) | C5673 | LCSC |  |  | Capacitors | Multilayer Ceramic Capacitors MLCC - SMD/SMT | 2 | 1085671 | 0.0009 | C0603_L1.6-W0.8-H0.8 | CL10A105KA8NNNC | 1uF | gge38_1 |  | yes
3 | 2 | KF2EDGR-2.54-10P | CN1,CN2 | CONN-TH_10P-P2.54_KF2EDGR-2.54-10P |  | KF2EDGR-2.54-10P | KEFA(科发) | C577602 | LCSC |  |  | Connectors | Pluggable System Terminal Block | 10 | 1370 | 0.0748 | CONN-TH_10P-P2.54_KF2EDGR-2.54-10P | KF2EDGR-2.54-10P | KF2EDGR-2.54-10P | gge443,gge443_2 |  | yes
4 | 1 | JK-MSMD050-30 | F1 | F1812 |  | JK-MSMD050-30 | JK(金科) | C369168 | LCSC |  |  | Circuit Protection | Resettable Fuses | 2 | 218394 | 0.0052 | F1812_L4.5-W3.2-H1.0 | JK-MSMD050-30 | JK-MSMD050-30 | gge226_1 |  | yes
5 | 3 | SMD Jumper 3 | JP1,JP2,JP3 | SMD_JUMPER_3 |  | SMD-Jumper |  |  |  |  |  |  |  | 3 |  |  |  | SMD Jumper 3 | SMD Jumper 3 | gge256_6,gge256_7,gge256_8 |  | yes
6 | 16 | BC847B | Q1,Q2,Q3,Q4,Q5,Q6,Q7,Q8,Q9,Q10,Q11,Q12,Q13,Q14,Q15,Q16 | SOT-23-3_L2.9-W1.3-P1.90-LS2.4-BR |  | BC847B | FOSAN(富捷/富信) | C2926209 | LCSC |  |  | Transistors/Thyristors | Bipolar (BJT) | 3 | 43664 | 0.0015 | SOT-23-3P_L2.9-W1.3-H1.0-LS2.4-P0.95 | BC847B_C2926209 | BC847B | gge191,gge204,gge211,gge218,gge225,gge236,gge239,gge242,gge258,gge260,gge271,gge274,gge277,gge293,gge295,gge298 |  | yes
7 | 16 | 47kΩ | R1,R4,R5,R6,R7,R8,R19,R20,R21,R22,R23,R34,R35,R36,R37,R38 | R0603 | 47kΩ | FRC0603F4702TS | FOJAN(富捷) | C2907042 | LCSC |  |  | Resistors | Chip Resistor - Surface Mount | 2 | 1294819 | 0.0002 | R0603_NEW | FRC0603F4702TS | 47kΩ | gge194,gge201,gge208,gge215,gge222,gge229,gge231,gge245,gge254,gge255,gge264,gge266,gge280,gge289,gge290,gge302 |  | yes
8 | 32 | 1kΩ | R2,R3,R9,R10,R11,R12,R13,R14,R15,R16,R17,R18,R24,R25,R26,R27,R28,R29,R30,R31,R32,R33,R39,R40,R41,R42,R43,R44,R45,R46,R47,R48 | R0603 | 1kΩ | FRC0603F1001TS | FOJAN(富捷) | C2907002 | LCSC |  |  | Resistors | Chip Resistor - Surface Mount | 2 | 10986408 | 0.0002 | R0603_NEW | FRC0603F1001TS | 1kΩ | gge192,gge193,gge199,gge205,gge206,gge212,gge213,gge219,gge220,gge226,gge227,gge234,gge238,gge240,gge243,gge244,gge247,gge248,gge250,gge253,gge262,gge269,gge273,gge275,gge278,gge279,gge282,gge283,gge285,gge288,gge299,gge303 |  | yes
9 | 1 | 10kΩ | RN1 | RES-ARRAY-SMD_0603-8P-L3.2-W1.6-BL | 10kΩ | 4D03WGJ0103T5E | UNI-ROYAL(厚声) | C29718 | LCSC |  |  | Resistors | Resistor Networks, Arrays | 8 | 1115068 | 0.0012 | R0603-8P_L3.2-W1.6-H0.6 | 4D03WGJ0103T5E | 10kΩ | gge225_1 |  | yes
10 | 16 | SMF3.3A | U1,U2,U3,U4,U6,U7,U8,U10,U11,U12,U13,U14,U15,U16,U17,U18 | SOD-123F_L2.7-W1.7-LS3.7-RD |  | SMF3.3A | KUU | C2985624 | LCSC |  |  | Circuit Protection | ESD and Surge Protection (TVS/ESD) | 2 | 23963 | 0.0068 | SOD-123F_L2.7-W1.7-LS3.7-RD | SMF3.3A_C2985624 | SMF3.3A | gge196,gge200,gge207,gge214,gge221,gge233,gge237,gge246,gge252,gge256,gge268,gge272,gge281,gge287,gge291,gge301 |  | yes
11 | 1 | ADS1115IDGSR | U5 | MSOP-10_L3.0-W3.0-P0.50-LS5.0-BL |  | ADS1115IDGSR | TI(德州仪器) | C37593 | LCSC |  |  | Data Acquisition | Analog to Digital Converters (ADC) | 10 | 5171 | 0.2715 | MSOP-10_L3.0-W3.0-H1.1-LS5.0-P0.50 | ADS1115IDGSR | ADS1115IDGSR | gge190 |  | yes
12 | 1 | CD74HC4067PWR | U9 | TSSOP-24_L7.8-W4.4-P0.65-LS6.4-BL_1 |  | CD74HC4067PWR | TI(德州仪器) | C47361296 | LCSC |  |  | Interface | Analog Switches, Multiplexers | 24 | 353 | 0.1389 | TSSOP-24_L7.8-W4.4-P0.65-LS6.4-BL_1 | CD74HC4067PWR | CD74HC4067PWR | gge198 |  | yes
13 | 1 | PCA9554APW,118 | U19 | TSSOP-16_L5.0-W4.4-P0.65-LS6.4-BL |  | PCA9554APW,118 | NXP(恩智浦) | C86803 | LCSC |  |  | Communication Interface Chip/UART/485/232 | I/O Expanders | 16 | 3526 | 0.19 | TSSOP-16_L5.0-W4.4-H1.0-LS6.4-P0.65 | PCA9554APW,118 | PCA9554APW,118 | gge53_1 |  | yes
14 | 4 | solder_jumper_0603 | U20,U21,U22,U23 | solder_pad_0603_ftpr |  |  |  |  |  |  | 24.6915 |  |  | 2 |  |  |  | solder_jumper_0603 |  | gge491,gge491_1,gge491_2,gge492 |  | yes
15 | 1 | 2.54-2*4 | U24 | HDR-TH_8P-P2.54-V-F-R2-C4-S2.54 |  | 2.54-2*4 | ZHOURI(洲日) | C2977588 | LCSC |  |  | Connectors | Female Headers | 8 | 3043 | 0.0152 | HDR-TH_8P-P2.54-F-LI-2X4P | 2.54-2*4 | 2.54-2*4 | gge493 |  | yes

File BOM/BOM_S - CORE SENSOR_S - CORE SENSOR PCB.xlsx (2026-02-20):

No. | Quantity | Comment | Designator | Footprint | Value | Manufacturer Part | Manufacturer | Supplier Part | Supplier | LCSC Stock | LCSC Price | Primary Category | Secondary Category | Pin Count | JLCPCB Stock | JLCPCB Price | 3D Model Title | Device | Name | Unique ID | Convert to PCB | Add into BOM | Symbol
1 | 1 | 10uF | C9 | C0603 | 10uF | CL10A106KP8NNNC | SAMSUNG(三星) | C19702 | LCSC |  |  | Capacitors | Multilayer Ceramic Capacitors MLCC - SMD/SMT | 2 | 18439370 | 0.001 | C0603_L1.6-W0.8-H0.8 | CL10A106KP8NNNC | 10uF | gge432 |  | yes
2 | 1 | 10uF | C28 | C0603 | 10uF | HGC0603R5106K160NTHJ | Chinocera(华瓷) | C7432767 | LCSC |  |  | Capacitors | Multilayer Ceramic Capacitors MLCC - SMD/SMT | 2 | 148881 | 0.0023 | C0603_L1.6-W0.8-H0.8 | HGC0603R5106K160NTHJ | 10uF | gge303_1 |  | yes
3 | 2 | 100nF | C29,C30 | C0603 | 100nF | CC0603KRX7R0BB104 | YAGEO(国巨) | C113803 | LCSC |  |  | Capacitors | Multilayer Ceramic Capacitors MLCC - SMD/SMT | 2 | 443518 | 0.0007 | C0603_L1.6-W0.8-H0.8 | CC0603KRX7R0BB104 | 100nF | gge299_1,gge299_2 |  | yes
4 | 10 | 100nF | C31,C57,C58,C59,C60,C61,C62,C63,C64,C65 | C0603 | 100nF | CC0603KRX7R9BB104 | YAGEO(国巨) | C14663 | LCSC |  |  | Capacitors | Multilayer Ceramic Capacitors MLCC - SMD/SMT | 2 | 65566494 | 0.0004 | C0603_L1.6-W0.8-H0.8 | CC0603KRX7R9BB104 | 100nF | gge300,gge300_1,gge300_2,gge300_3,gge300_4,gge300_5,gge300_6,gge300_7,gge300_8,gge300_9 |  | yes
5 | 2 | 1uF | C66,C67 | C0603 | 1uF | CL10A105KO8NNNC | SAMSUNG(三星) | C1592 | LCSC |  |  | Capacitors | Multilayer Ceramic Capacitors MLCC - SMD/SMT | 2 | 2313809 | 0.0008 | C0603_L1.6-W0.8-H0.8 | CL10A105KO8NNNC | 1uF | gge447,gge448 |  | yes
6 | 2 | 15pF | C68,C69 | C0603 | 15pF | GCM1885C2A150FA16D | muRata(村田) | C882576 | LCSC |  |  | Capacitors | Multilayer Ceramic Capacitors MLCC - SMD/SMT | 2 | 1749 | 0.0075 | C0603_L1.6-W0.8-H0.8 | GCM1885C2A150FA16D | 15pF | gge449,gge450 |  | yes
7 | 1 | 10uF | C70 | C0603 | 10uF | HGC0603R5106M350NTHJ | Chinocera(华瓷) | C22367827 | LCSC |  |  | Capacitors | Multilayer Ceramic Capacitors MLCC - SMD/SMT | 2 | 165403 | 0.0046 | C0603_L1.6-W0.8-H0.8 | HGC0603R5106M350NTHJ | 10uF | gge434 |  | yes
8 | 2 | 100nF | C71,C72 | C0603 | 100nF | TCC0603X7R104K250CT | CCTC(三环) | C7501158 | LCSC |  |  | Capacitors | Multilayer Ceramic Capacitors MLCC - SMD/SMT | 2 | 1957574 | 0.0004 | C0603_L1.6-W0.8-H0.8 | TCC0603X7R104K250CT | 100nF | gge435,gge436 |  | yes
9 | 1 | 75pF | C73 | C0603 | 75pF | 0603CG750J500NT | FH(风华) | C1681 | LCSC |  |  | Capacitors | Multilayer Ceramic Capacitors MLCC - SMD/SMT | 2 | 232606 | 0.0007 | C0603_L1.6-W0.8-H0.8 | 0603CG750J500NT | 75pF | gge441 |  | yes
10 | 2 | 22uF | C74,C75 | C0603 | 22uF | CL10A226MP8NUNE | SAMSUNG(三星) | C86295 | LCSC |  |  | Capacitors | Multilayer Ceramic Capacitors MLCC - SMD/SMT | 2 | 3513645 | 0.0022 | C0603_L1.6-W0.8-H0.8 | CL10A226MP8NUNE | 22uF | gge442,gge443 |  | yes
11 | 1 | 22uF | C76 | CAP-SMD_BD4.0-L4.3-W4.3-LS5.3-FD | 22uF | VS1226M0JC54TRS0 | MAN YUE(万裕科技) | C2888093 | LCSC |  |  | Capacitors | Aluminum Electrolytic Capacitors - SMD | 2 | 15280 | 0.003 | CAP-SMD_BD4.0-L4.3-W4.3-LS5.3-FD | VS1226M0JC54TRS0 | 22uF | gge451 |  | yes
12 | 2 | MX15EDGRC-3.5-02P-GN01-Cu-A | CN2,CN3 | CONN-TH_2P-P3.50_WJ15EDGRC-3.5-2P |  | MX15EDGRC-3.5-02P-GN01-Cu-A | MAX(迈旭) | C5188295 | LCSC |  |  | Connectors | Pluggable System Terminal Block | 2 | 35770 | 0.0058 | CONN-TH_2P-P3.50_WJ15EDGRC-3.5-2P | MX15EDGRC-3.5-02P-GN01-Cu-A | MX15EDGRC-3.5-02P-GN01-Cu-A | gge454,gge455 |  | yes
13 | 1 | 1N5819 | D13 | SMA_L4.4-W2.6-LS5.0-RD |  | 1N5819 | KEXIN(科信) | C437199 | LCSC |  |  | Diodes | Schottky Diodes | 2 | 340527 | 0.003 | SMA_L4.4-W2.6-LS5.0-RD | 1N5819_C437199 | 1N5819 | gge261_1 |  | yes
14 | 2 | nSMD005 | F1,F2 | F1206 |  | nSMD005 | 台湾陆海 | C70064 | LCSC |  |  | Circuit Protection | Resettable Fuses | 2 | 280343 | 0.0049 | F1206_L3.2-W1.7-H0.6 | nSMD005_C70064 | nSMD005 | gge180_1,gge183_1 |  | yes
15 | 1 | HDR-M_2.54_1x2P | H1 | HDR-TH_2P-P2.54-V-M-1 |  |  |  |  |  |  | 3.7391 | Connectors | Pin Headers | 2 |  |  | HDR-M-2.54_1x2 | HDR-M_2.54_1x2P |  | gge252 |  | yes
16 | 1 | PZ254V-12-20P | H4 | HDR-TH_20P-P2.54-V-M-R2-C10-S2.54 |  | PZ254V-12-20P | XFCN(兴飞) | C492427 | LCSC |  |  | Connectors | Pin Headers | 20 | 35742 | 0.0169 | HDR-TH_20P-P2.54-V-M-R2-C10-S2.54-1 | PZ254V-12-20P | PZ254V-12-20P | gge458 |  | yes
17 | 1 | PH2.54-2X3P-H25 | H5 | HDR-TH_6P-P2.54-V-M-R2-C3-S2.54-1 |  | PH2.54-2X3P-H25 | JXTCONN(聚兴泰) | C42431837 | LCSC |  |  | Connectors | Pin Headers | 6 | 31105 | 0.0047 | HDR2.54-M-LI-2x3P | PH2.54-2X3P-H25 | PH2.54-2X3P-H25 | gge459 |  | yes
18 | 1 | 10uH | L1 | IND-SMD_L6.0-W6.0 | 10uH | YNR6045-100M | YJYCOIN(益嘉源) | C341067 | LCSC |  |  | Inductors, Coils, Chokes | Power Inductors | 2 | 31431 | 0.0122 | IND-SMD_L6.0-W6.0-H4.5 | YNR6045-100M | 10uH | gge444 |  | yes
19 | 1 | WPM2015-3/TR | Q1 | SOT-23-3_L2.9-W1.3-P1.90-LS2.4-BR |  | WPM2015-3/TR | KUU | C6562215 | LCSC |  |  | Transistors/Thyristors | MOSFETs | 3 | 14119 | 0.0064 | SOT-23-3P_L2.9-W1.3-H1.0-LS2.4-P0.95 | WPM2015-3/TR_C6562215 | WPM2015-3/TR | gge262_1 |  | yes
20 | 2 | 1kΩ | R4,R69 | R0603 | 1kΩ | RS-03K1001FT | FH(风华) | C115325 | LCSC |  |  | Resistors | Chip Resistor - Surface Mount | 2 | 4225040 | 0.0003 | R0603 | RS-03K1001FT | 1kΩ | gge46,gge46_3 |  | yes
21 | 2 | 2.2kΩ | R6,R7 | R0603 | 2.2kΩ | FRC0603F2201TS | FOJAN(富捷) | C2907005 | LCSC |  |  | Resistors | Chip Resistor - Surface Mount | 2 | 3474800 | 0.0002 | R0603 | FRC0603F2201TS | 2.2kΩ | gge435_1,gge436_1 |  | yes
22 | 1 | 10kΩ | R12 | R0603 | 10kΩ | FRC0603F1002TS | FOJAN(富捷) | C2906982 | LCSC |  |  | Resistors | Chip Resistor - Surface Mount | 2 | 15159557 | 0.0002 | R0603 | FRC0603F1002TS | 10kΩ | gge422 |  | yes
23 | 1 | 49.9Ω | R16 | R0603 | 49.9Ω | FRC0603F49R9TS | FOJAN(富捷) | C2930110 | LCSC |  |  | Resistors | Chip Resistor - Surface Mount | 2 | 601975 | 0.0002 | R0603 | FRC0603F49R9TS | 49.9Ω | gge313_1 |  | yes
24 | 2 | 10kΩ | R27,R28 | R0603 | 10kΩ | RC0603FR-0710KL | YAGEO(国巨) | C98220 | LCSC |  |  | Resistors | Chip Resistor - Surface Mount | 2 | 9442432 | 0.0003 | R0603 | RC0603FR-0710KL | 10kΩ | gge295_1,gge295_2 |  | yes
25 | 2 | 4.7kΩ | R29,R31 | R0603 | 4.7kΩ | 0603WAF4701T5E | UNI-ROYAL(厚声) | C23162 | LCSC |  |  | Resistors | Chip Resistor - Surface Mount | 2 | 30137262 | 0.0002 | R0603 | 0603WAF4701T5E | 4.7kΩ | gge319,gge320 |  | yes
26 | 1 | 120Ω | R30 | R0603 | 120Ω | 0603WAF1200T5E | UNI-ROYAL(厚声) | C22787 | LCSC |  |  | Resistors | Chip Resistor - Surface Mount | 2 | 1777583 | 0.0002 | R0603 | 0603WAF1200T5E | 120Ω | gge321 |  | yes
27 | 1 | DNF | R64 | R0603 | DNF |  |  |  |  |  |  | Resistors | Chip Resistor - Surface Mount | 2 |  |  | R0402_L1.0-W0.5-H0.4 | 0402WGF0000TCE | DNF | gge33_1 |  | yes
28 | 2 | 27.4Ω | R71,R72 | R0603 | 27.4Ω | FRC0603F27R4TS | FOJAN(富捷) | C5126244 | LCSC |  |  | Resistors | Chip Resistor - Surface Mount | 2 | 35527 | 0.0002 | R0603 | FRC0603F27R4TS | 27.4Ω | gge445,gge446 |  | yes
29 | 1 | 511kΩ | R73 | R0603 | 511kΩ | 0603WAF5113T5E | UNI-ROYAL(厚声) | C23194 | LCSC |  |  | Resistors | Chip Resistor - Surface Mount | 2 | 128934 | 0.0002 | R0603 | 0603WAF5113T5E | 511kΩ | gge437 |  | yes
30 | 1 | 105kΩ | R74 | R0603 | 105kΩ | 0603WAF1053T5E | UNI-ROYAL(厚声) | C16840 | LCSC |  |  | Resistors | Chip Resistor - Surface Mount | 2 | 235498 | 0.0002 | R0603 | 0603WAF1053T5E | 105kΩ | gge438 |  | yes
31 | 1 | 100kΩ | R75 | R0603 | 100kΩ | 0603WAF1003T5E | UNI-ROYAL(厚声) | C25803 | LCSC |  |  | Resistors | Chip Resistor - Surface Mount | 2 | 8581223 | 0.0002 | R0603 | 0603WAF1003T5E | 100kΩ | gge439 |  | yes
32 | 1 | 13.3kΩ | R76 | R0603 | 13.3kΩ | 0603WAF1332T5E | UNI-ROYAL(厚声) | C25952 | LCSC |  |  | Resistors | Chip Resistor - Surface Mount | 2 | 95306 | 0.0002 | R0603 | 0603WAF1332T5E | 13.3kΩ | gge440 |  | yes
33 | 1 | RP2040 | U1 | LQFN-56_L7.0-W7.0-P0.4-EP |  | RP2040 | Raspberry Pi(树莓派) | C2040 | LCSC |  |  | Embedded Processors & Controllers | Microcontrollers (MCU/MPU/SOC) | 57 | 207293 | 0.142 | LQFN-56_L7.0-W7.0-P0.4-EP | RP2040_C2040 | RP2040 | gge243 |  | yes
34 | 1 | SN74LVC1G125DCKR | U2 | SOT-353_L2.2-W1.4-P0.65-LS2.4-BR |  | SN74LVC1G125DCKR | TI(德州仪器) | C7833 | LCSC |  |  | Logic | Buffers, Drivers, Receivers, Transceivers | 5 | 3542 | 0.0093 | SOT-353-5P_L2.0-W1.3-H1.1-LS2.0-P0.65 | SN74LVC1G125DCKR | SN74LVC1G125DCKR | gge179_1 |  | yes
35 | 1 | MAX13487EESA+T | U3 | SOIC-8_L4.9-W3.9-P1.27-LS6.0-BL |  | MAX13487EESA+T | ADI(亚德诺)/MAXIM(美信) | C18347 | LCSC |  |  | Interface | RS-485 / RS-422 ICs | 8 | 62975 | 0.1383 | HSOIC-8_L4.9-W3.9-H1.7-LS6.0-P1.27 | MAX13487EESA+T | MAX13487EESA+T | gge178_1 |  | yes
36 | 3 | SMBJ6.8A | U8,U9,U10 | SMB_L4.5-W3.7-LS5.4-RD |  | SMBJ6.8A | UMW(友台半导体) | C3001971 | LCSC |  |  | Circuit Protection | ESD and Surge Protection (TVS/ESD) | 2 | 1037 | 0.0047 | SMB_L4.5-W3.7-LS5.4-RD | SMBJ6.8A_C3001971 | SMBJ6.8A | gge259_1,gge259_2,gge259_3 |  | yes
37 | 1 | BL1117-33CX | U16 | SOT-223-4_L6.5-W3.5-P2.30-LS7.0-BR |  | BL1117-33CX | BL(上海贝岭) | C5400 | LCSC |  |  | Power Management (PMIC) | Voltage Regulators - Linear, Low Drop Out (LDO) Regulators | 4 | 97879 | 0.008 | SOT-223-4P_L6.5-W3.5-H1.6-LS7.0-P2.30 | BL1117-33CX | BL1117-33CX | gge46_1 |  | yes
38 | 1 | W25Q128JVSIQ | U17 | SOIC-8_L5.3-W5.3-P1.27-LS8.0-BL |  | W25Q128JVSIQ | Winbond(华邦) | C97521 | LCSC |  |  | Memory | NOR FLASH | 8 | 126671 | 0.3423 | SOIC-8_L5.3-W5.3-H1.9-LS7.9-P1.27 | W25Q128JVSIQ | W25Q128JVSIQ | gge248 |  | yes
39 | 1 | ABM8-272-T3 | U18 | CRYSTAL-SMD_4P-L3.2-W2.5-BL |  | ABM8-272-T3 | ABRACON | C20625731 | LCSC |  |  | Crystals, Oscillators, Resonators | Crystals | 4 | 1102 | 0.0482 | CRYSTAL-SMD_4P-L3.2-W2.5-BL | ABM8-272-T3_C20625731 | ABM8-272-T3 | gge249 |  | yes
40 | 1 | TPS54302DDCR | U19 | SOT-23-6_L2.9-W1.6-P0.95-LS2.8-BL |  | TPS54302DDCR | TI(德州仪器) | C311983 | LCSC |  |  | Power Management (PMIC) | DC-DC Converters | 6 | 217556 | 0.0223 | SOT-23-6_L2.9-W1.6-H1.5-LS2.8-P0.95 | TPS54302DDCR_C311983 | TPS54302DDCR | gge433 |  | yes
41 | 1 | TYPE-C 16PIN 2MD(073) | USB1 | USB-C-SMD_TYPE-C-6PIN-2MD-073 |  | TYPE-C 16PIN 2MD(073) | SHOU HAN(首韩) | C2765186 | LCSC |  |  | Connectors | USB Connectors | 16 | 994364 | 0.0096 | USB-C-SMD_TYPE-C-6PIN-2MD-073 | TYPE-C 16PIN 2MD(073) | TYPE-C 16PIN 2MD(073) | gge130_1 |  | yes

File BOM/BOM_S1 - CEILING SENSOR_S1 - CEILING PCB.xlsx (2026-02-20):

No. | Quantity | Comment | Designator | Footprint | Value | Manufacturer Part | Manufacturer | Supplier Part | Supplier | LCSC Stock | LCSC Price | Primary Category | Secondary Category | Pin Count | JLCPCB Stock | JLCPCB Price | 3D Model Title | Device | Name | Unique ID | Convert to PCB | Add into BOM | Symbol
1 | 1 | 100nF | C33 | C0805 | 100nF | CL21B104KCFNNNE | SAMSUNG(三星) | C28233 | LCSC |  |  | Capacitors | Multilayer Ceramic Capacitors MLCC - SMD/SMT | 2 | 2694165 | 0.0013 | C0805_L2.0-W1.3-H1.3 | CL21B104KCFNNNE | 100nF | gge217_1 |  | yes
2 | 1 | 2.54-1*5P母 | H5 | HDR-TH_5P-P2.54-V-F |  | 2.54-1*5P母 | BOOMELE(博穆精密) | C50950 | LCSC |  |  | Connectors | Female Headers | 5 | 63949 | 0.0098 | HDR-TH_5P-P2.54-V-F | HDR-F_2.54_1x5P |  | gge305 |  | yes
3 | 4 | 2.54-1*4P母 | H6,H7,H8,H9 | HDR-TH_4P-P2.54-V-F |  | 2.54-1*4P母 | BOOMELE(博穆精密) | C2718488 | LCSC |  |  | Connectors | Female Headers | 4 | 106406 | 0.0087 | HDR-TH_4P-P2.54-V-F_801-87-004-10-001101 | 2.54-1*4P母 | 2.54-1*4P母 | gge302,gge303,gge304,gge304_1 |  | yes
4 | 1 | PIR_HC-SR501 | M1 | PIR_HC-SR501 |  |  |  |  |  |  |  | SENSOR |  | 3 |  |  | HC-SR-501 PIR Module | PIR_HC-SR501 | PIR_HC-SR501 | gge460 |  | yes
5 | 1 | 2.54-1*3P母 | P1 | HDR-TH_3P-P2.54-V-F |  | 2.54-1*3P母 | BOOMELE(博穆精密) | C146243 | LCSC |  |  | Connectors | Female Headers | 3 | 19030 | 0.0096 | HDR2.54-F-LI-1X3P | 2.54-1*3P母 | 2.54-1*3P母 | gge461 |  | yes
6 | 1 | BSS138BK | Q2 | SOT-23-3_L2.9-W1.3-P1.90-LS2.4-BR |  | BSS138BK | ElecSuper(静芯微) | C5224267 | LCSC |  |  | Transistors/Thyristors | MOSFETs | 3 | 44747 | 0.0014 | SOT-23-3P_L2.9-W1.3-H1.0-LS2.4-P0.95 | BSS138BK | BSS138BK | gge292 |  | yes
7 | 3 | 24Ω | R34,R35,R36 | R0805 | 24Ω | 0805W8F240JT5E | UNI-ROYAL(厚声) | C17576 | LCSC |  |  | Resistors | Chip Resistor - Surface Mount | 2 | 8222 | 0.0004 | R0805_L2.0-W1.3-H0.6 | 0805W8F240JT5E | 24Ω | gge293,gge294,gge295 |  | yes
8 | 1 | 2kΩ | R37 | R0805 | 2kΩ | 0805W8J0202T5E | UNI-ROYAL(厚声) | C1359 | LCSC |  |  | Resistors | Chip Resistor - Surface Mount | 2 | 343624 | 0.0003 | R0805_L2.0-W1.3-H0.6 | 0805W8J0202T5E | 2kΩ | gge253_2 |  | yes
9 | 1 | HLK-LD2410C-P | SM1 | SENSOR-TH_HLK-LD2410C-P |  | HLK-LD2410C-P | HI-LINK(海凌科) | C19723500 | LCSC |  |  | Sensors | Sensor Modules | 0 | 596 | 0.7313 | SENSOR-TH_HLK-LD2410C-P | HLK-LD2410C-P | HLK-LD2410C-P | gge288 |  | yes
10 | 1 | BME280 | U9 | BME280 |  |  |  |  |  |  | 22.5840 |  |  | 4 |  |  | GY-BME280 | BME280 |  | gge286 |  | yes
11 | 1 | TSOP31240 | U10 | SENSOR-TH_TSOP31256 |  | TSOP31240 | VISHAY(威世) | C3742906 | LCSC |  |  | Optoelectronics | Infrared Remote Receiver (IRM) | 3 | 0 | 0.0963 | SENSOR-TH_TSOP31256 | TSOP31240 | TSOP31240 | gge296 |  | yes
12 | 3 | SFH 4546 | U11,U12,U13 | LED-TH_BD5.6-P2.54-FD |  | SFH 4546 | OSRAM(欧司朗) | C2900373 | LCSC |  |  | Optoelectronics | Infrared LED Emitters | 2 | 485 | 0.0904 | LED-TH_BD5.6-P2.50-RD_1 | SFH 4546 | SFH 4546 | gge289,gge290,gge291 |  | yes
13 | 1 | BH1750 | U14 | BH1750 |  |  |  |  |  |  | 22.5840 |  |  | 0 |  |  | 3D_BH1750_PCB | BH1750 |  | gge306 |  | yes
14 | 1 | SCD41 | U15 | SCD40/SCD41 MODULE |  |  |  |  |  |  | 22.5840 | Sensores |  | 4 |  |  | 3D_SCD41_PCB | SCD41 |  | gge297 |  | yes
15 | 1 | PM254-2-10-Z-8.5 | U20 | HDR-TH_20P-P2.54-V-F-R2-C10-S2.54 |  | PM254-2-10-Z-8.5 | HCTL(华灿天禄) | C2897411 | LCSC |  |  | Connectors | Female Headers | 20 | 22063 | 0.0476 | HDR-TH_20P-P2.54-F-LI-2X10P | PM254-2-10-Z-8.5 | PM254-2-10-Z-8.5 | gge457 |  | yes
16 | 1 | PM254-2-03-Z-8.5 | U21 | HDR-TH_6P-P2.54-V-F-R2-C3-S2.54 |  | PM254-2-03-Z-8.5 | HCTL(华灿天禄) | C2897404 | LCSC |  |  | Connectors | Female Headers | 6 | 38151 | 0.0195 | HDR-TH_6P-P2.54-F-LI-2X3P | PM254-2-03-Z-8.5 | PM254-2-03-Z-8.5 | gge458 |  | yes
17 | 1 | SGP41 | U22 | SGP41 |  |  |  |  |  |  | 22.5840 |  |  | 4 |  |  | 3D_SGP40_3.3V_PCB | SGP41 |  | gge459 |  | yes

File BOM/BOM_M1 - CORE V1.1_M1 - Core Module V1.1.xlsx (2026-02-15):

No. | Quantity | Comment | Designator | Footprint | Value | Manufacturer Part | Manufacturer | Supplier Part | Supplier | LCSC Stock | LCSC Price | Primary Category | Secondary Category | Pin Count | JLCPCB Stock | JLCPCB Price | 3D Model Title | Device | Name | Unique ID | Convert to PCB | Add into BOM | Symbol
1 | 4 | TS-1088-AR02016 | BOOT1,BSL1,RESET1,RESET2 | SW-SMD_L3.9-W3.0-P4.45 |  | TS-1088-AR02016 | XUNPU(讯普) | C720477 | LCSC |  |  | Switches | Tactile Switches | 2 | 685443 | 0.007 | SW-SMD_L3.9-W2.9-H2.0-LS4.8 | TS-1088-AR02016 | TS-1088-AR02016 | gge95,gge98,gge98_2,gge98_3 | yes | yes | TS-1088-AR02016
2 | 2 | 100nF | C1,C4 | C0805 | 100nF | CL21B104KCFNNNE | SAMSUNG(三星) | C28233 | LCSC |  |  | Capacitors | Multilayer Ceramic Capacitors MLCC - SMD/SMT | 2 | 2976090 | 0.0013 | C0805_L2.0-W1.3-H1.3 | CL21B104KCFNNNE | 100nF | gge212_6,gge212_7 | yes | yes | CL21B104KCFNNNE
3 | 2 | 100uF | C2,C3 | CAP-TH_BD6.3-P2.50-D1.0-FD | 100uF | GR107M050E12RR0VH4FP0 | CX(承兴) | C47891 | LCSC |  |  | Capacitors | Aluminum Electrolytic Capacitors - Leaded | 2 | 278065 | 0.0055 | CAP-TH_BD6.3-P2.50-D1.0-FD | GR107M050E12RR0VH4FP0 | 100uF | gge305_2,gge306_2 | yes | yes | 100uF 50V 6.3*12Black high frequency
4 | 2 | 10uF | C5,C9 | C0603 | 10uF | CL10A106KP8NNNC | SAMSUNG(三星) | C19702 | LCSC |  |  | Capacitors | Multilayer Ceramic Capacitors MLCC - SMD/SMT | 2 | 18470245 | 0.001 | C0603_L1.6-W0.8-H0.8 | CL10A106KP8NNNC | 10uF | gge431,gge432 | yes | yes | CL10A106KP8NNNC
5 | 2 | 10uF | C6,C7 | CAP-SMD_BD4.0-L4.3-W4.3-LS5.1-FD | 10uF | EEEFN1A100R | PANASONIC | C494786 | LCSC |  |  | Capacitors | Aluminum Electrolytic Capacitors - SMD | 2 | 1806 | 0.0333 | CAP-SMD_BD4.0-L4.3-W4.3-LS5.1-FD | VE-100M1ATR-0405 | 10uF | gge137,gge138 | yes | yes | VE-100M1A0405-TRO
6 | 1 | 100uF | C10 | CAP-TH_BD5.0-P2.00-D0.5-FD-1 | 100uF | KM1A101M0507 | ROQANG(容强) | C2874000 | LCSC |  |  | Capacitors | Aluminum Electrolytic Capacitors - Leaded | 2 | 0 |  | CAP-TH_BD5.0-P2.00-D0.5-FD-1 | KM1A101M0507 | 100uF | gge289_1 | yes | yes | KM1A101M0507
7 | 1 | 1uF | C11 | C0603 | 1uF | CL10A105KA8NNNC | SAMSUNG(三星) | C5673 | LCSC |  |  | Capacitors | Multilayer Ceramic Capacitors MLCC - SMD/SMT | 2 | 207479 | 0.0009 | C0603_L1.6-W0.8-H0.8 | CL10A105KA8NNNC | 1uF | gge38 | yes | yes | CL10A105KA8NNNC
8 | 2 | 6.8nF | C14,C22 | C0603 | 6.8nF | CC0603KRX7R9BB682 | YAGEO(国巨) | C107097 | LCSC |  |  | Capacitors | Multilayer Ceramic Capacitors MLCC - SMD/SMT | 2 | 143628 | 0.0005 | C0603_L1.6-W0.8-H0.8 | CC0603KRX7R9BB682 | 6.8nF | gge310_1,gge311_1 | yes | yes | CC0603KRX7R9BB682
9 | 2 | 10uF | C15,C28 | C0603 | 10uF | HGC0603R5106K160NTHJ | Chinocera(华瓷) | C7432767 | LCSC |  |  | Capacitors | Multilayer Ceramic Capacitors MLCC - SMD/SMT | 2 | 148057 | 0.0023 | C0603_L1.6-W0.8-H0.8 | HGC0603R5106K160NTHJ | 10uF | gge303_1,gge303_3 | yes | yes | HGC0603R5106K160NTHJ
10 | 7 | 100nF | C16,C17,C18,C19,C25,C29,C30 | C0603 | 100nF | CC0603KRX7R0BB104 | YAGEO(国巨) | C113803 | LCSC |  |  | Capacitors | Multilayer Ceramic Capacitors MLCC - SMD/SMT | 2 | 774232 | 0.0007 | C0603_L1.6-W0.8-H0.8 | CC0603KRX7R0BB104 | 100nF | gge298_1,gge299_1,gge299_2,gge299_3,gge300_1,gge301_1,gge302_1 | yes | yes | CC0603KRX7R0BB104
11 | 2 | 10nF | C20,C24 | C0603 | 10nF | CC0603KRX7R9BB103 | YAGEO(国巨) | C100042 | LCSC |  |  | Capacitors | Multilayer Ceramic Capacitors MLCC - SMD/SMT | 2 | 4674631 | 0.0004 | C0603_L1.6-W0.8-H0.8 | CC0603KRX7R9BB103 | 10nF | gge317_1,gge318_1 | yes | yes | CC0603KRX7R9BB103
12 | 1 | 22nF | C21 | C0603 | 22nF | CC0603KRX7R9BB223 | YAGEO(国巨) | C106222 | LCSC |  |  | Capacitors | Multilayer Ceramic Capacitors MLCC - SMD/SMT | 2 | 1003776 | 0.0005 | C0603_L1.6-W0.8-H0.8 | CC0603KRX7R9BB223 | 22nF | gge315_1 | yes | yes | CC0603KRX7R9BB223
13 | 1 | 4.7uF | C23 | C0603 | 4.7uF | V475K0603X7R6R3NET | VIIYONG(微容) | C2976057 | LCSC |  |  | Capacitors | Multilayer Ceramic Capacitors MLCC - SMD/SMT | 2 | 2105 | 0.0142 | C0603_L1.6-W0.8-H0.8 | V475K0603X7R6R3NET | 4.7uF | gge291_1 | yes | yes | V475K0603X7R6R3NET
14 | 2 | 20pF | C26,C27 | C0603 | 20pF | TCC0603COG200J500CT | CCTC(三环) | C376774 | LCSC |  |  | Capacitors | Multilayer Ceramic Capacitors MLCC - SMD/SMT | 2 | 97090 | 0.0005 | C0603_L1.6-W0.8-H0.8 | TCC0603COG200J500CT | 20pF | gge304_2,gge305_3 | yes | yes | TCC0603COG200J500CT
15 | 3 | 100nF | C31,C32,C33 | C0603 | 100nF | CC0603KRX7R9BB104 | YAGEO(国巨) | C14663 | LCSC |  |  | Capacitors | Multilayer Ceramic Capacitors MLCC - SMD/SMT | 2 | 40397032 | 0.0004 | C0603_L1.6-W0.8-H0.8 | CC0603KRX7R9BB104 | 100nF | gge300,gge300_2,gge300_3 | yes | yes | CC0603KRX7R9BB104
16 | 1 | WJ2EDGRC-5.08-2P | CN1 | CONN-TH_2P-P5.08_WJ2EDGRC-5.08-2P |  | WJ2EDGRC-5.08-2P | KANGNEX(康奈克斯电气) | C3697 | LCSC |  |  | Connectors | Pluggable System Terminal Block | 2 | 81125 | 0.0063 | CONN-TH_2P-L12.0-W12.2-H8.3-P5.08 | WJ2EDGRC-5.08-2P | WJ2EDGRC-5.08-2P | gge35_1 | yes | yes | WJ2EDGRC-5.08-2P
17 | 2 | WJ2EDGRC-5.08-3P | CN2,CN3 | CONN-TH_3P-P5.08_WJ2EDGRC-5.08-3P |  | WJ2EDGRC-5.08-3P | KANGNEX(康奈克斯电气) | C8377 | LCSC |  |  | Connectors | Pluggable System Terminal Block | 3 | 29593 | 0.0092 | CONN-TH_WJ5.08-WI-3P-4 | WJ2EDGRC-5.08-3P_C8377 | WJ2EDGRC-5.08-3P | UNIQUECN51_1,UNIQUECN51_2 | yes | yes | WJ2EDGRC-5.08-3P_C8377
18 | 1 | 1N5819 | D1 | SMA_L4.4-W2.6-LS5.0-RD |  | 1N5819 | KEXIN(科信) | C437199 | LCSC |  |  | Diodes | Schottky Diodes | 2 | 342660 | 0.003 | SMA_L4.4-W2.6-LS5.0-RD | 1N5819_C437199 | 1N5819 | gge261_2 | yes | yes | 1N5819_C437199
19 | 1 | SS34 | D2 | SMA_L4.3-W2.5-LS5.0-RD |  | SS34 | TWGMC(台湾迪嘉) | C727060 | LCSC |  |  | Diodes | Schottky Barrier Diodes (SBD) | 2 | 453109 | 0.004 | SMA_L4.3-W2.5-LS5.0-RD | SS34_C727060 | SS34 | gge44 | yes | yes | SS34_C727060
20 | 2 | nSMD005 | F1,F2 | F1206 |  | nSMD005 | 台湾陆海 | C70064 | LCSC |  |  | Circuit Protection | Resettable Fuses | 2 | 298185 | 0.0049 | F1206_L3.2-W1.7-H0.6 | nSMD005_C70064 | nSMD005 | gge180_1,gge183_1 | yes | yes | nSMD005
21 | 1 | HDR-M_2.54_1x7P | H1 | HDR-TH_7P-P2.54-V-M |  |  |  |  |  |  | 31.2059 | Connectors | Pin Headers | 7 |  |  | HDR-TH_7P-P2.54-M-LI-1X7P | HDR-M_2.54_1x7P |  | gge307_1 | yes | yes | PZ254V-11-07P
22 | 1 | HR911105A | J1 | RJ45-TH_HR911105A |  | HR911105A | HANRUN(汉仁) | C12074 | LCSC |  |  | Connectors | Ethernet Connectors/Modular Connectors (RJ45 RJ11) | 14 | 181102 | 0.216 | RJ45-TH_HR911105A | HR911105A_C12074 | HR911105A | gge127 | yes | yes | HR911105A_C12074
23 | 1 | YI160808U300-5R0T | L1 | L0603 |  | YI160808U300-5R0T | YJYCOIN(益嘉源) | C2971882 | LCSC |  |  | Filters | Ferrite Beads | 2 | 2780 | 0.0021 | L0603_L1.6-W0.8-H0.5_BEAD | YI160808U300-5R0T | YI160808U300-5R0T | gge316_1 | yes | yes | YI160808U300-5R0T
24 | 1 | HCB2012KF-121T50 | L2 | L0805 |  | HCB2012KF-121T50 | TAI-TECH(台庆) | C304323 | LCSC |  |  | Filters | Ferrite Beads | 2 | 2205 | 0.0018 | R0805_L2.0-W1.3-H0.6 | HCB2012KF-121T50 | HCB2012KF-121T50 | gge242_1 | yes | yes | HCB2012KF-121T50
25 | 1 | 68uH | L3 | IND-SMD_L12.3-W12.3_SMDRI127 | 68uH | SMDRI127-680MT | SXN(顺翔诺) | C9907 | LCSC |  |  | Inductors, Coils, Chokes | Power Inductors | 2 | 60926 | 0.0326 | SMD-PIND_L12.5-W12.5-H8.0 | SMDRI127-680MT | 68uH | gge45 | yes | yes | SMDRI127-680MT
26 | 3 | MHT192CRCT | LED1,LED2,POWER1 | LED0603-RD |  | MHT192CRCT | MEIHUA(美华) | C389517 | LCSC |  |  | Optoelectronics | LED Indication - Discrete | 2 | 102980 | 0.0033 | LED0603-RD | MHT192CRCT | MHT192CRCT | gge48,gge48_1,gge48_2 | yes | yes | MHT192CRCT
27 | 1 | WPM2015-3/TR | Q1 | SOT-23-3_L2.9-W1.3-P1.90-LS2.4-BR |  | WPM2015-3/TR | KUU | C6562215 | LCSC |  |  | Transistors/Thyristors | MOSFETs | 3 | 13877 | 0.0064 | SOT-23-3P_L2.9-W1.3-H1.0-LS2.4-P0.95 | WPM2015-3/TR_C6562215 | WPM2015-3/TR | gge262_2 | yes | yes | WPM2015-3/TR_C6562215
28 | 3 | 10Ω | R1,R3,R35 | R0603 | 10Ω | FRQ0603F10R0TS | FOJAN(富捷) | C7468682 | LCSC |  |  | Resistors | Chip Resistor - Surface Mount | 2 | 4299 | 0.0003 | R0603 | FRQ0603F10R0TS | 10Ω | gge417,gge418,gge418_1 | yes | yes | FRQ0603F10R0TS
29 | 7 | 10kΩ | R2,R5,R10,R12,R13,R14,R32 | R0603 | 10kΩ | FRC0603F1002TS | FOJAN(富捷) | C2906982 | LCSC |  |  | Resistors | Chip Resistor - Surface Mount | 2 | 15261777 | 0.0002 | R0603 | FRC0603F1002TS | 10kΩ | gge419,gge422,gge423,gge424,gge424_1,gge425,gge426 | yes | yes | FRC0603F1002TS
30 | 3 | 1kΩ | R4,R33,R34 | R0603 | 1kΩ | RS-03K1001FT | FH(风华) | C115325 | LCSC |  |  | Resistors | Chip Resistor - Surface Mount | 2 | 4257181 | 0.0003 | R0603 | RS-03K1001FT | 1kΩ | gge46,gge46_1,gge46_3 | yes | yes | RS-03K1001FT
31 | 4 | 2.2kΩ | R6,R7,R8,R9 | R0603 | 2.2kΩ | FRC0603F2201TS | FOJAN(富捷) | C2907005 | LCSC |  |  | Resistors | Chip Resistor - Surface Mount | 2 | 3498670 | 0.0002 | R0603 | FRC0603F2201TS | 2.2kΩ | gge433,gge434,gge435,gge436 | yes | yes | FRC0603F2201TS
32 | 3 | 4.7kΩ | R11,R29,R31 | R0603 | 4.7kΩ | 0603WAF4701T5E | UNI-ROYAL(厚声) | C23162 | LCSC |  |  | Resistors | Chip Resistor - Surface Mount | 2 | 30460665 | 0.0002 | R0603 | 0603WAF4701T5E | 4.7kΩ | gge319,gge320,gge320_1 | yes | yes | 0603WAF4701T5E
33 | 2 | 49.9Ω | R16,R17 | R0603 | 49.9Ω | FRC0603F49R9TS | FOJAN(富捷) | C2930110 | LCSC |  |  | Resistors | Chip Resistor - Surface Mount | 2 | 603917 | 0.0002 | R0603 | FRC0603F49R9TS | 49.9Ω | gge313_1,gge314_1 | yes | yes | FRC0603F49R9TS
34 | 2 | 82Ω | R18,R19 | R0603 | 82Ω | 0603WAF820JT5E | UNI-ROYAL(厚声) | C23255 | LCSC |  |  | Resistors | Chip Resistor - Surface Mount | 2 | 252378 | 0.0003 | R0603 | 0603WAF820JT5E | 82Ω | gge308_1,gge309_1 | yes | yes | 0603WAF820JT5E
35 | 2 | 510Ω | R20,R21 | R0603 | 510Ω | FRC0603J511 TS | FOJAN(富捷) | C2907179 | LCSC |  |  | Resistors | Chip Resistor - Surface Mount | 2 | 740067 | 0.0002 | R0603 | FRC0603J511 TS | 510Ω | gge306_3,gge307_2 | yes | yes | FRC0603J511 TS
36 | 1 | 12.4kΩ | R22 | R0603 | 12.4kΩ | FRC0603F1242TS | FOJAN(富捷) | C2930060 | LCSC |  |  | Resistors | Chip Resistor - Surface Mount | 2 | 89902 | 0.0002 | R0603 | FRC0603F1242TS | 12.4kΩ | gge290_1 | yes | yes | FRC0603F1242TS
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

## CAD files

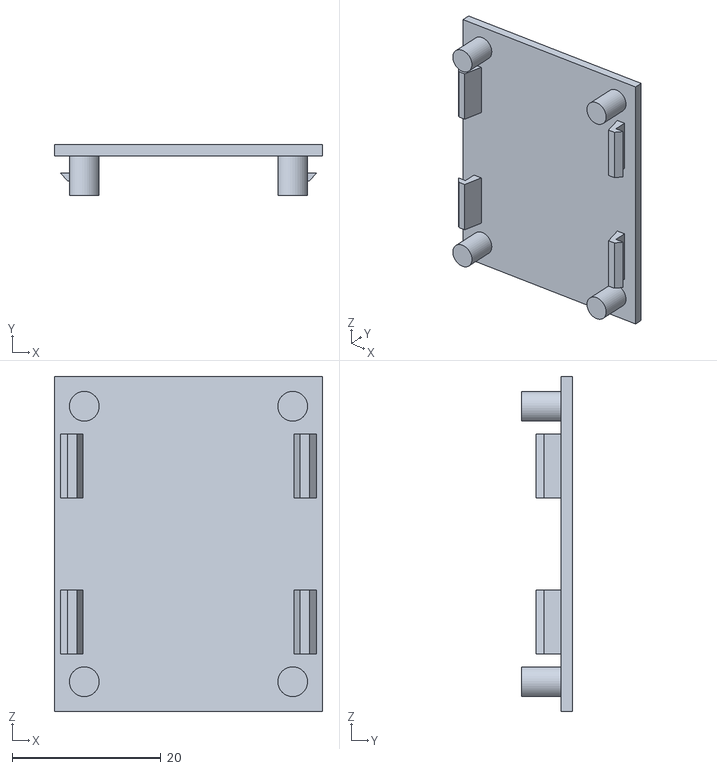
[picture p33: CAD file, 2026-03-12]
3D Print files/M3 - CONTACT - Top clean no hole.STL
36.0 x 6.80 x 45.0

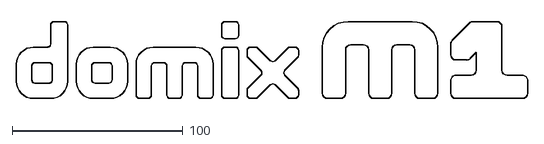
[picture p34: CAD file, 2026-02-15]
Images/Board/M1/M1.dxf
299.0 x 45.0

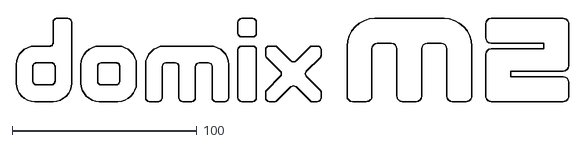
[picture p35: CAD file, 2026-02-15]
Images/Board/M2/M2.dxf
299.0 x 45.0

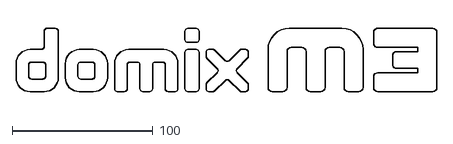
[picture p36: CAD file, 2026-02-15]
Images/Board/M3/M3.dxf
299.0 x 45.0

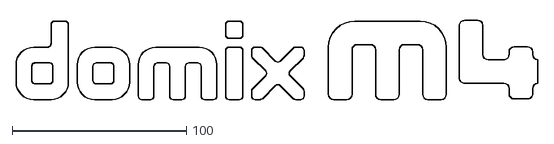
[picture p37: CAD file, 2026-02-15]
Images/Board/M4/M4.dxf
299.0 x 45.3

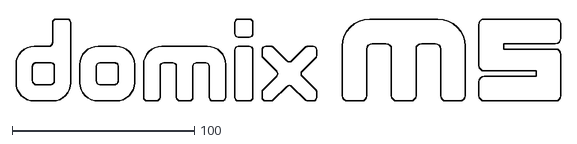
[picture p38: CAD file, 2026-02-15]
Images/Board/M5/M5.dxf
299.0 x 45.0

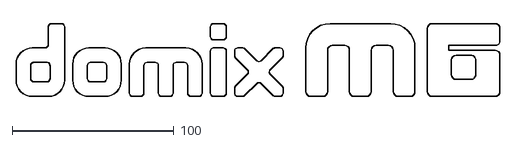
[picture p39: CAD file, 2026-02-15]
Images/Board/M6/M6.dxf
299.0 x 45.0

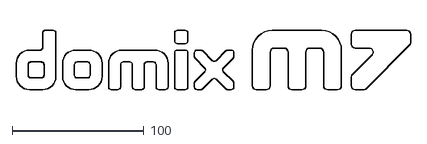
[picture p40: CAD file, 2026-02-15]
Images/Board/M7/M7.dxf
299.0 x 45.0

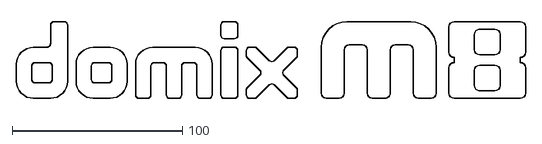
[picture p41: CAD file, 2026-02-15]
Images/Board/M8/M8.dxf
299.0 x 45.0

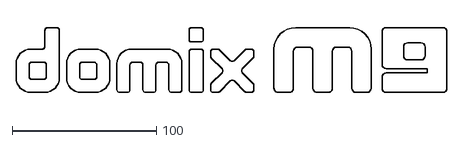
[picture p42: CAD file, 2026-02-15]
Images/Board/M9/M9.dxf
299.0 x 45.0

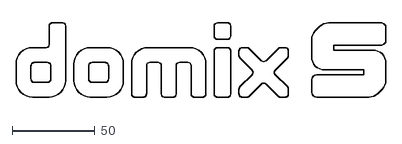
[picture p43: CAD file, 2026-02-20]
Images/Board/S/S.dxf
224.0 x 45.0

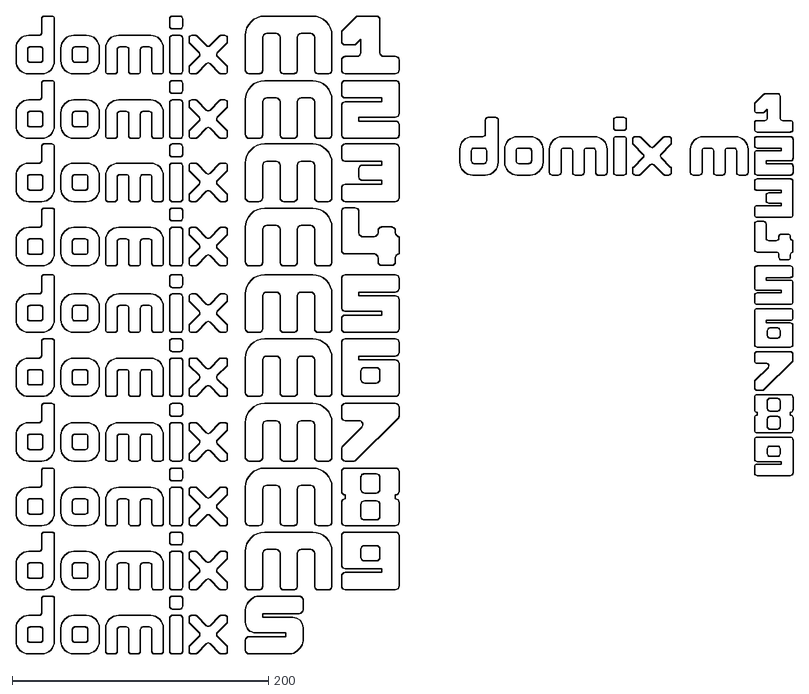
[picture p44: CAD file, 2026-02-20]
Logo/domixNumeritot.dxf
606.3 x 497.6

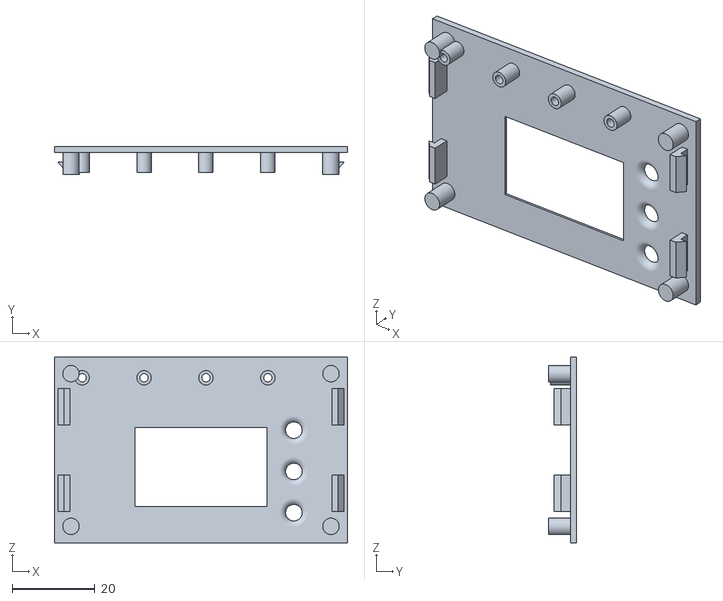
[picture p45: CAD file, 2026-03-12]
3D Print files/M1 - CORE - Top clean.STL
71.0 x 6.80 x 45.0

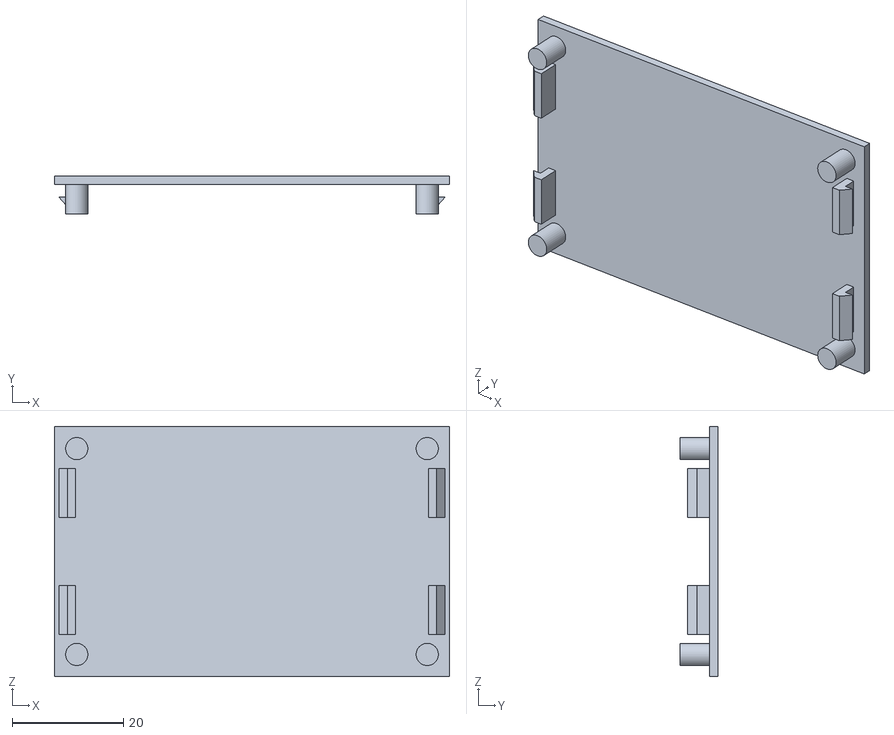
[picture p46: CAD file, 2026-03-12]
3D Print files/M5 - 12 RELAY - Top clean.STL
71.0 x 6.80 x 45.0

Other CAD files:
3D Print files/M6 - ENERGY - Top clean.STL
3D Print files/S - Wall Cover clean no hole.STL
3D Print files/M7 - OUTPUT - Top clean.STL
3D Print files/M4 - 6 RELAY - Top clean no hole.STL
3D Print files/DOMIX.3mf
3D Print files/M1 - CORE - Bottom.STL
3D Print files/M1 - CORE - Box.STL
3D Print files/M1 - CORE - Indication.3MF
3D Print files/M1 - CORE - Indication2.3MF
3D Print files/M1 - CORE - Top.3MF
3D Print files/M2 - IO - Bottom.STL
3D Print files/M2 - IO - Box.STL
3D Print files/M2 - IO - Indication.3MF
3D Print files/M2 - IO - Indication2.3MF
3D Print files/M2 - IO - Top clean.STL
3D Print files/M2 - IO - Top.3MF
3D Print files/M3 - CONTACT - Bottom.STL
3D Print files/M3 - CONTACT - Box.STL
3D Print files/M3 - CONTACT - Indication.3MF
3D Print files/M3 - CONTACT - Indication2.3MF
3D Print files/M3 - CONTACT - Top Clean.3MF
3D Print files/M3 - CONTACT - Top Screen.3MF
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

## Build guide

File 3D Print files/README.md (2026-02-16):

# Box for DIN modules

The boxes for the various modules were designed based on the standard dimensions of commercial modules. The height, width, and depth were adapted to those commonly available on the market.

The surface thickness of the modules is 1.5 mm, making them sturdy enough for initial handling and light enough to print quickly. I personally printed them with e-Sun PLA+ filament; I haven't tried other brands or materials.

The lower board is mated to the module by interposing the PCB with the back of the module and the front. Inside the front, I used threaded brass inserts, hot-fitted into the structure, and then secured everything with M3x7 mm screws from side to side. This solution makes the whole thing solid and convenient for attaching to the electrical panel.
The module is locked to the DIN rail using a clip, identical for all modules, which can be locked using a flat screwdriver.

<div align="center">
    
</div>

The front part fits into the front part and provides the basic information for user interaction with the system in front of the electrical panel. To print it, I used an AMS with at least two colors; I didn't want to overly burden the graphics. Unfortunately, given the small size of the components, it's necessary to adjust the printing parameters to optimize the final result. The part must be printed with the graphics facing the print bed.
It's also possible to print fronts without any graphics or holes. The system will then be controlled only via a web interface or MQTT. The "bare" front files are included in the documentation.

The connection identification plates, however, should be printed with the numbers or letters facing upward. In the graphic file, they are 0.4 mm thick. Ideally, these should also be printed in at least two colors.

To print all the modules approximately 500g of filament were used.

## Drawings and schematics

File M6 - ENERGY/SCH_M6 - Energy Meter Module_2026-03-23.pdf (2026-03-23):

# PINOUT

# Domotic Module for smart home & co

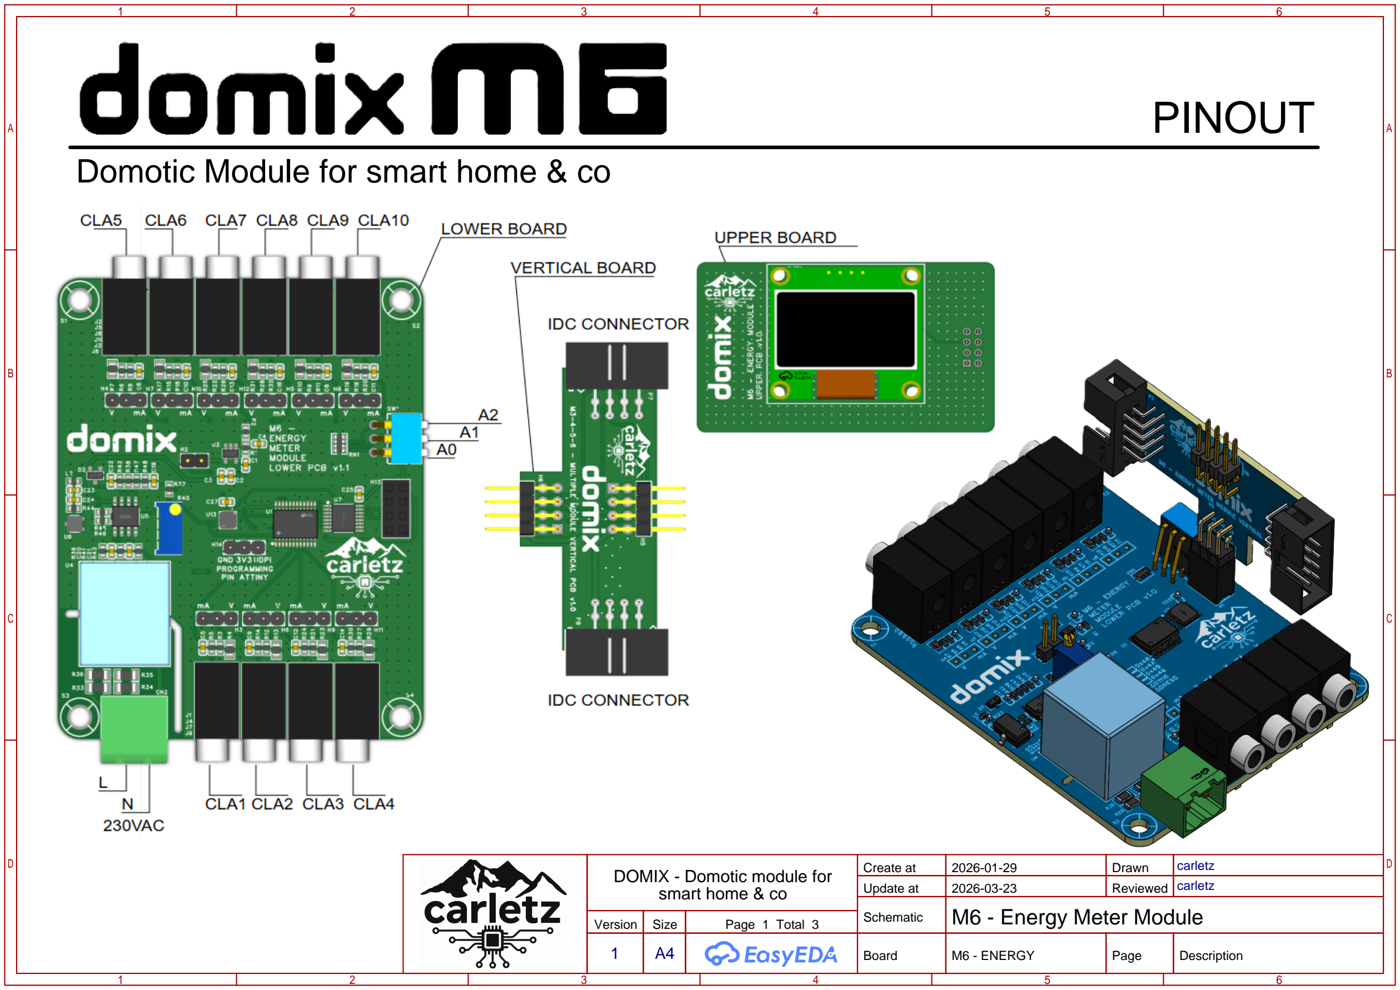
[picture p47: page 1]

smart home & co | Create at | 2026-01-29 | Drawn | carletz DOMIX - Domotic module for
| Update at | 2026-03-23 | Reviewed | carletz
| Schematic | M6 - Energy Meter Module
Version | Size | Page 1 Total 3
1 | A4 | | Board | M6 - ENERGY | Page | Description

# IO5 10 IO6 11 IO7 12 INT# 13 SCL 14 SDA 15 VDD 16

I2C

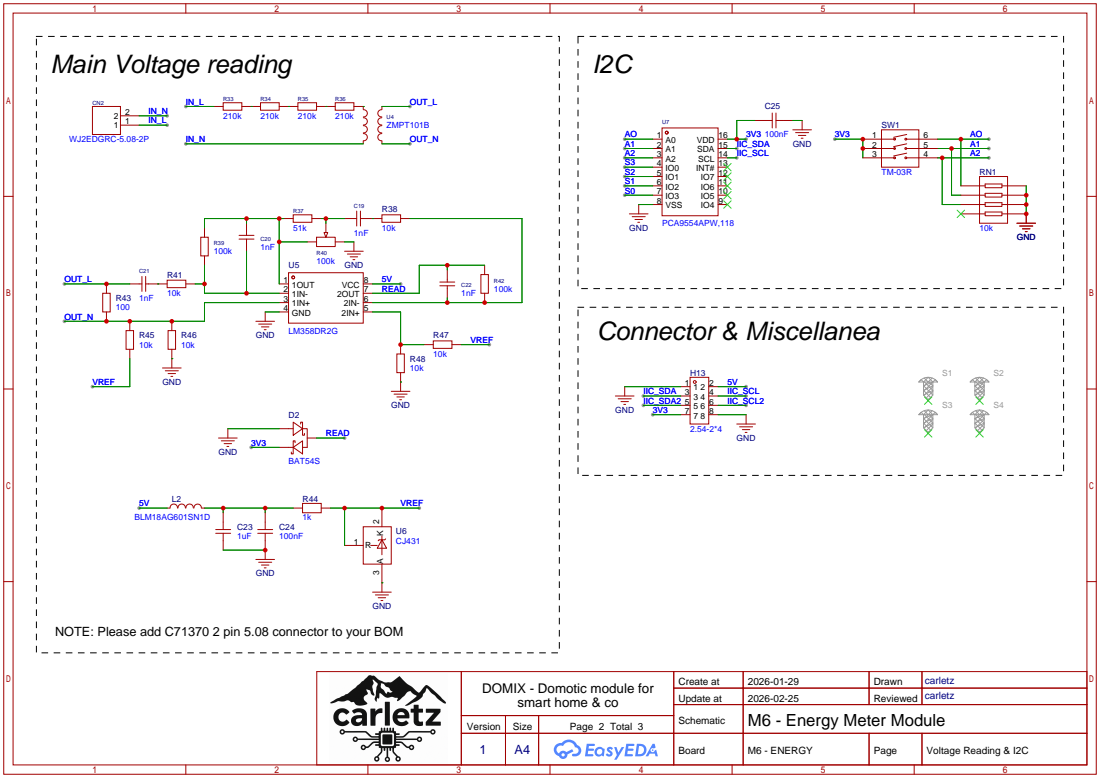
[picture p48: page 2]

NOTE: Please add C71370 2 pin 5.08 connector to your BOM

smart home & co | Create at | 2026-01-29 | Drawn | carletz DOMIX - Domotic module for

Update at | 2026-02-25 | Reviewed | carletz

Schematic | M6 - Energy Meter Module

Version | Size | Page 2 Total 3

Board | M6 - ENERGY | Page | Voltage Reading & I2C

# Clamp Meter

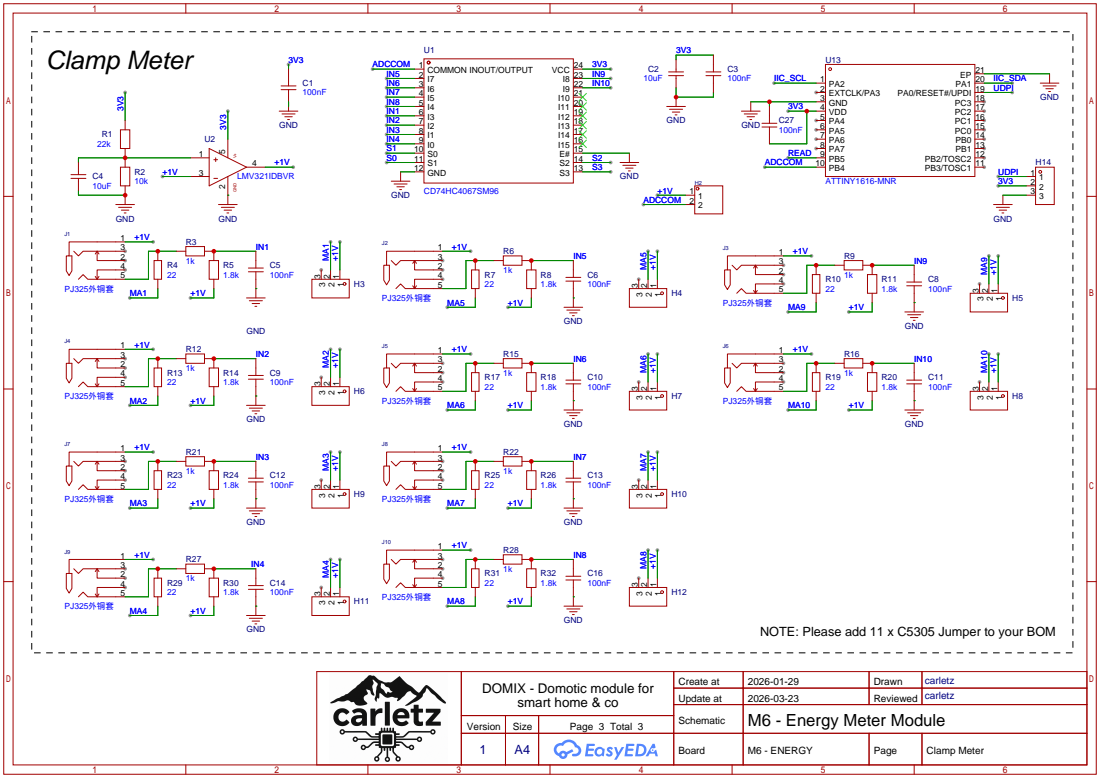
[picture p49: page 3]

NOTE: Please add 11 x C5305 Jumper to your BOM

smart home & co | Create at | 2026-01-29 | Drawn | carletz DOMIX - Domotic module for

Update at | 2026-03-23 | Reviewed | carletz

Schematic | M6 - Energy Meter Module

Version | Size | Page 3 Total 3

Board | M6 - ENERGY | Page | Clamp Meter

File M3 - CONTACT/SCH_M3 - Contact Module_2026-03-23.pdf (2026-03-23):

# PINOUT

# Domotic Module for smart home & co

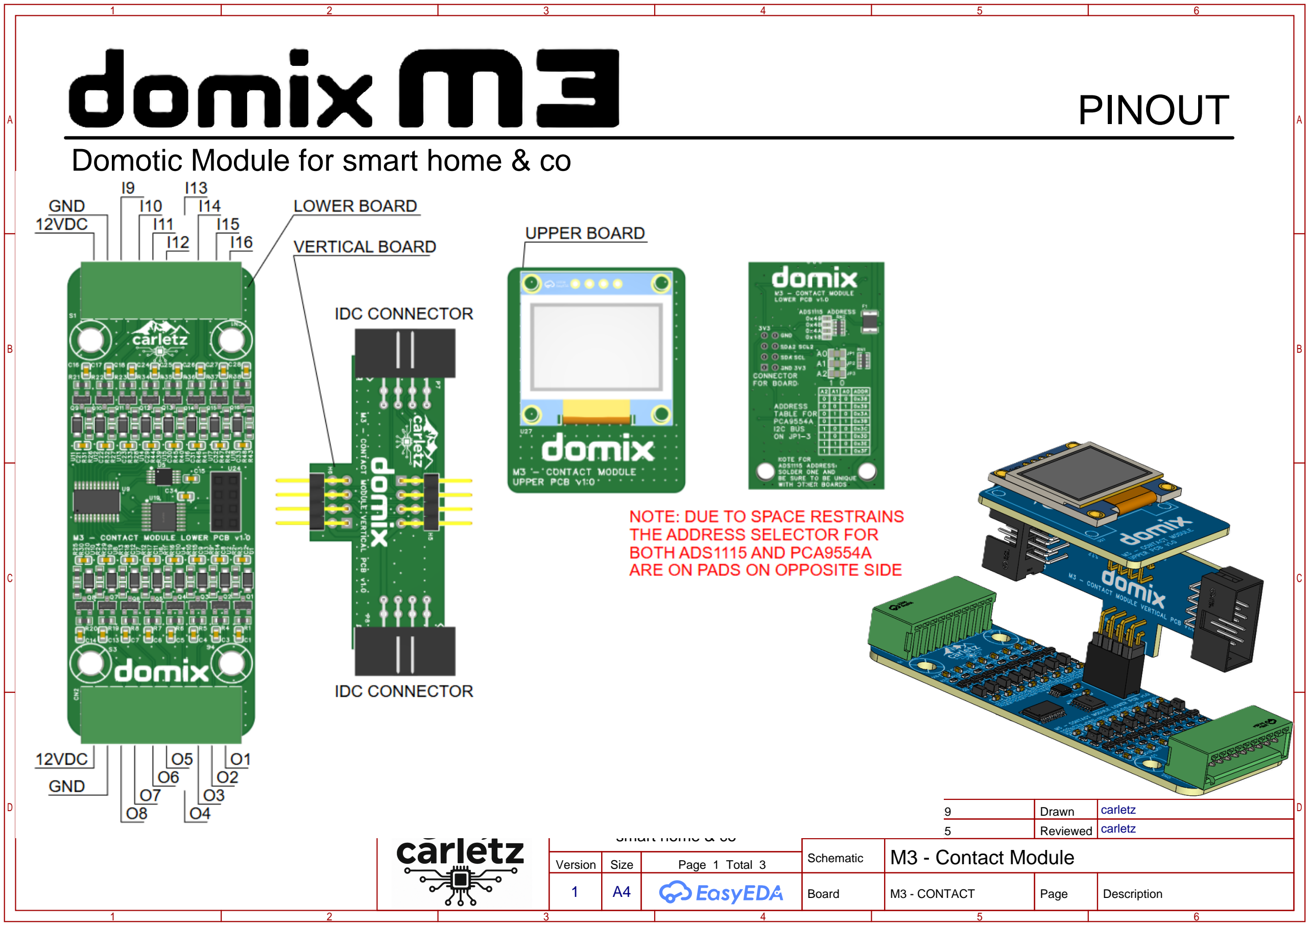
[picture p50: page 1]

smart home & co | Create at | 2026-01-29 | Drawn | carletz DOMIX - Domotic module for
| Update at | 2026-02-25 | Reviewed | carletz
| Schematic | M3 - Contact Module
Version | Size | Page 1 Total 3
1 | A4 | | Board | M3 - CONTACT | Page | Description

# I15 16 I14 17 I13 18 I12 19 I11 20 I10 21 I9 22 I8 23 I7 2

# IO5 10 IO6 11 IO7 12 INT# 13 SCL 14 SDA 15 VDD 16

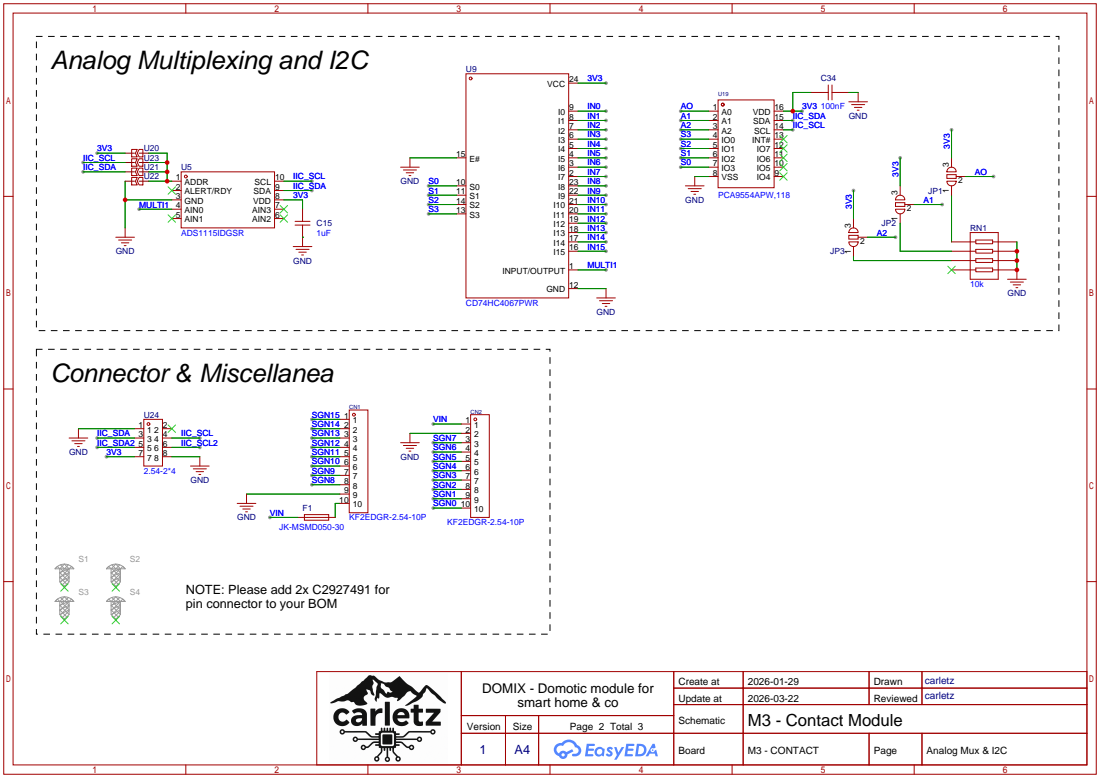
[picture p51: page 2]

NOTE: Please add 2x C2927491 for
pin connector to your BOM

smart home & co | Create at | 2026-01-29 | Drawn | carletz DOMIX - Domotic module for

Update at | 2026-03-22 | Reviewed | carletz

Schematic | M3 - Contact Module

Version | Size | Page 2 Total 3

Board | M3 - CONTACT | Page | Analog Mux & I2C

# Contacts

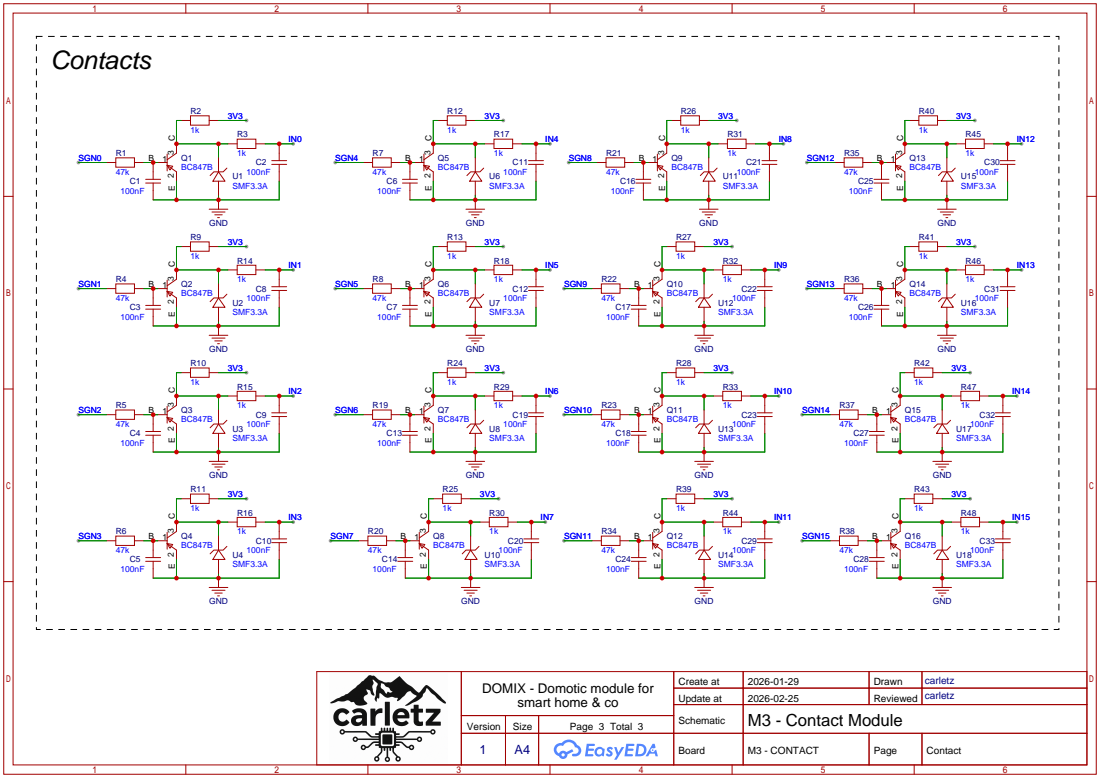
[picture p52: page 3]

smart home & co | Create at | 2026-01-29 | Drawn | carletz DOMIX - Domotic module for

Update at | 2026-02-25 | Reviewed | carletz

Schematic | M3 - Contact Module

Version | Size | Page 3 Total 3

Board | M3 - CONTACT | Page | Contact

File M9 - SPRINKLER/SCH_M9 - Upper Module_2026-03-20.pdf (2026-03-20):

Connector | Button and Led

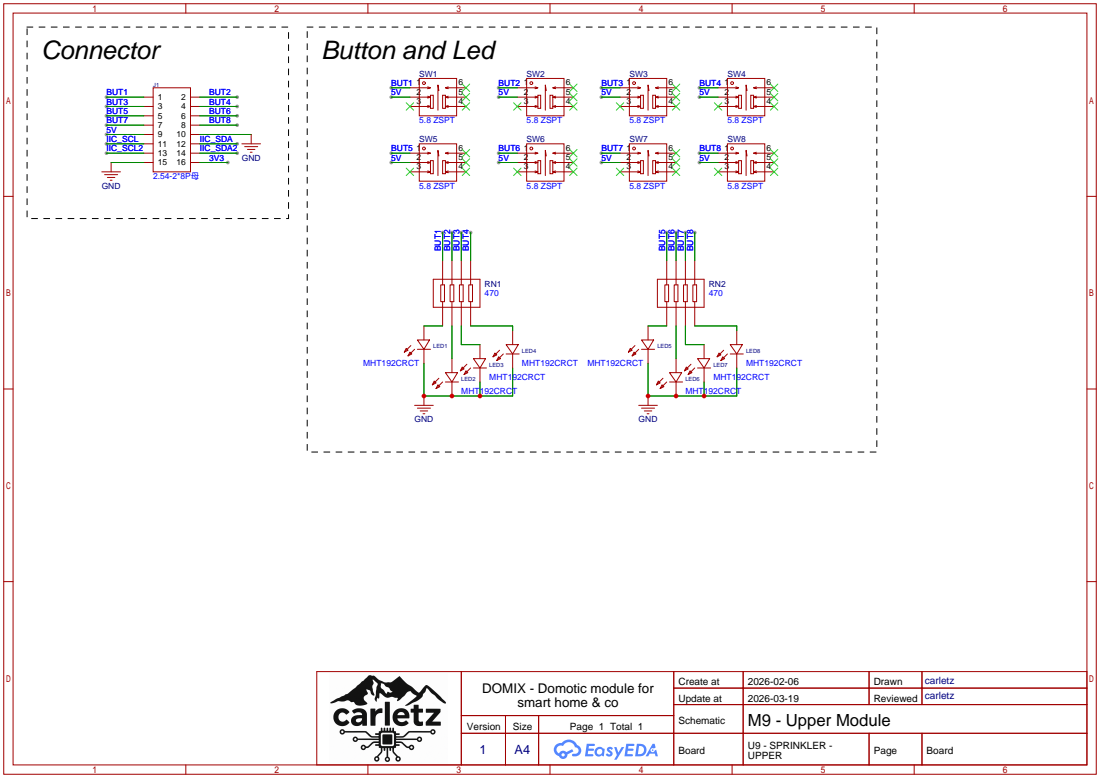
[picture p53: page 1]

smart home & co | Create at | 2026-02-06 | Drawn | carletz DOMIX - Domotic module for

Update at | 2026-03-19 | Reviewed | carletz

Schematic | M9 - Upper Module
1 | A4 | | Board | U9 - SPRINKLER -UPPER | Page | Board

Version | Size | Page 1 Total 1

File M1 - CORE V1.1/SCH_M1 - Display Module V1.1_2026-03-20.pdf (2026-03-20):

# Button input

# Screen

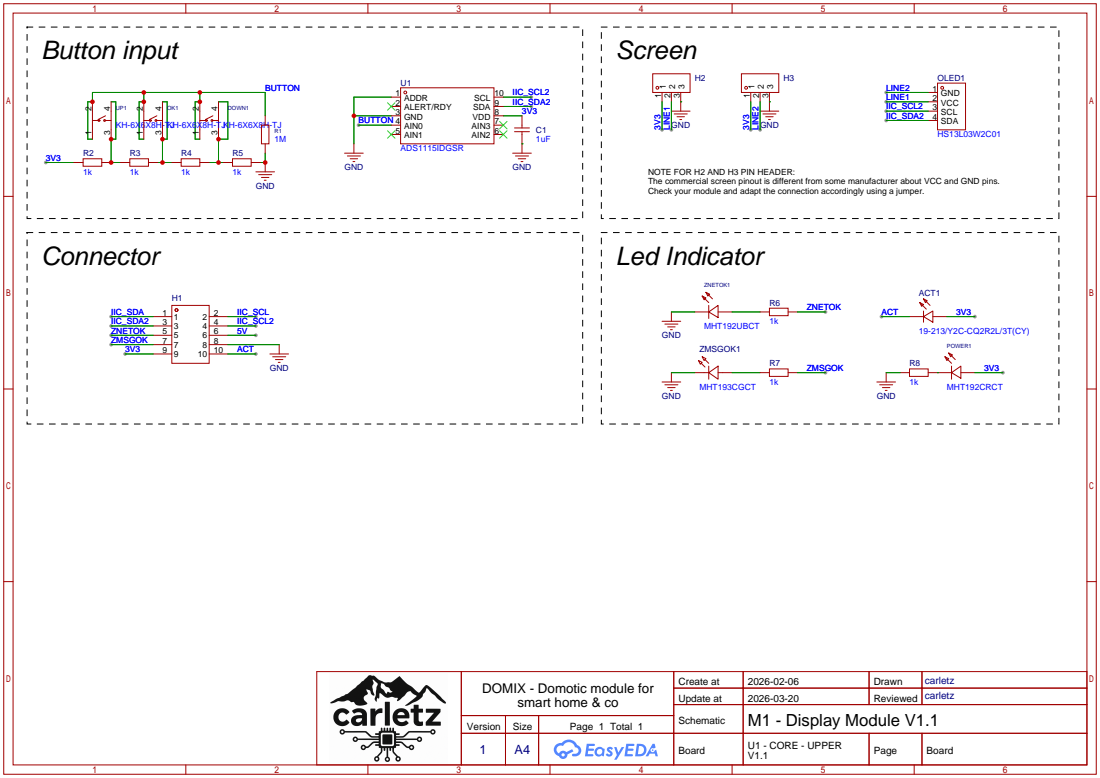
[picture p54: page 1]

NOTE FOR H2 AND H3 PIN HEADER:
The commercial screen pinout is different from some manufacturer about VCC and GND pins.
Check your module and adapt the connection accordingly using a jumper.

smart home & co | Create at | 2026-02-06 | Drawn | carletz DOMIX - Domotic module for

Update at | 2026-03-20 | Reviewed | carletz

Schematic | M1 - Display Module V1.1
1 | A4 | | Board | U1 - CORE - UPPER V1.1 | Page | Board

Version | Size | Page 1 Total 1

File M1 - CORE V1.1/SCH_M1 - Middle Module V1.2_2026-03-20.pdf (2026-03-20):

# Connector

# I2C Switch

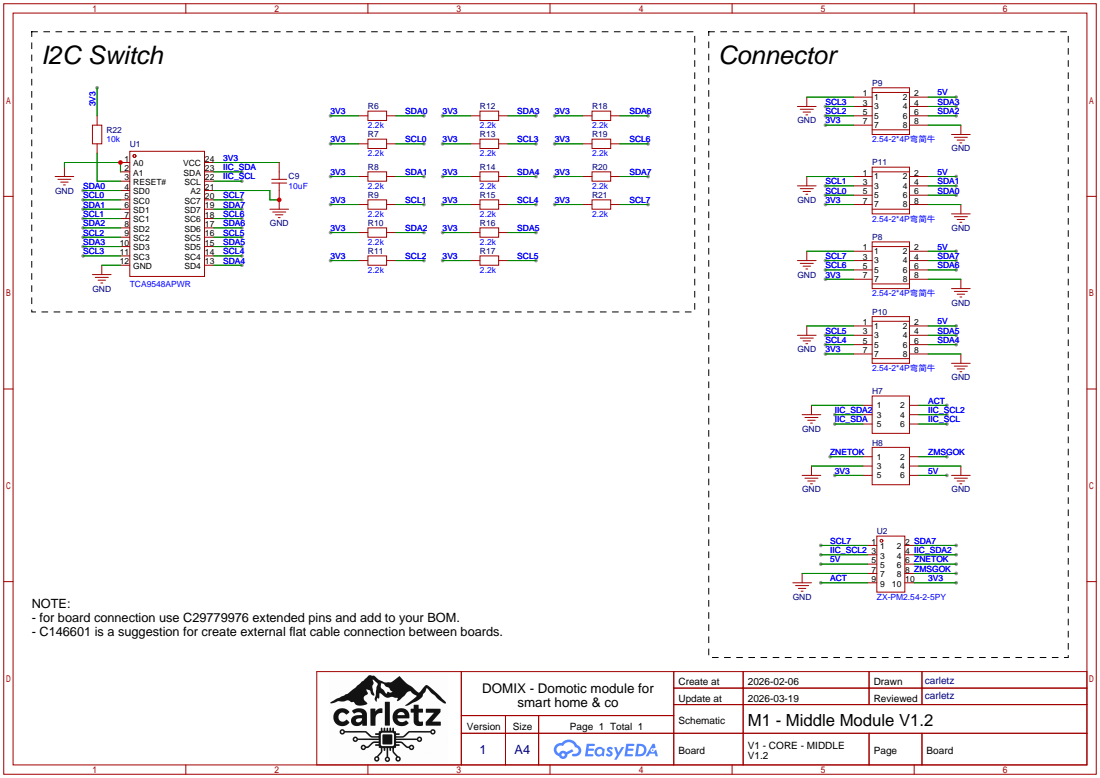
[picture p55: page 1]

NOTE:
- for board connection use C29779976 extended pins and add to your BOM.
- C146601 is a suggestion for create external flat cable connection between boards.

smart home & co | Create at | 2026-02-06 | Drawn | carletz DOMIX - Domotic module for

Update at | 2026-03-19 | Reviewed | carletz

Schematic | M1 - Middle Module V1.2
1 | A4 | | Board | V1 - CORE - MIDDLE V1.2 | Page | Board

Version | Size | Page 1 Total 1

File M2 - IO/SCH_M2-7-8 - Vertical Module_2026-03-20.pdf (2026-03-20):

# Connector

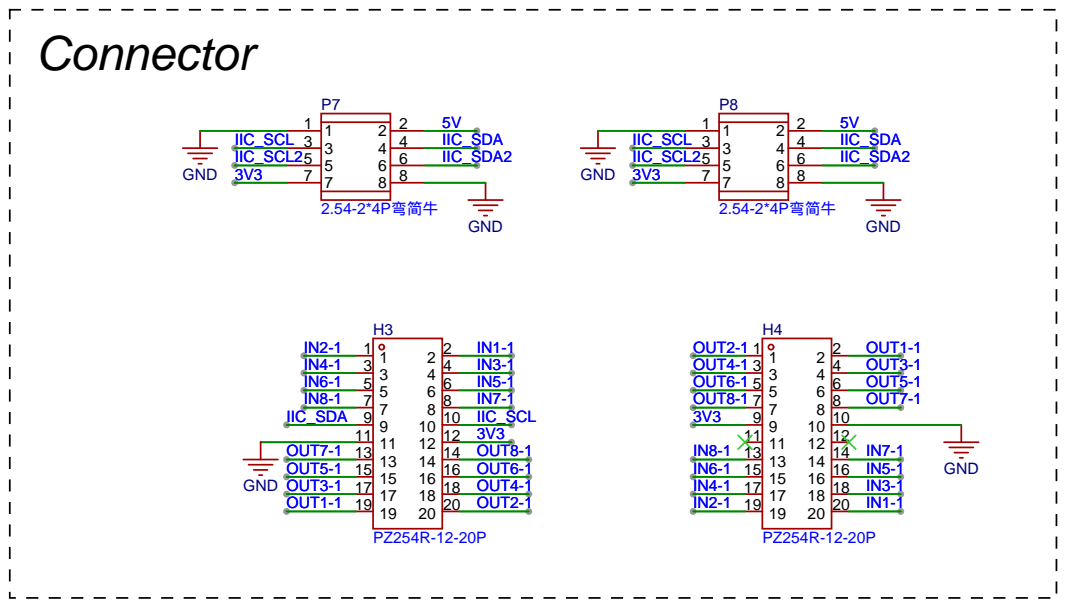
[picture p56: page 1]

smart home & co | Create at | 2026-01-29 | Drawn | carletz DOMIX - Domotic module for

Update at | 2026-03-19 | Reviewed | carletz

Schematic | M2-7-8 - Vertical Module
1 | A4 | | Board | V2-7-8 - MULTI -VERTICAL | Page | Connector

Version | Size | Page 1 Total 1

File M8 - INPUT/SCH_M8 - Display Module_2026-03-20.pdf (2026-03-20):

# Led Indicator

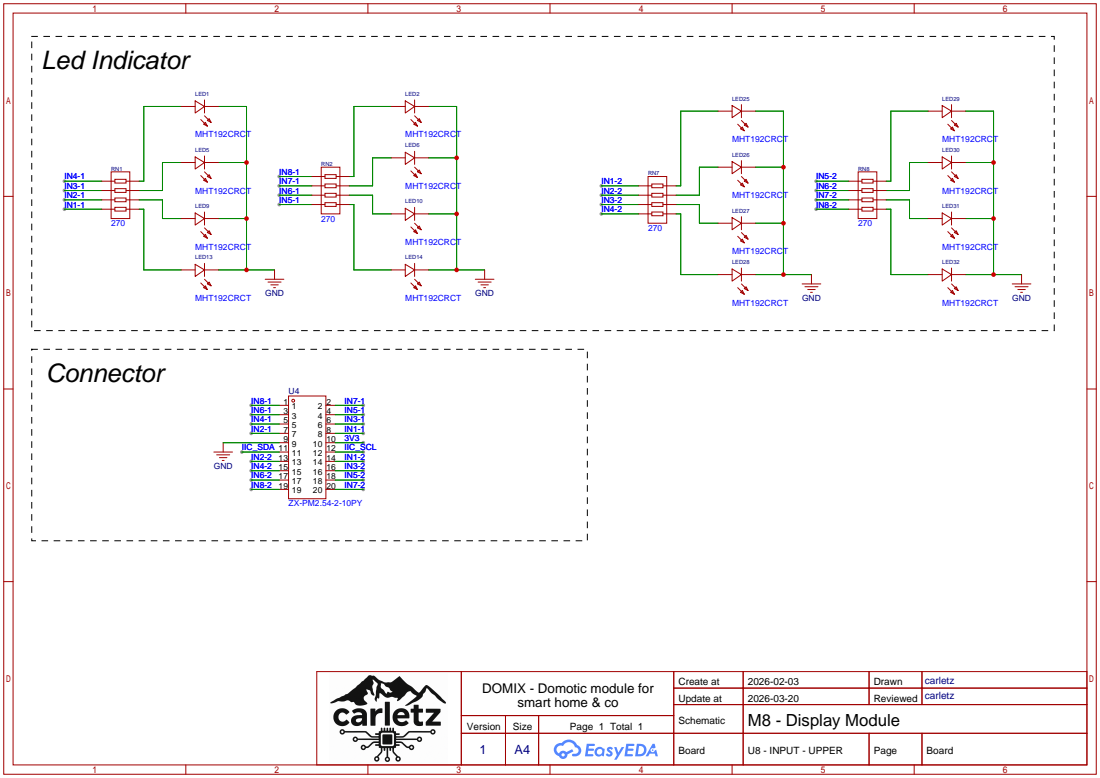
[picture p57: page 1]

smart home & co | Create at | 2026-02-03 | Drawn | carletz DOMIX - Domotic module for

Update at | 2026-03-20 | Reviewed | carletz

Schematic | M8 - Display Module
1 | A4 | | Board | U8 - INPUT - UPPER | Page | Board

Version | Size | Page 1 Total 1

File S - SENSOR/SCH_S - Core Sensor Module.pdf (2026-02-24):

# PINOUT

# Domotic Module for smart home & co

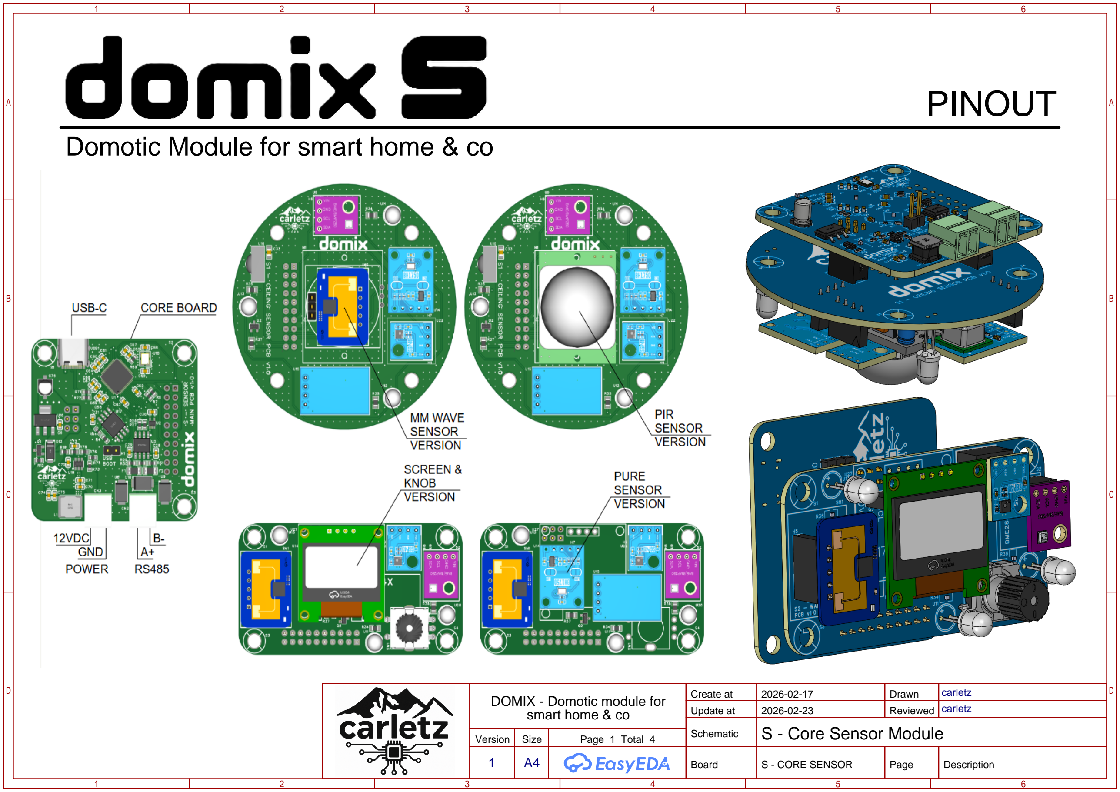
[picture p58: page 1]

smart home & co | Create at | 2026-02-17 | Drawn | carletz DOMIX - Domotic module for
| Update at | 2026-02-23 | Reviewed | carletz
| Schematic | S - Core Sensor Module
Version | Size | Page 1 Total 4
1 | A4 | | Board | S - CORE SENSOR | Page | Description

# USB & Power Supply


smart home & co | Create at | 2026-02-17 | Drawn | carletz DOMIX - Domotic module for

Update at | 2026-02-24 | Reviewed | carletz

Schematic | S - Core Sensor Module

Version | Size | Page 2 Total 4

Board | S - CORE SENSOR | Page | USB & Power

# Microcontroller


Make sure C18 is close to pin 44 of RP2040

Make sure C19 is close to pin 45 of RP2041

smart home & co | Create at | 2026-02-17 | Drawn | carletz DOMIX - Domotic module for

Update at | 2026-02-23 | Reviewed | carletz

Schematic | S - Core Sensor Module

Version | Size | Page 3 Total 4

Board | S - CORE SENSOR | Page | Microcontroller

RS485


smart home & co | Create at | 2026-02-17 | Drawn | carletz DOMIX - Domotic module for

Update at | 2026-02-23 | Reviewed | carletz

Schematic | S - Core Sensor Module

Version | Size | Page 4 Total 4

Board | S - CORE SENSOR | Page | RS485

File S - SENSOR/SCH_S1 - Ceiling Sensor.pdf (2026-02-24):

# GPIO3⁵V

# Ceiling Sensor


NOTE:
IR receiver is not supported on ESPHome
and RP2040.

smart home & co | Create at | 2026-02-18 | Drawn | carletz DOMIX - Domotic module for

Update at | 2026-02-24 | Reviewed | carletz

Schematic
1 | A4 | | Board | S1 - CEILING SENSOR | Page | Sensor

Size | Page 1 Total 1 | S1 - Ceiling Sensor Version

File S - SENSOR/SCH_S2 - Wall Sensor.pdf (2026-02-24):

# Wall Sensor

LD2410C | BME280


smart home & co | Create at | 2026-02-19 | Drawn | carletz DOMIX - Domotic module for

Update at | 2026-02-24 | Reviewed | carletz

Schematic
1 | A4 | | Board | S2 - WALL SENSOR | Page | Sensor

Size | Page 1 Total 1 | S2 - Wall Sensor Version

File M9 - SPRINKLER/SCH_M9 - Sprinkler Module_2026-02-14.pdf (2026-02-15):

# PINOUT

# Domotic Module for smart home & co


smart home & co | Create at | 2026-02-06 | Drawn | carletz DOMIX - Domotic module for
| Update at | 2026-02-14 | Reviewed | carletz
| Schematic | M9 - Sprinkler Module
Version | Size | Page 1 Total 3
1 | A4 | | Board | M9 - SPRINKLER | Page | Description

# Connector & Miscellanea

# External 24VAC power


NOTE: Please add 2x C41430724 for pin connector and
1x C22365805 for valve connector to your BOM

IO5 10 IO6 11 IO7 12 INT# 13 SCL 14 SDA 15 VDD 16

smart home & co | Create at | 2026-02-06 | Drawn | carletz DOMIX - Domotic module for

Update at | 2026-02-09 | Reviewed | carletz

Schematic | M9 - Sprinkler Module

Version | Size | Page 2 Total 3

Board | M9 - SPRINKLER | Page | Sprinkler

# External input


GND
P5 10 P6 11 P7 12 #INT 13 SCL 14 SDA 15 VDD 16

smart home & co | Create at | 2026-02-06 | Drawn | carletz DOMIX - Domotic module for

Update at | 2026-02-09 | Reviewed | carletz

Schematic | M9 - Sprinkler Module

Version | Size | Page 3 Total 3

Board | M9 - SPRINKLER | Page | Input

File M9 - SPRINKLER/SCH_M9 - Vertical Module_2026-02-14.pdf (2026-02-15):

# Connector


smart home & co | Create at | 2026-02-07 | Drawn | carletz DOMIX - Domotic module for

Update at | 2026-02-09 | Reviewed | carletz

Schematic | M9 - Vertical Module
1 | A4 | | Board | V9 - SPRINKLER -VERTICAL | Page | Connector

Version | Size | Page 1 Total 1

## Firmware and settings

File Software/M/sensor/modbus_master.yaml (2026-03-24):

# ──────────────────────────────────────────────────────────────
#  Read data from DOMIX S sensor module
#  Add more module at your use adding blocks and changing address
# ──────────────────────────────────────────────────────────────
#
#  SUBSTITUTIONS REQUIRED in your main config:
#
#  s_controller_id:  unique id for this modbus controller
#  s_modbus_addr:    modbus slave address (e.g. 0x01)
#  s_name:           snake_case name (e.g. salon)
#  s_name_upper:     display name     (e.g. Salon)
#  sorting_weight:   web_server sort group weight
#  mqtt_name:        MQTT base topic
# ──────────────────────────────────────────────────────────────

modbus_controller:
  - id: ${s_controller_id}
    modbus_id: modbus_bus
    address: ${s_modbus_addr}
    # 7s — intentionally offset from slave 5s cycle to avoid
    # reading while slave is writing registers (race condition).
    update_interval: 7s

web_server:
  sorting_groups:
    - id: ${s_name}
      name: "${s_name_upper} sensor"
      sorting_weight: ${sorting_weight}

mqtt:
  on_message:
    # ══════════════════════════════════════════════════════════════
    #  IR commands over MQTT → Modbus holding register 0
    # ══════════════════════════════════════════════════════════════
    - topic: ${mqtt_name}/${s_name_upper} sensor/IR/command
      then:
        - lambda: |-
            std::map<std::string, int> special = {
              {"MUTE",             1001},
              {"GUIDE",            1002},
              {"BACK",             1003},
              {"CHANNEL FORWARD",  1004},
              {"CHANNEL BACK",     1005},
              {"ON",               1006},
              {"OFF",              1006},
            };
            int val = special.count(x) ? special[x] : atoi(x.c_str());
            if (val < 1 || val > 9999) return;
            id(${s_name}_ir).make_call().set_value(val).perform();

    - topic: ${mqtt_name}/${s_name_upper} sensor/Reset CO2 Baseline/command
      then:
        - if:
            condition:
              lambda: 'return x == "ON";'
            then:
              - switch.turn_on: ${s_name}_coil_co2_reset
            else:
              - switch.turn_off: ${s_name}_coil_co2_reset

    - topic: ${mqtt_name}/${s_name_upper} sensor/Temperature Setpoint/command
      then:
        - number.set:
            id: ${s_name}_setpoint_temp
            value: !lambda |-
              if (x.empty()) return 0;
              return (int)atoi(x.c_str());

    - topic: ${mqtt_name}/${s_name_upper} sensor/CO2 Setpoint/command
      then:
        - number.set:
            id: ${s_name}_setpoint_co2
            value: !lambda |-
              if (x.empty()) return 0;
              return (int)atoi(x.c_str());

# ──────────────────────────────────────────────────────────────
#  INPUT REGISTERS — FC04 (read only)
#  All sensors include a zero filter (register=0 → bad read) and a
#  range filter: values outside the plausible range are discarded
#  (return {}) — the entity keeps its last valid state.
#  After 3 consecutive bad readings the filter publishes NaN
#  so Home Assistant marks the entity as "unavailable".
#  Note: lux and distance legitimately can be 0 — no zero filter there.
# ──────────────────────────────────────────────────────────────
sensor:

  # ── reg[0] — Temperature (BME280) ─────────────────────────
  - platform: modbus_controller
    modbus_controller_id: ${s_controller_id}
    name: "${s_name_upper} Temperature"
    id: ${s_name}_temp
    register_type: read
    address: 0
    value_type: U_WORD
    filters:
      - multiply: 0.1
      - lambda: |-
          static int bad = 0;
          if (x == 0.0) return {};
          if (x < -10.0 || x > 80.0) { if (++bad > 3) return NAN; return {}; }
          bad = 0; return x;
    unit_of_measurement: "°C"
    accuracy_decimals: 1
    qos: 1
    retain: true
    state_topic: ${mqtt_name}/${s_name_upper} sensor/Temperature/state
    web_server:
      sorting_group_id: ${s_name}
      sorting_weight: 1

  # ── reg[1] — Humidity (BME280) ────────────────────────────
  - platform: modbus_controller
    modbus_controller_id: ${s_controller_id}
    name: "${s_name_upper} Humidity"
    id: ${s_name}_hum
    register_type: read
    address: 1
    value_type: U_WORD
    filters:
      - multiply: 0.1
      - lambda: |-
          static int bad = 0;
          if (x == 0.0) return {};
          if (x < 0.0 || x > 100.0) { if (++bad > 3) return NAN; return {}; }
          bad = 0; return x;
    unit_of_measurement: "%"
    accuracy_decimals: 1
    qos: 1
    retain: true
    state_topic: ${mqtt_name}/${s_name_upper} sensor/Humidity/state
    web_server:
      sorting_group_id: ${s_name}
      sorting_weight: 2
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

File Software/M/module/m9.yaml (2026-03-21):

# ============================================================================
#
# M9 MODULE BASIC DESIGN FOR BASIC FUNCTIONS
#
# Adapt the configurations, names and other to your needs
#
# ============================================================================
esphome:
  on_boot:
    priority: -100
    then:
      - text_sensor.template.publish:
          id: valve_status
          state: "Idle"
      - sprinkler.set_multiplier:
          id: m9${m9_number_1}_sprinkler
          multiplier: 60

mqtt:
  on_message:
    - topic: ${mqtt_name}/${m9_name}${m9_number_1}/${m9_description_upper}/${m9_valve_description} 1/command
      then:
        - if:
            condition:
              lambda: 'return x == "ON";'
            then:
              - switch.turn_on: m9${m9_number_1}_valve_1
            else:
              - switch.turn_off: m9${m9_number_1}_valve_1
    - topic: ${mqtt_name}/${m9_name}${m9_number_1}/${m9_description_upper}/${m9_valve_description} 2/command
      then:
        - if:
            condition:
              lambda: 'return x == "ON";'
            then:
              - switch.turn_on: m9${m9_number_1}_valve_2
            else:
              - switch.turn_off: m9${m9_number_1}_valve_2
    - topic: ${mqtt_name}/${m9_name}${m9_number_1}/${m9_description_upper}/${m9_valve_description} 3/command
      then:
        - if:
            condition:
              lambda: 'return x == "ON";'
            then:
              - switch.turn_on: m9${m9_number_1}_valve_3
            else:
              - switch.turn_off: m9${m9_number_1}_valve_3       
    - topic: ${mqtt_name}/${m9_name}${m9_number_1}/${m9_description_upper}/${m9_valve_description} 4/command
      then:
        - if:
            condition:
              lambda: 'return x == "ON";'
            then:
              - switch.turn_on: m9${m9_number_1}_valve_4
            else:
              - switch.turn_off: m9${m9_number_1}_valve_4    
    - topic: ${mqtt_name}/${m9_name}${m9_number_1}/${m9_description_upper}/${m9_valve_description} 5/command
      then:
        - if:
            condition:
              lambda: 'return x == "ON";'
            then:
              - switch.turn_on: m9${m9_number_1}_valve_5
            else:
              - switch.turn_off: m9${m9_number_1}_valve_5                               
    - topic: ${mqtt_name}/${m9_name}${m9_number_1}/${m9_description_upper}/${m9_valve_description} 6/command
      then:
        - if:
            condition:
              lambda: 'return x == "ON";'
            then:
              - switch.turn_on: m9${m9_number_1}_valve_6
            else:
              - switch.turn_off: m9${m9_number_1}_valve_6
    - topic: ${mqtt_name}/${m9_name}${m9_number_1}/${m9_description_upper}/${m9_valve_description} 7/command
      then:
        - if:
            condition:
              lambda: 'return x == "ON";'
            then:
              - switch.turn_on: m9${m9_number_1}_valve_7
            else:
              - switch.turn_off: m9${m9_number_1}_valve_7
    - topic: ${mqtt_name}/${m9_name}${m9_number_1}/${m9_description_upper}/${m9_valve_description} 8/command
      then:
        - if:
            condition:
              lambda: 'return x == "ON";'
            then:
              - switch.turn_on: m9${m9_number_1}_valve_8
            else:
              - switch.turn_off: m9${m9_number_1}_valve_8
    - topic: ${mqtt_name}/${m9_name}${m9_number_1}/${m9_description_upper}/Pause/command
      then:
        - if:
            condition:
              lambda: 'return x == "ON";'
            then:
              - button.press: irrigation_pause
    - topic: "${mqtt_name}/${m9_name}${m9_number_1}/${m9_description_upper}/${m9_valve_description} 1/Duration/command"
      then:
        - number.set:
            id: valve_1
            value: !lambda |-
              float v = atof(x.c_str());
              if (v < id(valve_time_min))
                  v = id(valve_time_min);
              if (v > id(valve_time_max))
                  v = id(valve_time_max);
              return v;
    - topic: "${mqtt_name}/${m9_name}${m9_number_1}/${m9_description_upper}/${m9_valve_description} 2/Duration/command"
      then:
        - number.set:
            id: valve_2
            value: !lambda |-
              float v = atof(x.c_str());
              if (v < id(valve_time_min))
                  v = id(valve_time_min);
              if (v > id(valve_time_max))
                  v = id(valve_time_max);
              return v;
    - topic: "${mqtt_name}/${m9_name}${m9_number_1}/${m9_description_upper}/${m9_valve_description} 3/Duration/command"
      then:
        - number.set:
            id: valve_3
            value: !lambda |-
              float v = atof(x.c_str());
              if (v < id(valve_time_min))
                  v = id(valve_time_min);
              if (v > id(valve_time_max))
                  v = id(valve_time_max);
              return v;
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

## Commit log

2026-02-15 Update README with assembly steps and directory names
    Reordered assembly steps for clarity and corrected directory name for 3D models.
2026-02-15 Clean up README by removing redundant images
    Removed unnecessary image divs and consolidated relay module images.
2026-02-16 Revise README for DOMIX M3 CONTACT module
    Updated the dimensions and details of the DOMIX M3 CONTACT module, including system architecture, power supply, user interface, and mechanical structure.
2026-02-16 Update README.md for Module M4 6 RELAY
